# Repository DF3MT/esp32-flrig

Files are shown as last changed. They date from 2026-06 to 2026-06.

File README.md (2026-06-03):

<p align="center">
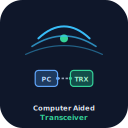
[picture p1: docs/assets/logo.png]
ESP32 Computer Aided Transceiver Panel
  
</p>

<h1 align="center">ESP32 CAT Remote Panel</h1>

<p align="center"><sub><strong><a href="https://en.wikipedia.org/wiki/Computer_Aided_Transceiver">CAT</a></strong> = <a href="https://en.wikipedia.org/wiki/Computer_Aided_Transceiver">Computer Aided Transceiver</a> (not Caterpillar)</sub></p>

<p align="center">
  <a href="#deutsch">🇩🇪 Deutsch</a> ·
  <a href="#english">🇬🇧 English</a>
</p>

<p align="center">
  <strong>DE:</strong> Funkfernbedienung mit Touch-Display, <a href="https://en.wikipedia.org/wiki/Computer_Aided_Transceiver">CAT</a>, <a href="https://de.wikipedia.org/wiki/WLAN">WiFi</a>-Audio, <a href="https://de.wikipedia.org/wiki/FT8_(Amateurfunk)">FT8</a> · bis zu <strong>3× Funk + <a href="https://de.wikipedia.org/wiki/Rotor_(Antenne)">Rotor</a></strong><br>
  <strong>EN:</strong> <a href="https://en.wikipedia.org/wiki/Amateur_radio">Ham radio</a> remote panel with touch UI, <a href="https://en.wikipedia.org/wiki/Computer_Aided_Transceiver">CAT</a>, <a href="https://en.wikipedia.org/wiki/Wi-Fi">WiFi</a> audio, <a href="https://en.wikipedia.org/wiki/FT8_(digital_mode)">FT8</a> · up to <strong>3× radios + <a href="https://en.wikipedia.org/wiki/Antenna_rotator">rotor</a></strong>
</p>

<p align="center">
  <a href="https://de.wikipedia.org/wiki/Icom">ICOM</a> <a href="https://de.wikipedia.org/wiki/CI-V">CI-V</a> · <a href="https://de.wikipedia.org/wiki/Yaesu">Yaesu</a> <a href="https://en.wikipedia.org/wiki/Computer_Aided_Transceiver">CAT</a> · <a href="https://www.xiegu.com/">Xiegu</a> · <a href="https://github.com/w1hkj/flrig">flrig</a> · <a href="https://physics.princeton.edu/pulsar/k1jt/wsjtx.html">WSJT-X</a> · <a href="https://en.wikipedia.org/wiki/Hamlib">Hamlib</a> <a href="https://hamlib.sourceforge.net/html/rigctld.1.html">rigctld</a> · <a href="https://hamlib.sourceforge.net/html/rotctld.1.html">rotctld</a>
</p>

<p align="center">
  <a href="#deutsch">📖 DE</a> ·
  <a href="#english">📖 EN</a> ·
  <a href="docs/GUIDE_DE.md">Leitfaden (DE)</a> ·
  <a href="hardware/esp32-flrig-shield/README.md">🛠️ PCB</a> ·
  <a href="docs/RADIOS.md">📻 Radios</a> ·
  <a href="docs/ISOLATION.md">🔌 Isolation</a> ·
  <a href="docs/MULTI_RADIO_DE.md">📡 3× DE</a> ·
  <a href="docs/MULTI_RADIO_EN.md">📡 3× EN</a> ·
  <a href="docs/GLOSSARY.md">📚 Glossar</a> ·
  <a href="flasher/index.html">⚡ Flasher</a>
</p>

<p align="center">
  
  
  
  
  
  
</p>

<p align="center">
  System overview
</p>

---

## Deutsch

### Was ist das?

Ein **[ESP32](https://de.wikipedia.org/wiki/ESP32)-Panel** (z. B. [Cheap Yellow Display](https://github.com/witnessmenow/ESP32-Cheap-Yellow-Display)) oder **[ESP32-S3](https://www.espressif.com/en/products/socs/esp32-s3) + Interface-Shield** steuert bis zu **drei [Funkgeräten](https://de.wikipedia.org/wiki/Transceiver) gleichzeitig** über **[WiFi](https://de.wikipedia.org/wiki/WLAN)**:

| Kanal | Anbindung | [CAT](https://en.wikipedia.org/wiki/Computer_Aided_Transceiver) → PC | Audio → PC (eigenes [UDP](https://de.wikipedia.org/wiki/User_Datagram_Protocol)-Paar) |
|---|---|---|---|
| **A** | [RJ45](https://de.wikipedia.org/wiki/RJ-45) / [I2S](https://de.wikipedia.org/wiki/I%C2%B2S) | `:4532` | `4533` / `4534` |
| **B** | [USB-A](https://de.wikipedia.org/wiki/USB) J5 | `:4536` | `4538` / `4539` |
| **C** | [USB](https://de.wikipedia.org/wiki/Universal_Serial_Bus)-A J6 | `:4540` | `4541` / `4542` |
| **[Rotor](https://de.wikipedia.org/wiki/Rotor_(Antenne))** | [GPIO](https://de.wikipedia.org/wiki/General_Purpose_Input/Output) | `:4535` | — |

Ideal für **[FT8](https://de.wikipedia.org/wiki/FT8_(Amateurfunk))/[WSJT-X](https://physics.princeton.edu/pulsar/k1jt/wsjtx.html)** am PC ohne [USB-Kabel](https://de.wikipedia.org/wiki/Universal_Serial_Bus) zum Funk. Shield **Rev C** trennt die **Masse jedes Funkgeräts [galvanisch](https://de.wikipedia.org/wiki/Galvanische_Trennung)** ([Isolation](docs/ISOLATION.md)).

**3 [Funkgeräte](https://de.wikipedia.org/wiki/Transceiver)** = am PC **3 parallele, unabhängige** Ketten (je ein [rigctld](https://hamlib.sourceforge.net/html/rigctld.1.html)-[TCP](https://de.wikipedia.org/wiki/Transmission_Control_Protocol)-Port + ein Audio-[UDP](https://de.wikipedia.org/wiki/User_Datagram_Protocol)-Paar + eigenes PC-Audiogerät, z. B. [VB-Cable](https://vb-audio.com/Cable/) A/B/C). Der ESP mischt die Streams **nicht**.

**[CAT](https://en.wikipedia.org/wiki/Computer_Aided_Transceiver)** = **[Computer Aided Transceiver](https://en.wikipedia.org/wiki/Computer_Aided_Transceiver)** (Steuerprotokoll, z. B. [CI-V](https://de.wikipedia.org/wiki/CI-V) / [Yaesu CAT](https://en.wikipedia.org/wiki/Computer_Aided_Transceiver)).

| PC-Instanz | [rigctld](https://hamlib.sourceforge.net/html/rigctld.1.html) ([CAT](https://en.wikipedia.org/wiki/Computer_Aided_Transceiver)) | Audio RX / TX ([UDP](https://de.wikipedia.org/wiki/User_Datagram_Protocol)) | Web |
|---|---|---|-----|
| Funk A | **4532** | **4533** / **4534** | `/audio` |
| Funk B | **4536** | **4538** / **4539** | `/audio_b` |
| Funk C | **4540** | **4541** / **4542** | `/audio_c` |
| [Rotor](https://de.wikipedia.org/wiki/Rotor_(Antenne)) | **4535** ([rotctld](https://hamlib.sourceforge.net/html/rotctld.1.html)) | — | — |

Details: [MULTI_RADIO_DE.md](docs/MULTI_RADIO_DE.md) · Beispiel-Konfig: [ft8_config.example-3radio.json](scripts/ft8_config.example-3radio.json)

### Unterstützte [Funkgeräte](https://de.wikipedia.org/wiki/Transceiver)

| Hersteller | Modelle |
|---|---|
| **[Xiegu](https://www.xiegu.com/)** | G90, [X6100](https://www.xiegu.com/), [X6200](https://www.xiegu.com/) |
| **[Yaesu](https://de.wikipedia.org/wiki/Yaesu)** | FT-991A, FT-910, FT-DX10, FT-DX101D/MP, FT-891, FT-897, FT-857 |
| Referenz | [ICOM](https://de.wikipedia.org/wiki/Icom) IC-7300 |

Profil in der Web-UI → Baudrate & Protokoll automatisch: [RADIOS.md](docs/RADIOS.md)

### Schnellstart

**Firmware (1× Funk, [CYD](https://github.com/witnessmenow/ESP32-Cheap-Yellow-Display)):**

```bash
pio run -e esp32-cyd -t upload
pio run -e esp32-cyd -t uploadfs
```

**Firmware (3× Funk + [Rotor](https://de.wikipedia.org/wiki/Rotor_(Antenne)), Shield Rev C + [ESP32-S3](https://www.espressif.com/en/products/socs/esp32-s3)):**

```bash
pio run -e esp32-flrig-shield -t upload
pio run -e esp32-flrig-shield -t uploadfs
```

Oder **[Web-Flasher](flasher/index.html)** im Browser.

| Modus | [SSID](https://de.wikipedia.org/wiki/Service_Set_Identifier) / IP | Konfiguration |
|---|---|---|
| AP (Werk) | `ESP32-CAT-Panel` / `192.168.4.1` | http://192.168.4.1/ |
| [WLAN](https://de.wikipedia.org/wiki/WLAN) | [DHCP](https://de.wikipedia.org/wiki/Dynamic_Host_Configuration_Protocol) | Funkprofil wählen |

**[CAT](https://en.wikipedia.org/wiki/Computer_Aided_Transceiver) testen ([Computer Aided Transceiver](https://en.wikipedia.org/wiki/Computer_Aided_Transceiver)):**

```bash
rigctl -m 2 -r 192.168.4.1:4532 f    # Funk A
rigctl -m 2 -r 192.168.4.1:4536 f    # Funk B
rigctl -m 2 -r 192.168.4.1:4540 f    # Funk C
rotctl -m 2 -r 192.168.4.1:4535 p    # Rotor
```

### [Rotor](https://de.wikipedia.org/wiki/Rotor_(Antenne)) ([Hamlib](https://en.wikipedia.org/wiki/Hamlib) [rotctld](https://hamlib.sourceforge.net/html/rotctld.1.html))

Zwei **Taster** (Azimut) und zwei **[Open-Collector](https://de.wikipedia.org/wiki/Offener_Kollektor)-Ausgänge** für Relais ([NPN](https://de.wikipedia.org/wiki/Bipolartransistor) + [Freilaufdiode](https://de.wikipedia.org/wiki/Freilaufdiode) extern).

| Richtung (`M`) | Wert | OC-[GPIO](https://de.wikipedia.org/wiki/General_Purpose_Input/Output) ([CYD](https://github.com/witnessmenow/ESP32-Cheap-Yellow-Display)) |
|---|---|---|
| Links (CCW) | 8 | **18** |
| Rechts (CW) | 16 | **19** |
| Taster CCW / CW | — | **27** / **5** |

`OUTPUT_OPEN_DRAIN`: **LOW** = Relais ein. Port **4535** (nicht 4533 — Audio-[UDP](https://de.wikipedia.org/wiki/User_Datagram_Protocol)).

### Interface-Shield (Dokumentation)

| Dokument | Inhalt |
|---|---|
| [Shield README](hardware/esp32-flrig-shield/README.md#deutsch) | Übersicht (DE/EN) |
| [Schaltplan](hardware/esp32-flrig-shield/docs/SCHEMATIC.md) | Logik, Isolation |
| [Kabel](hardware/esp32-flrig-shield/docs/CABLE_ASSEMBLY.md) | RJ45 / Funk |
| [RJ45-Pinout](hardware/esp32-flrig-shield/docs/RJ45_PINOUT.md) | Steckerbelegung |

### [FT8](https://de.wikipedia.org/wiki/FT8_(Amateurfunk)) / [WSJT-X](https://physics.princeton.edu/pulsar/k1jt/wsjtx.html)

```bash
pip install -r scripts/requirements-ft8.txt
cp scripts/ft8_config.example.json ~/.config/esp32-flrig/ft8.json
python3 scripts/ft8_setup.py --config ~/.config/esp32-flrig/ft8.json --test-cat --start
```

| OS | Skript |
|----|---|
| [Linux](https://de.wikipedia.org/wiki/Linux) | `./scripts/ft8_setup.sh 192.168.4.1 --pa --start` |
| [Windows](https://de.wikipedia.org/wiki/Microsoft_Windows) | `.\scripts\ft8_windows_setup.ps1 -EspHost 192.168.4.1 -InstallVbCable -StartBridge` |

### Hardware ([CYD](https://github.com/witnessmenow/ESP32-Cheap-Yellow-Display), Kanal A)

| Signal | [GPIO](https://de.wikipedia.org/wiki/General_Purpose_Input/Output) |
|---|---|
| [CAT](https://en.wikipedia.org/wiki/Computer_Aided_Transceiver) RX / TX | 16 / 17 |
| [I2S](https://de.wikipedia.org/wiki/I%C2%B2S) BCLK / LRCK | 26 / 25 |
| [I2S](https://de.wikipedia.org/wiki/I%C2%B2S) DOUT / DIN | 22 / 4 |
| [Potis](https://de.wikipedia.org/wiki/Potentiometer) 1–5 | 32, 35, 34, 39, 36 |
| [Rotor](https://de.wikipedia.org/wiki/Rotor_(Antenne)) Taster / OC | 27, 5 / 18, 19 |

### Weitere Dokumentation

| Thema | Link |
|---|---|
| Ausführlicher Leitfaden | [GUIDE_DE.md](docs/GUIDE_DE.md) (Deutsch) |
| [Hamlib](https://en.wikipedia.org/wiki/Hamlib) [rigctld](https://hamlib.sourceforge.net/html/rigctld.1.html) / [rotctld](https://hamlib.sourceforge.net/html/rotctld.1.html) | [rigctld](https://hamlib.sourceforge.net/html/rigctld.1.html) · [rotctld](https://hamlib.sourceforge.net/html/rotctld.1.html) |
| Audio-Monitor | http://\<ESP-IP\>/audio |

---

## English

### What is this?

An **[ESP32](https://en.wikipedia.org/wiki/ESP32) panel** (e.g. [Cheap Yellow Display](https://github.com/witnessmenow/ESP32-Cheap-Yellow-Display)) or **[ESP32-S3](https://www.espressif.com/en/products/socs/esp32-s3) + interface shield** controls up to **three [transceivers](https://en.wikipedia.org/wiki/Transceiver) at once** over **[WiFi](https://en.wikipedia.org/wiki/Wi-Fi)**:

| Channel | Connection | [CAT](https://en.wikipedia.org/wiki/Computer_Aided_Transceiver) → PC | Audio → PC (own [UDP](https://en.wikipedia.org/wiki/User_Datagram_Protocol) pair) |
|---|---|---|---|
| **A** | [RJ45](https://en.wikipedia.org/wiki/Registered_jack) / [I2S](https://en.wikipedia.org/wiki/I%C2%B2S) | `:4532` | `4533` / `4534` |
| **B** | [USB-A](https://en.wikipedia.org/wiki/USB) J5 | `:4536` | `4538` / `4539` |
| **C** | [USB](https://en.wikipedia.org/wiki/USB)-A J6 | `:4540` | `4541` / `4542` |
| **[Rotor](https://en.wikipedia.org/wiki/Antenna_rotator)** | [GPIO](https://en.wikipedia.org/wiki/General-purpose_input/output) | `:4535` | — |

Built for **[FT8](https://en.wikipedia.org/wiki/FT8_(digital_mode))/[WSJT-X](https://physics.princeton.edu/pulsar/k1jt/wsjtx.html)** on a PC without [USB cables](https://en.wikipedia.org/wiki/USB) to each radio. Shield **Rev C** uses **[galvanic isolation](https://en.wikipedia.org/wiki/Galvanic_isolation)** per radio ([ISOLATION.md](docs/ISOLATION.md)).

**3 radios** = on the PC **3 parallel, independent** chains (one [rigctld](https://hamlib.sourceforge.net/html/rigctld.1.html) [TCP](https://en.wikipedia.org/wiki/Transmission_Control_Protocol) port + one audio [UDP](https://en.wikipedia.org/wiki/User_Datagram_Protocol) pair + separate PC audio device each, e.g. [VB-Cable](https://vb-audio.com/Cable/) A/B/C). The ESP does **not** mix streams.

**[CAT](https://en.wikipedia.org/wiki/Computer_Aided_Transceiver)** = **[Computer Aided Transceiver](https://en.wikipedia.org/wiki/Computer_Aided_Transceiver)** (control protocol) — not construction equipment.

| PC instance | [rigctld](https://hamlib.sourceforge.net/html/rigctld.1.html) ([CAT](https://en.wikipedia.org/wiki/Computer_Aided_Transceiver)) | Audio RX / TX ([UDP](https://en.wikipedia.org/wiki/User_Datagram_Protocol)) | Web |
|---|---|---|-----|
| Radio A | **4532** | **4533** / **4534** | `/audio` |
| Radio B | **4536** | **4538** / **4539** | `/audio_b` |
| Radio C | **4540** | **4541** / **4542** | `/audio_c` |
| [Rotor](https://en.wikipedia.org/wiki/Antenna_rotator) | **4535** ([rotctld](https://hamlib.sourceforge.net/html/rotctld.1.html)) | — | — |

Details: [MULTI_RADIO_EN.md](docs/MULTI_RADIO_EN.md) · Example config: [ft8_config.example-3radio.json](scripts/ft8_config.example-3radio.json)

### Supported radios

| Vendor | Models |
|---|---|
| **[Xiegu](https://www.xiegu.com/)** | G90, X6100, X6200 |
| **[Yaesu](https://en.wikipedia.org/wiki/Yaesu_(brand))** | FT-991A, FT-910, FT-DX10, FT-DX101D/MP, FT-891, FT-897, FT-857 |
| Reference | [ICOM](https://en.wikipedia.org/wiki/Icom) IC-7300 |

Select a profile in the web UI: [RADIOS.md](docs/RADIOS.md)

### Quick start

**Firmware (single radio, [CYD](https://github.com/witnessmenow/ESP32-Cheap-Yellow-Display)):**

```bash
pio run -e esp32-cyd -t upload
pio run -e esp32-cyd -t uploadfs
```

**Firmware (3 radios + [rotor](https://en.wikipedia.org/wiki/Antenna_rotator), Shield Rev C + [ESP32-S3](https://www.espressif.com/en/products/socs/esp32-s3)):**

```bash
pio run -e esp32-flrig-shield -t upload
pio run -e esp32-flrig-shield -t uploadfs
```

Or the **[Web Flasher](flasher/index.html)** in your browser.

| Mode | [SSID](https://en.wikipedia.org/wiki/Service_set_(802.11_network)) / IP | Config |
|---|---|---|
| AP (default) | `ESP32-CAT-Panel` / `192.168.4.1` | http://192.168.4.1/ |
| [WiFi](https://en.wikipedia.org/wiki/Wi-Fi) STA | [DHCP](https://en.wikipedia.org/wiki/Dynamic_Host_Configuration_Protocol) | Select radio profile |

**Test [CAT](https://en.wikipedia.org/wiki/Computer_Aided_Transceiver) ([Computer Aided Transceiver](https://en.wikipedia.org/wiki/Computer_Aided_Transceiver)):**

```bash
rigctl -m 2 -r 192.168.4.1:4532 f    # Radio A
rigctl -m 2 -r 192.168.4.1:4536 f    # Radio B
rigctl -m 2 -r 192.168.4.1:4540 f    # Radio C
rotctl -m 2 -r 192.168.4.1:4535 p    # Rotor
```

### [Rotor](https://en.wikipedia.org/wiki/Antenna_rotator) ([Hamlib](https://en.wikipedia.org/wiki/Hamlib) [rotctld](https://hamlib.sourceforge.net/html/rotctld.1.html))

Two **buttons** (azimuth) and two **[open-collector](https://en.wikipedia.org/wiki/Open_collector)** outputs for relays (external [NPN](https://en.wikipedia.org/wiki/Bipolar_junction_transistor) + [flyback diode](https://en.wikipedia.org/wiki/Flyback_diode)).

| Direction (`M`) | Value | OC [GPIO](https://en.wikipedia.org/wiki/General-purpose_input/output) ([CYD](https://github.com/witnessmenow/ESP32-Cheap-Yellow-Display)) |
|---|---|---|
| Left (CCW) | 8 | **18** |
| Right (CW) | 16 | **19** |
| Buttons CCW / CW | — | **27** / **5** |

`OUTPUT_OPEN_DRAIN`: **LOW** = relay on. Port **4535** (not 4533 — audio [UDP](https://en.wikipedia.org/wiki/User_Datagram_Protocol)).

### Interface shield (documentation)

| Document | Content |
|---|---|
| [Shield README](hardware/esp32-flrig-shield/README.md#english) | Overview (DE/EN) |
| [Schematic](hardware/esp32-flrig-shield/docs/SCHEMATIC.md) | Logic, isolation |
| [Cables](hardware/esp32-flrig-shield/docs/CABLE_ASSEMBLY.md) | RJ45 / radio |
| [RJ45 pinout](hardware/esp32-flrig-shield/docs/RJ45_PINOUT.md) | Connector pins |

### [FT8](https://en.wikipedia.org/wiki/FT8_(digital_mode)) / [WSJT-X](https://physics.princeton.edu/pulsar/k1jt/wsjtx.html)

```bash
pip install -r scripts/requirements-ft8.txt
cp scripts/ft8_config.example.json ~/.config/esp32-flrig/ft8.json
python3 scripts/ft8_setup.py --config ~/.config/esp32-flrig/ft8.json --test-cat --start
```

| OS | Script |
|----|---|
| [Linux](https://en.wikipedia.org/wiki/Linux) | `./scripts/ft8_setup.sh 192.168.4.1 --pa --start` |
| [Windows](https://en.wikipedia.org/wiki/Microsoft_Windows) | `.\scripts\ft8_windows_setup.ps1 -EspHost 192.168.4.1 -InstallVbCable -StartBridge` |

### Hardware ([CYD](https://github.com/witnessmenow/ESP32-Cheap-Yellow-Display), channel A)

| Signal | [GPIO](https://en.wikipedia.org/wiki/General-purpose_input/output) |
|---|---|
| [CAT](https://en.wikipedia.org/wiki/Computer_Aided_Transceiver) RX / TX | 16 / 17 |
| [I2S](https://en.wikipedia.org/wiki/I%C2%B2S) BCLK / LRCK | 26 / 25 |
| [I2S](https://en.wikipedia.org/wiki/I%C2%B2S) DOUT / DIN | 22 / 4 |
| Pots 1–5 | 32, 35, 34, 39, 36 |
| [Rotor](https://en.wikipedia.org/wiki/Antenna_rotator) buttons / OC | 27, 5 / 18, 19 |

[CAT](https://en.wikipedia.org/wiki/Computer_Aided_Transceiver) on [CYD](https://github.com/witnessmenow/ESP32-Cheap-Yellow-Display): **3.3 V [TTL](https://en.wikipedia.org/wiki/Transistor%E2%80%93transistor_logic)**; on the shield **[ISO7741](https://www.ti.com/product/ISO7741)** isolates [RJ45](https://en.wikipedia.org/wiki/Registered_jack) [CAT](https://en.wikipedia.org/wiki/Computer_Aided_Transceiver) from ESP ground.

### Project layout

```
esp32-flrig/
├── docs/              Guides, radio list, isolation
├── hardware/esp32-flrig-shield/
│   ├── docs/          Schematic, cables, RJ45
│   └── assets/        Block diagram
├── scripts/           FT8 setup (Linux / Windows)
├── src/               Firmware
└── flasher/           Browser flasher
```

### Architecture

```
┌─────────────┐  rigctld :4532/4536/4540   ┌──────────────┐  isolated   ┌─────────┐
│ WSJT-X/flrig│◄──────────────────────────►│ ESP32 Panel  │◄───────────►│ 3× Radio│
└─────────────┘                            │ rotctld :4535│             └─────────┘
┌─────────────┐  rotctl                    │ WiFi audio   │
│ rotctl      │◄──────────────────────────►│ Touch + Web  │
└─────────────┘                            └──────────────┘
```

### More links

| Topic | Link |
|---|---|
| Full guide | [GUIDE_DE.md](docs/GUIDE_DE.md) (German) |
| [Hamlib](https://en.wikipedia.org/wiki/Hamlib) [rigctld](https://hamlib.sourceforge.net/html/rigctld.1.html) / [rotctld](https://hamlib.sourceforge.net/html/rotctld.1.html) | [rigctld](https://hamlib.sourceforge.net/html/rigctld.1.html) · [rotctld](https://hamlib.sourceforge.net/html/rotctld.1.html) |
| Audio monitor | http://\<ESP-IP\>/audio |

---

<p align="center">
  <sub>License: see repository · Contributions welcome · <a href="#deutsch">🇩🇪</a> · <a href="#english">🇬🇧</a></sub>
</p>

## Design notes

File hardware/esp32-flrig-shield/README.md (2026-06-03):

# ESP32-FLRIG Interface Shield

<p align="center">
  <a href="#deutsch">🇩🇪 Deutsch</a> ·
  <a href="#english">🇬🇧 English</a>
</p>

<p align="center">
  <sub><strong><a href="https://en.wikipedia.org/wiki/Computer_Aided_Transceiver">CAT</a></strong> = <a href="https://en.wikipedia.org/wiki/Computer_Aided_Transceiver">Computer Aided Transceiver</a></sub>
</p>

Blockdiagramm

---

## Deutsch

### Übersicht

Dokumentation für ein **Interface-Shield** zwischen **[ESP32-S3](https://www.espressif.com/en/products/socs/esp32-s3)** ([USB-Host](https://de.wikipedia.org/wiki/USB)) bzw. optional **[CYD](https://github.com/witnessmenow/ESP32-Cheap-Yellow-Display)** (nur Funk **Kanal A**) und bis zu **drei Funkgeräten**:

| Anschluss | Funktion |
|---|---|
| **J1 [RJ45](https://de.wikipedia.org/wiki/RJ-45)** | Funk **A**: +5 V, **[CAT](https://en.wikipedia.org/wiki/Computer_Aided_Transceiver)** ([UART](https://de.wikipedia.org/wiki/Asynchrone_Serielle_Schnittstelle)), **Line-Audio** |
| **J5 / J6** | **[USB-A](https://de.wikipedia.org/wiki/USB) Buchse** — Funk **B** und **C** ([CAT](https://en.wikipedia.org/wiki/Computer_Aided_Transceiver) + Audio per [USB](https://de.wikipedia.org/wiki/Universal_Serial_Bus)) |
| **U5 [USB2422](https://www.microchip.com/en-us/product/USB2422)** | 2-Port-Hub, Upstream **J3** → [ESP32-S3](https://www.espressif.com/en/products/socs/esp32-s3) OTG |
| **J7 / J3** | **[Rotor](https://de.wikipedia.org/wiki/Rotor_(Antenne))** (2× Taster, 2× [Open-Collector](https://de.wikipedia.org/wiki/Offener_Kollektor)) |
| **J2** | 2×10 für **[CYD](https://github.com/witnessmenow/ESP32-Cheap-Yellow-Display)** (Kanal A + [I2S](https://de.wikipedia.org/wiki/I%C2%B2S)) |

- **U1 [ISO7741](https://www.ti.com/product/ISO7741)** — [CAT](https://en.wikipedia.org/wiki/Computer_Aided_Transceiver) [galvanisch getrennt](https://de.wikipedia.org/wiki/Galvanische_Trennung) ([RJ45](https://de.wikipedia.org/wiki/RJ-45))  
- **U6/U7 [ADuM4160](https://www.analog.com/en/products/adum4160.html)** — [USB](https://de.wikipedia.org/wiki/Universal_Serial_Bus) [galvanisch](https://de.wikipedia.org/wiki/Galvanische_Trennung) getrennt (Funk B/C)  
- **T1/T2** — [Audio-Trafos](https://de.wikipedia.org/wiki/Transformator) (Funk A)  
- **[PCM5102](https://www.ti.com/product/PCM5102) + [INMP441](https://www.invensense.com/products/digital/inmp441/)** — [I2S](https://de.wikipedia.org/wiki/I%C2%B2S) (48 [kHz](https://de.wikipedia.org/wiki/Hertz))  

**3× Funk + 1× [Rotor](https://de.wikipedia.org/wiki/Rotor_(Antenne))** über **[WiFi](https://de.wikipedia.org/wiki/WLAN)**. **Keine gemeinsame Masse** zwischen den [Funkgeräten](https://de.wikipedia.org/wiki/Transceiver): [Isolation](../../docs/ISOLATION.md).

**Am PC:** drei getrennte [rigctld](https://hamlib.sourceforge.net/html/rigctld.1.html)-Verbindungen und drei Audio-[UDP](https://de.wikipedia.org/wiki/User_Datagram_Protocol)-Paare — siehe [MULTI_RADIO_DE.md](../../docs/MULTI_RADIO_DE.md).

### Dokumentation

| Thema | Datei |
|---|---|
| Logischer Schaltplan | [SCHEMATIC.md](docs/SCHEMATIC.md) |
| Kabel / RJ45 | [CABLE_ASSEMBLY.md](docs/CABLE_ASSEMBLY.md) · [RJ45_PINOUT.md](docs/RJ45_PINOUT.md) |
| Isolation | [ISOLATION.md](../../docs/ISOLATION.md) |

### Firmware

```bash
pio run -t upload -e esp32-flrig-shield
pio run -t uploadfs -e esp32-flrig-shield
```

### [Rotor](https://de.wikipedia.org/wiki/Rotor_(Antenne)) ([GPIO](https://de.wikipedia.org/wiki/General_Purpose_Input/Output))

| J7 / J3 | [GPIO](https://de.wikipedia.org/wiki/General_Purpose_Input/Output) (S3-Default) |
|---|---|
| Taster CCW | 27 |
| Taster CW | 5 |
| [Open Collector](https://de.wikipedia.org/wiki/Offener_Kollektor) CCW | 18 |
| [Open Collector](https://de.wikipedia.org/wiki/Offener_Kollektor) CW | 19 |

**[rotctld](https://hamlib.sourceforge.net/html/rotctld.1.html)** Port **4535**.

### Dateien

```
esp32-flrig-shield/
├── docs/     Schaltplan, Kabel, RJ45
└── assets/   Blockdiagramm (SVG)
```

---

## English

### Overview

Documentation for an **interface shield** between **[ESP32-S3](https://www.espressif.com/en/products/socs/esp32-s3)** ([USB host](https://en.wikipedia.org/wiki/USB)) or optionally **[CYD](https://github.com/witnessmenow/ESP32-Cheap-Yellow-Display)** (radio **channel A** only) and up to **three radios**:

| Connector | Function |
|---|---|
| **J1 [RJ45](https://en.wikipedia.org/wiki/Registered_jack)** | Radio **A**: +5 V, **[CAT](https://en.wikipedia.org/wiki/Computer_Aided_Transceiver)** ([UART](https://en.wikipedia.org/wiki/Universal_asynchronous_receiver-transmitter)), line audio |
| **J5 / J6** | **[USB Type-A](https://en.wikipedia.org/wiki/USB)** — radios **B** and **C** |
| **U5 [USB2422](https://www.microchip.com/en-us/product/USB2422)** | 2-port hub, upstream **J3** → [ESP32-S3](https://www.espressif.com/en/products/socs/esp32-s3) OTG |
| **J7 / J3** | **[Rotor](https://en.wikipedia.org/wiki/Antenna_rotator)** (2× buttons, 2× [open-collector](https://en.wikipedia.org/wiki/Open_collector)) |
| **J2** | 2×10 header for **[CYD](https://github.com/witnessmenow/ESP32-Cheap-Yellow-Display)** |

See [ISOLATION.md](../../docs/ISOLATION.md) and [MULTI_RADIO_EN.md](../../docs/MULTI_RADIO_EN.md).

### Documentation

| Topic | File |
|---|---|
| Logical schematic | [SCHEMATIC.md](docs/SCHEMATIC.md) |
| Cables / RJ45 | [CABLE_ASSEMBLY.md](docs/CABLE_ASSEMBLY.md) · [RJ45_PINOUT.md](docs/RJ45_PINOUT.md) |

### Firmware

```bash
pio run -t upload -e esp32-flrig-shield
pio run -t uploadfs -e esp32-flrig-shield
```

### [Rotor](https://en.wikipedia.org/wiki/Antenna_rotator) ([GPIO](https://en.wikipedia.org/wiki/General-purpose_input/output))

| J7 / J3 | GPIO (S3 default) |
|---|---|
| Button CCW | 27 |
| Button CW | 5 |
| [Open collector](https://en.wikipedia.org/wiki/Open_collector) CCW | 18 |
| [Open collector](https://en.wikipedia.org/wiki/Open_collector) CW | 19 |

**[rotctld](https://hamlib.sourceforge.net/html/rotctld.1.html)** port **4535**.

---

<p align="center">
  <sub><a href="#deutsch">🇩🇪</a> · <a href="#english">🇬🇧</a> · <a href="../../README.md">Project README</a></sub>
</p>

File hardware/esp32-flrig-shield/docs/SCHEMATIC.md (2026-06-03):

# Schaltplan — [ESP32](https://de.wikipedia.org/wiki/ESP32)-FLRIG Interface Shield (Rev C)

Logischer Schaltplan (Konzept — keine KiCad-/Gerber-Dateien im Repository).

Blockdiagramm

**Rev C** = Rev B + **galvanische Trennung** zwischen allen Funk-Massebereichen ([`../../../docs/ISOLATION.md`](../../../docs/ISOLATION.md)).

**[CAT](https://en.wikipedia.org/wiki/Computer_Aided_Transceiver)** = **[Computer Aided Transceiver](https://en.wikipedia.org/wiki/Computer_Aided_Transceiver)** (Steuerprotokoll), nicht „Caterpillar“.

## Masse-Domänen (kein gemeinsamer GND-Kupfer!)

| Netz | Verbindung |
|---|---|
| **GND_ESP** | [ESP32-S3](https://www.espressif.com/en/products/socs/esp32-s3)/[CYD](https://github.com/witnessmenow/ESP32-Cheap-Yellow-Display), U5 Hub Upstream, U1/U6/U7 Primärseite, [I2S](https://de.wikipedia.org/wiki/I%C2%B2S)-Module ESP-Seite |
| **GND_RADIO_A** | [RJ45](https://de.wikipedia.org/wiki/RJ-45) Pin 2/7, U1 Sekundärseite, T1/T2 Funk-Seite |
| **GND_USB_B** | J5 Shield/GND, U6 Sekundärseite, U8 DC/DC Ausgang |
| **GND_USB_C** | J6 Shield/GND, U7 Sekundärseite, U9 DC/DC Ausgang |

Zwischen diesen Netzen nur **Isolatoren** (und optional HF-RC am [RJ45](https://de.wikipedia.org/wiki/RJ-45)-Shield).

## Gesamtübersicht

```
                    ┌── GND_ESP ──────────────────────────────┐
Funk A RJ45 ── U1 ISO7741 ── CAT UART    T1/T2 ── AF (nur über Trafos)
     GND_RADIO_A (isoliert)                │
Funk B J5 ──── U6 ADuM4160 ◄── U5 Hub Down1 ── ESP USB OTG
     GND_USB_B + U8 B0505S VBUS
Funk C J6 ──── U7 ADuM4160 ◄── U5 Hub Down2
     GND_USB_C + U9 B0505S VBUS
Rotor J7 ───── direkt GPIO (gemeinsame ESP-Masse, kein Funk-GND)
```

## Funk A — [CAT](https://en.wikipedia.org/wiki/Computer_Aided_Transceiver) ([Computer Aided Transceiver](https://en.wikipedia.org/wiki/Computer_Aided_Transceiver))

**U1 [ISO7741](https://www.ti.com/product/ISO7741)** (ersetzt [TXS0102](https://www.ti.com/product/TXS0102) — kein reiner [Pegelwandler](https://de.wikipedia.org/wiki/Pegelwandler) mehr):

```
GPIO16/17 (ESP) ── ISO7741 Seite A ──║── Seite B ── RJ45 Pin 3/4 (CAT TTL Funk)
+3V3_ESP              GND_ESP          GND_RADIO_A      +5V_RADIO (RJ45 Pin1, lokaler Bezug)
```

Optional **5 V ↔ 3,3 V** auf **Funk-Seite** nur für kompatible Pegel — **ohne** GND-Brücke zur ESP-Masse.

## Funk A — Audio ([galvanisch getrennt](https://de.wikipedia.org/wiki/Galvanische_Trennung))

```
PCM5102 / INMP441 (ESP-Seite, GND_ESP) ── T1/T2 1:1 Audio-Trafo ── RJ45 Pin 5/6
```

Kein direkter DC-Pfad AF_IN/AF_OUT zwischen [I2S](https://de.wikipedia.org/wiki/I%C2%B2S)-Modulen und [RJ45](https://de.wikipedia.org/wiki/RJ-45).

## [USB](https://de.wikipedia.org/wiki/Universal_Serial_Bus) Funk B / C

```
ESP USB OTG ── U5 USB2422 (nur GND_ESP)
                 ├── Down1 ── U6 ADuM4160 ── J5 (USB-A)  GND_USB_B
                 └── Down2 ── U7 ADuM4160 ── J6 (USB-A)  GND_USB_C
U8/U9: isoliertes DC/DC (z. B. B0505S) +5V_BUS → VBUS je Port (Sekundär getrennt)
```

**Wichtig:** J5- und J6-**Masse nicht** mit [RJ45](https://de.wikipedia.org/wiki/RJ-45)-Masse oder ESP-Masse verbinden.

## Stromversorgung

- **+5V_BUS**: ESP-Shield / externes Netzteil (GND_REF = **GND_ESP** nur).
- **[RJ45](https://de.wikipedia.org/wiki/RJ-45) Pin 1**: bevorzugt nur **Funk-A-Sekundär** (Isolator, Trafos) — nicht als Rückleiter für [USB](https://de.wikipedia.org/wiki/Universal_Serial_Bus)-B/C.
- **≥2 A** empfohlen, wenn zwei isolierte [USB](https://de.wikipedia.org/wiki/Universal_Serial_Bus)-Ports laden.

## [Rotor](https://de.wikipedia.org/wiki/Rotor_(Antenne))

J7 → J3 [GPIO](https://de.wikipedia.org/wiki/General_Purpose_Input/Output) (Taster + OC). [Rotor](https://de.wikipedia.org/wiki/Rotor_(Antenne))-Relais-Masse **extern** mit eigenem Netzteil; **nicht** mit Funk-B/C-Masse verbunden, wenn Brummen vermieden werden soll.

## [RJ45](https://de.wikipedia.org/wiki/RJ-45) — Netzliste (Funk A, isoliert)

| [RJ45](https://de.wikipedia.org/wiki/RJ-45) | Netz |
|---|---|
| 1 | +5V_RADIO_A |
| 2 | GND_RADIO_A |
| 3 | CAT_TX_RADIO (nach U1) |
| 4 | CAT_RX_RADIO (nach U1) |
| 5 | AF_IN (nach T1) |
| 6 | AF_OUT (nach T2) |
| 7 | GND_RADIO_A |
| 8 | NC |

## [BOM](https://de.wikipedia.org/wiki/St%C3%BCckliste) Rev C

Kernbauteile: **U1 [ISO7741](https://www.ti.com/product/ISO7741)**, **U6/U7 [ADuM4160](https://www.analog.com/en/products/adum4160.html)**, **U8/U9 [B0505S](https://en.wikipedia.org/wiki/DC-to-DC_converter)**, **T1/T2 [Audio-Trafo](https://de.wikipedia.org/wiki/Transformator)**, **U5 [USB2422](https://www.microchip.com/en-us/product/USB2422)**, **U2 AMS1117**, **U3/U4** [I2S](https://de.wikipedia.org/wiki/I%C2%B2S)-Module.

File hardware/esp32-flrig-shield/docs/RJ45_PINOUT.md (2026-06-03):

# [RJ45](https://de.wikipedia.org/wiki/RJ-45) Pinbelegung — [ESP32](https://de.wikipedia.org/wiki/ESP32)-FLRIG-1

Ein **8-poliges Cat-5e/Cat-6-Kabel** (oder fertiges Patchkabel mit abisolierten Adern am Funk-Ende) verbindet die **Interface-Platine** am [ESP32](https://de.wikipedia.org/wiki/ESP32) mit einer **Aufschaltbox am [Funkgerät](https://de.wikipedia.org/wiki/Transceiver)** ([CAT](https://en.wikipedia.org/wiki/Computer_Aided_Transceiver) + Audio + optional Strom).

## Steckerbelegung (Buchse auf [PCB](https://de.wikipedia.org/wiki/Leiterplatte), Blick auf Kontakte, Kabel abgehend)

| Pin | Farbe (T568B) | Signal | Richtung | Beschreibung |
|-----|---|---|---|---|
| 1 | orange/weiß | **+5V** | → Platine | Versorgung (max. **500 mA**), [Polyfuse](https://de.wikipedia.org/wiki/Polymer-Schmelzsicherung) auf [PCB](https://de.wikipedia.org/wiki/Leiterplatte) |
| 2 | orange | **GND** | — | Masse Hauptstrom |
| 3 | grün/weiß | **CAT_TX_RADIO** | Radio → ESP | [TTL](https://de.wikipedia.org/wiki/Transistor-Transistor-Logik) vom Funk (5 V), über [Level-Shifter](https://de.wikipedia.org/wiki/Pegelwandler) zu GPIO16 RX |
| 4 | grün | **CAT_RX_RADIO** | ESP → Radio | [TTL](https://de.wikipedia.org/wiki/Transistor-Transistor-Logik) zum Funk (5 V), von GPIO17 TX über Shifter |
| 5 | blau/weiß | **AF_IN** | Radio → Platine | Empfangs-Audio (Line-Out Funk), AC-gekoppelt |
| 6 | blau | **AF_OUT** | Platine → Radio | Sende-Audio (Line-In / Data-In Funk), AC-gekoppelt |
| 7 | braun/weiß | **GND_AUDIO** | — | Audio-Referenz (mit Pin 2 auf Funkseite verbinden) |
| 8 | braun | **NC** | — | Reserve (z. B. später [PTT](https://de.wikipedia.org/wiki/Sende-Empfang-Umschaltung) oder +5V-Sense) |

> **Wichtig:** Das ist **kein** Ethernet-Port. Kein Netzwerk-Switch anschließen.

## Signalübersicht

```
                    RJ45-Kabel (ESP32-FLRIG-1)
  ┌─────────────┐                              ┌──────────────────┐
  │  Shield PCB │  Pin1 +5V ──────────────────│ 5V (ACC/USB/Netzteil)│
  │  + CYD      │  Pin2 GND ──────────────────│ GND                │
  │             │  Pin3 ◄── CAT_TX (Funk)     │ CAT Buchse RX/TX   │
  │             │  Pin4 ──► CAT_RX (Funk)     │                    │
  │             │  Pin5 ◄── Line OUT Funk     │ 3,5 mm Line Out    │
  │             │  Pin6 ──► Line IN Funk      │ 3,5 mm Line/Data In│
  └─────────────┘  Pin7 GND Audio ────────────└──────────────────┘
```

## [CAT](https://en.wikipedia.org/wiki/Computer_Aided_Transceiver) [TTL](https://de.wikipedia.org/wiki/Transistor-Transistor-Logik)

- **Kreuzverdrahtung** auf der Funk-Seite: Pin 3 = Funk-TX → ESP empfängt; Pin 4 = Funk-RX ← ESP sendet.
- Pegel: **5 V [TTL](https://de.wikipedia.org/wiki/Transistor-Transistor-Logik)** am Funk; auf der Platine **[TXS0102](https://www.ti.com/product/TXS0102)** (3,3 V ↔ 5 V).

## Audio

- Pegel: **Line-Level** (~0,1–1,5 Vpp), nicht Lautsprecher-Taps.
- Auf der Platine: Trennkondensatoren 10 µF, Spannungsteiler zum [I2S](https://de.wikipedia.org/wiki/I%C2%B2S)-ADC; DAC-Ausgang über 10 µF + optional 1 kΩ Reihenwiderstand.
- **Mono** (nur Pin 5/6); Stereo-[Funkgeräte](https://de.wikipedia.org/wiki/Transceiver): L-Kanal verwenden, R über 7 auf GND.

## Stromversorgung

| Variante | Hinweis |
|---|---|
| **A** | Pin 1/2 von **5 V am Funk** (ACC, [USB](https://de.wikipedia.org/wiki/Universal_Serial_Bus)-Port mit 500 mA) |
| **B** | Separates **5 V Netzteil** nur am [RJ45](https://de.wikipedia.org/wiki/RJ-45) (Funkseite Pins 3–8 trotzdem verbunden) |
| **C** | Zusätzlich **[USB](https://de.wikipedia.org/wiki/Universal_Serial_Bus)-C am [CYD](https://github.com/witnessmenow/ESP32-Cheap-Yellow-Display)** nur zum Flashen (nicht gleichzeitig mit externem 5 V auf Pin 1 ohne Diode) |

Empfehlung auf [PCB](https://de.wikipedia.org/wiki/Leiterplatte): **[Schottky](https://de.wikipedia.org/wiki/Schottky-Diode) D1** ([USB](https://de.wikipedia.org/wiki/Universal_Serial_Bus) 5 V OR extern 5 V) — siehe Schaltplan.

## Empfohlenes Kabel

- **Am Panel:** abgeschirmtes [RJ45](https://de.wikipedia.org/wiki/RJ-45)-Patchkabel (≤ 3 m).
- **Am Funk:** eigene **Verteilerdose** oder **Gehäuse** mit:
  - 1× [RJ45](https://de.wikipedia.org/wiki/RJ-45) Buchse
  - 1× [CAT](https://en.wikipedia.org/wiki/Computer_Aided_Transceiver)-Stecker (3,5 mm TRS oder 6P6C je nach Gerät)
  - 2× 3,5 mm mono oder 1× stereo für Audio
  - Beschriftung nach Tabelle oben

Siehe [CABLE_ASSEMBLY.md](CABLE_ASSEMBLY.md) für Schritt-für-Schritt Lötanleitung der Funk-Seite.

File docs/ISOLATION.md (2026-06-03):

# Galvanic isolation between transceivers

[Deutsch](#deutsch) · [English](#english)

Switching between radios must **not** create a shared, low-impedance ground path between rigs (ground loops, hum, CAT errors). Shield **Rev C** uses **separate ground domains** linked only through isolators.

## Deutsch

### Problem

Ohne Trennung sind **[ESP32](https://de.wikipedia.org/wiki/ESP32)-Masse**, **Funk-A-Masse** ([RJ45](https://de.wikipedia.org/wiki/RJ-45)), **[USB](https://de.wikipedia.org/wiki/Universal_Serial_Bus)-B-Masse** und **[USB](https://de.wikipedia.org/wiki/Universal_Serial_Bus)-C-Masse** über Kabel und Shield verbunden → **Brummen**, falsche [CAT](https://en.wikipedia.org/wiki/Computer_Aided_Transceiver)-Bytes, [USB](https://de.wikipedia.org/wiki/Universal_Serial_Bus)-Abbrüche beim Wechsel zwischen mehreren Geräten.

### Lösung (Rev C)

| Pfad | [CAT](https://en.wikipedia.org/wiki/Computer_Aided_Transceiver) ([Computer Aided Transceiver](https://en.wikipedia.org/wiki/Computer_Aided_Transceiver)) | Audio | Masse |
|---|---|---|---|
| **Funk A** ([RJ45](https://de.wikipedia.org/wiki/RJ-45)) | **U1 [ISO7741](https://www.ti.com/product/ISO7741)** ([UART](https://de.wikipedia.org/wiki/Asynchrone_Serielle_Schnittstelle) digital isolator) | **T1/T2** [Audio-Trafos](https://de.wikipedia.org/wiki/Transformator) 1:1 | **GND_RADIO_A** ≠ GND_ESP |
| **Funk B** (J5) | **U6 [ADuM4160](https://www.analog.com/en/products/adum4160.html)** ([USB](https://de.wikipedia.org/wiki/Universal_Serial_Bus) isolator) | im [USB](https://de.wikipedia.org/wiki/Universal_Serial_Bus) (UAC) | **GND_USB_B** |
| **Funk C** (J6) | **U7 [ADuM4160](https://www.analog.com/en/products/adum4160.html)** | im [USB](https://de.wikipedia.org/wiki/Universal_Serial_Bus) (UAC) | **GND_USB_C** |
| **[ESP32-S3](https://www.espressif.com/en/products/socs/esp32-s3)** | — | [I2S](https://de.wikipedia.org/wiki/I%C2%B2S) nur ESP-Seite der Trafos | **GND_ESP** |

- **Kein** direkter Kupferverbund zwischen `GND_RADIO_A`, `GND_USB_B`, `GND_USB_C` und `GND_ESP`.
- **[USB2422](https://www.microchip.com/en-us/product/USB2422) (U5)** sitzt nur auf der **ESP-Seite**; je Downstream-Port ein **eigener [ADuM4160](https://www.analog.com/en/products/adum4160.html)** + **isoliertes DC/DC (U8/U9)** für [VBUS](https://de.wikipedia.org/wiki/Universal_Serial_Bus).
- [RJ45](https://de.wikipedia.org/wiki/RJ-45) **Pin 2/7** → `GND_RADIO_A` (nicht ESP-Masse). Gehäuse über **RC** (z. B. 1 nF + 1 MΩ) optional zu Funk-Masse, nicht hart zu ESP.
- **+5 V**: getrennte Versorgung empfohlen — ESP über eigenes [USB](https://de.wikipedia.org/wiki/Universal_Serial_Bus)/[WiFi](https://de.wikipedia.org/wiki/WLAN)-Board; Funk A +5 V nur für isolierte Sekundärseite / Trafos.

### Wechsel zwischen [Funkgeräten](https://de.wikipedia.org/wiki/Transceiver)

Firmware schaltet **logisch** ([rigctld](https://hamlib.sourceforge.net/html/rigctld.1.html)-Kanal, [USB](https://de.wikipedia.org/wiki/Universal_Serial_Bus)-Index). **Elektrisch** bleiben die Massefelder getrennt — kein Relais, das GNDs zusammenlegt.

### Dokumentation Hardware

- [SCHEMATIC.md](../hardware/esp32-flrig-shield/docs/SCHEMATIC.md) (Netze / Blöcke)
- [CABLE_ASSEMBLY.md](../hardware/esp32-flrig-shield/docs/CABLE_ASSEMBLY.md) (Verkabelung)

## English

### Issue

Without isolation, **ESP ground**, **radio A ground** ([RJ45](https://en.wikipedia.org/wiki/Registered_jack)), and **[USB](https://en.wikipedia.org/wiki/USB) B/C grounds** are tied through cables and shields → **[ground loops](https://en.wikipedia.org/wiki/Ground_loop_(electricity))**, hum, [CAT](https://en.wikipedia.org/wiki/Computer_Aided_Transceiver) corruption when multiple rigs are connected.

### Solution (Rev C)

| Path | [CAT](https://en.wikipedia.org/wiki/Computer_Aided_Transceiver) ([Computer Aided Transceiver](https://en.wikipedia.org/wiki/Computer_Aided_Transceiver)) | Audio | Ground |
|---|---|---|---|
| **Radio A** ([RJ45](https://en.wikipedia.org/wiki/Registered_jack)) | **U1 [ISO7741](https://www.ti.com/product/ISO7741)** digital isolator | **T1/T2** 1:1 [audio transformers](https://en.wikipedia.org/wiki/Transformer) | **GND_RADIO_A** ≠ GND_ESP |
| **Radio B** (J5) | **U6 [ADuM4160](https://www.analog.com/en/products/adum4160.html)** [USB](https://en.wikipedia.org/wiki/USB) isolator | via [USB UAC](https://en.wikipedia.org/wiki/USB_audio_device_class) | **GND_USB_B** |
| **Radio C** (J6) | **U7 [ADuM4160](https://www.analog.com/en/products/adum4160.html)** | via [USB UAC](https://en.wikipedia.org/wiki/USB_audio_device_class) | **GND_USB_C** |
| **[ESP32-S3](https://www.espressif.com/en/products/socs/esp32-s3)** | — | [I2S](https://en.wikipedia.org/wiki/I%C2%B2S) on ESP side of transformers only | **GND_ESP** |

- **No** direct copper between radio/[USB](https://en.wikipedia.org/wiki/USB) grounds and ESP ground.
- **[USB2422](https://www.microchip.com/en-us/product/USB2422)** on ESP side only; **one [ADuM4160](https://www.analog.com/en/products/adum4160.html) per** [USB-A](https://en.wikipedia.org/wiki/USB) port plus **isolated DC/DC** for [VBUS](https://en.wikipedia.org/wiki/USB).
- [RJ45](https://en.wikipedia.org/wiki/Registered_jack) pins **2/7** → `GND_RADIO_A` only.
- Prefer **separate** +5 V feeds: ESP from its module; radio A +5 V for isolated secondary only.

### [CAT](https://en.wikipedia.org/wiki/Computer_Aided_Transceiver) acronym

**[CAT](https://en.wikipedia.org/wiki/Computer_Aided_Transceiver)** = **[Computer Aided Transceiver](https://en.wikipedia.org/wiki/Computer_Aided_Transceiver)** ([ICOM](https://en.wikipedia.org/wiki/Icom)/[Yaesu](https://en.wikipedia.org/wiki/Yaesu_(brand)) control protocol), not related to any construction-equipment brand.

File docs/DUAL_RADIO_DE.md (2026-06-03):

# Zwei [Funkgeräte](https://de.wikipedia.org/wiki/Transceiver) gleichzeitig ([CAT](https://en.wikipedia.org/wiki/Computer_Aided_Transceiver) + Audio)

> **3× Funk + [Rotor](https://de.wikipedia.org/wiki/Rotor_(Antenne)) (Shield Rev B):** siehe [MULTI_RADIO_DE.md](MULTI_RADIO_DE.md)

## Übersicht

| Build | Hardware | [CAT](https://en.wikipedia.org/wiki/Computer_Aided_Transceiver) | Audio |
|---|---|-----|---|
| `esp32-cyd` | [CYD](https://github.com/witnessmenow/ESP32-Cheap-Yellow-Display) / Shield [RJ45](https://de.wikipedia.org/wiki/RJ-45) | 1× [UART](https://de.wikipedia.org/wiki/Asynchrone_Serielle_Schnittstelle) | 1× [I2S](https://de.wikipedia.org/wiki/I%C2%B2S) |
| `esp32-cyd-dual` | [CYD](https://github.com/witnessmenow/ESP32-Cheap-Yellow-Display) + 2. [UART](https://de.wikipedia.org/wiki/Asynchrone_Serielle_Schnittstelle) (GPIO5/18) | 2× [UART](https://de.wikipedia.org/wiki/Asynchrone_Serielle_Schnittstelle) | 2× [I2S](https://de.wikipedia.org/wiki/I%C2%B2S) (GPIO12–15) |
| `esp32-s3-dual-usb` | [ESP32-S3](https://www.espressif.com/en/products/socs/esp32-s3) + **Powered [USB-Hub](https://de.wikipedia.org/wiki/USB-Hub)** | 2× [USB-CDC](https://de.wikipedia.org/wiki/USB_Communications_Device_Class) | 2× [USB-UAC](https://de.wikipedia.org/wiki/USB-Audioklasse) (geplant) oder [I2S](https://de.wikipedia.org/wiki/I%C2%B2S) |

[Hamlib](https://en.wikipedia.org/wiki/Hamlib) pro Funk:

- **A:** `rigctl -m 2 -r <IP>:4532` · Audio [UDP](https://de.wikipedia.org/wiki/User_Datagram_Protocol) 4533/4534 · Web `/audio`
- **B:** `rigctl -m 2 -r <IP>:4536` · Audio [UDP](https://de.wikipedia.org/wiki/User_Datagram_Protocol) 4538/4539 · Web `/audio_b`

[Rotor](https://de.wikipedia.org/wiki/Rotor_(Antenne)) unverändert: `rotctld` Port **4535**.

## [USB](https://de.wikipedia.org/wiki/Universal_Serial_Bus) am [ESP32](https://de.wikipedia.org/wiki/ESP32) (S3)

Der **[ESP32](https://de.wikipedia.org/wiki/ESP32) ([CYD](https://github.com/witnessmenow/ESP32-Cheap-Yellow-Display))** hat keinen [USB-Host](https://de.wikipedia.org/wiki/Universal_Serial_Bus) – nur [USB-Serial](https://de.wikipedia.org/wiki/USB_Communications_Device_Class) zum PC ([CH340](https://de.wikipedia.org/wiki/USB-UART-Bridge)).

Für **2× Funk per [USB-Kabel](https://de.wikipedia.org/wiki/USB)** (volles [CAT](https://en.wikipedia.org/wiki/Computer_Aided_Transceiver) + [USB-Audio](https://de.wikipedia.org/wiki/USB-Audioklasse) des Geräts):

1. Board **[ESP32-S3](https://www.espressif.com/en/products/socs/esp32-s3)** mit OTG (z. B. S3-DevKitC-1 + OTG-Adapter).
2. **Aktiver [USB-2.0](https://de.wikipedia.org/wiki/Universal_Serial_Bus)-Hub** mit Netzteil (Strom für 2× Funk).
3. Firmware: `pio run -t upload -e esp32-s3-dual-usb`
4. In `config.json` pro Kanal: `"cat_link":"usb"`, `"audio_link":"usb"`, `"usb_index":0` bzw. `1`.

[USB](https://de.wikipedia.org/wiki/Universal_Serial_Bus)-CDC-Host-Treiber ist vorbereitet (`usb_cat_host.cpp`); nach Attach erscheinen die [CAT](https://en.wikipedia.org/wiki/Computer_Aided_Transceiver)-Ports. **[USB-Audio](https://de.wikipedia.org/wiki/USB-Audioklasse) (UAC)** folgt im gleichen Host-Stack – bis dahin Audio über Shield-[I2S](https://de.wikipedia.org/wiki/I%C2%B2S)/[RJ45](https://de.wikipedia.org/wiki/RJ-45) oder [WiFi](https://de.wikipedia.org/wiki/WLAN)-[UDP](https://de.wikipedia.org/wiki/User_Datagram_Protocol).

## Konfiguration (`radios[]`)

```json
"radios": [
  {
    "enabled": true,
    "label": "A",
    "radio_model": "G90",
    "cat_link": "uart",
    "audio_link": "i2s",
    "audio_enabled": true,
    "rigctld_port": 4532,
    "audio_port_out": 4533,
    "audio_port_in": 4534
  },
  {
    "enabled": true,
    "label": "B",
    "radio_model": "FT-991A",
    "cat_link": "usb",
    "audio_link": "usb",
    "usb_index": 1,
    "rigctld_port": 4536,
    "audio_port_out": 4538,
    "audio_port_in": 4539
  }
]
```

Legacy-Felder (`radio_model`, `audio_enabled`, …) spiegeln weiterhin **Kanal A**.

## [WSJT-X](https://physics.princeton.edu/pulsar/k1jt/wsjtx.html) / [FT8](https://de.wikipedia.org/wiki/FT8_(Amateurfunk)) (2 Rigs)

Zwei Instanzen oder Multi-Instance: jeweils eigenes `rigctl`-Host/Port und Audio-[UDP](https://de.wikipedia.org/wiki/User_Datagram_Protocol)-Paar (4533/4534 und 4538/4539). Siehe `scripts/ft8_setup.py` – zweites Profil mit Port 4536 ergänzen.

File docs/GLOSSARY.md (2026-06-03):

# Glossar / Glossary — verlinkte Fachbegriffe

<p align="center">
  <a href="#deutsch">🇩🇪 Deutsch</a> ·
  <a href="#english">🇬🇧 English</a>
</p>

In der Projekt-Dokumentation sind Begriffe mit **passendem Kontext** verlinkt (Wikipedia, Hersteller, Hamlib, …).  
**CAT** = [Computer Aided Transceiver](https://en.wikipedia.org/wiki/Computer_Aided_Transceiver) (Amateurfunk-Steuerung) — nicht Caterpillar.

---

## Deutsch

| Begriff | Kurz | Quelle |
|---|---|---|
| **[CAT](https://en.wikipedia.org/wiki/Computer_Aided_Transceiver)** | [Computer Aided Transceiver](https://en.wikipedia.org/wiki/Computer_Aided_Transceiver) | [Wikipedia EN](https://en.wikipedia.org/wiki/Computer_Aided_Transceiver) · [CI-V](https://de.wikipedia.org/wiki/CI-V) ([ICOM](https://de.wikipedia.org/wiki/Icom)) |
| **[CI-V](https://de.wikipedia.org/wiki/CI-V)** | [ICOM](https://de.wikipedia.org/wiki/Icom)-Steuerprotokoll | [Wikipedia DE](https://de.wikipedia.org/wiki/CI-V) |
| **[Yaesu CAT](https://en.wikipedia.org/wiki/Computer_Aided_Transceiver)** | [Yaesu](https://de.wikipedia.org/wiki/Yaesu)-Steuerprotokoll | [CAT (EN)](https://en.wikipedia.org/wiki/Computer_Aided_Transceiver) · [Yaesu](https://de.wikipedia.org/wiki/Yaesu) |
| **[ESP32](https://de.wikipedia.org/wiki/ESP32)** / **[ESP32-S3](https://www.espressif.com/en/products/socs/esp32-s3)** | Mikrocontroller | [Wikipedia DE](https://de.wikipedia.org/wiki/ESP32) · [Espressif S3](https://www.espressif.com/en/products/socs/esp32-s3) |
| **[CYD](https://github.com/witnessmenow/ESP32-Cheap-Yellow-Display)** | [Cheap Yellow Display](https://github.com/witnessmenow/ESP32-Cheap-Yellow-Display) | [GitHub CYD](https://github.com/witnessmenow/ESP32-Cheap-Yellow-Display) |
| **[USB](https://de.wikipedia.org/wiki/Universal_Serial_Bus)** | Universal Serial Bus | [Wikipedia DE](https://de.wikipedia.org/wiki/Universal_Serial_Bus) |
| **[USB OTG](https://de.wikipedia.org/wiki/USB_On-The-Go)** | On-The-Go | [Wikipedia DE](https://de.wikipedia.org/wiki/USB_On-The-Go) |
| **[USB CDC](https://de.wikipedia.org/wiki/USB_Communications_Device_Class)** | Seriell über [USB](https://de.wikipedia.org/wiki/Universal_Serial_Bus) | [Wikipedia DE](https://de.wikipedia.org/wiki/USB_Communications_Device_Class) |
| **[USB UAC](https://de.wikipedia.org/wiki/USB-Audioklasse)** / **[USB-Audio](https://de.wikipedia.org/wiki/USB-Audioklasse)** | Audio über [USB](https://de.wikipedia.org/wiki/Universal_Serial_Bus) | [Wikipedia DE](https://de.wikipedia.org/wiki/Universal_Serial_Bus-Audioklasse) |
| **[USB-Hub](https://de.wikipedia.org/wiki/Universal_Serial_Bus-Hub)** | Verteiler | [Wikipedia DE](https://de.wikipedia.org/wiki/USB-Hub) |
| **[WLAN](https://de.wikipedia.org/wiki/WLAN)** / **[WiFi](https://de.wikipedia.org/wiki/WLAN)** | Drahtlos LAN | [Wikipedia DE](https://de.wikipedia.org/wiki/WLAN) |
| **[DHCP](https://de.wikipedia.org/wiki/Dynamic_Host_Configuration_Protocol)** | IP-Adresse vom Router | [Wikipedia DE](https://de.wikipedia.org/wiki/Dynamic_Host_Configuration_Protocol) |
| **[SSID](https://de.wikipedia.org/wiki/Service_Set_Identifier)** | Netzwerkname | [Wikipedia DE](https://de.wikipedia.org/wiki/Service_Set_Identifier) |
| **AP** | Access Point (Funk-AP des ESP) | [Wikipedia DE](https://de.wikipedia.org/wiki/Wireless_Access_Point) |
| **[TCP](https://de.wikipedia.org/wiki/Transmission_Control_Protocol)** / **[UDP](https://de.wikipedia.org/wiki/User_Datagram_Protocol)** | Netzwerkprotokolle | [TCP](https://de.wikipedia.org/wiki/Transmission_Control_Protocol) · [UDP](https://de.wikipedia.org/wiki/User_Datagram_Protocol) |
| **[UART](https://de.wikipedia.org/wiki/Asynchrone_Serielle_Schnittstelle)** | Serielle Schnittstelle | [Wikipedia DE](https://de.wikipedia.org/wiki/Asynchrone_Serielle_Schnittstelle) |
| **[I2S](https://de.wikipedia.org/wiki/I%C2%B2S)** | Digital-Audio-Bus | [Wikipedia DE](https://de.wikipedia.org/wiki/I%C2%B2S) |
| **[GPIO](https://de.wikipedia.org/wiki/General_Purpose_Input/Output)** | Ein-/Ausgänge | [Wikipedia DE](https://de.wikipedia.org/wiki/General_Purpose_Input/Output) |
| **[RJ45](https://de.wikipedia.org/wiki/RJ-45)** | 8P8C-Buchse | [Wikipedia DE](https://de.wikipedia.org/wiki/RJ-45) |
| **[TTL](https://de.wikipedia.org/wiki/Transistor-Transistor-Logik)** | Logikpegel | [Wikipedia DE](https://de.wikipedia.org/wiki/Transistor-Transistor-Logik) |
| **[RS-232](https://de.wikipedia.org/wiki/RS-232)** | klassische Seriell | [Wikipedia DE](https://de.wikipedia.org/wiki/RS-232) |
| **[Pegelwandler](https://de.wikipedia.org/wiki/Pegelwandler)** | 3,3 V ↔ 5 V | [Wikipedia DE](https://de.wikipedia.org/wiki/Pegelwandler) |
| **[FT8](https://de.wikipedia.org/wiki/FT8_(Amateurfunk))** | Digitalmode | [Wikipedia DE](https://de.wikipedia.org/wiki/FT8_(Amateurfunk)) |
| **[WSJT-X](https://physics.princeton.edu/pulsar/k1jt/wsjtx.html)** | [FT8](https://de.wikipedia.org/wiki/FT8_(Amateurfunk))-Software | [Offizielle Seite](https://physics.princeton.edu/pulsar/k1jt/wsjtx.html) |
| **[Hamlib](https://en.wikipedia.org/wiki/Hamlib)** | Funk-Bibliothek | [Wikipedia EN](https://en.wikipedia.org/wiki/Hamlib) · [Website](https://hamlib.github.io/) |
| **[rigctld](https://hamlib.sourceforge.net/html/rigctld.1.html)** / **[rigctl](https://hamlib.sourceforge.net/html/rigctl.1.html)** | [CAT](https://en.wikipedia.org/wiki/Computer_Aided_Transceiver)-Server/Client | [rigctld](https://hamlib.sourceforge.net/html/rigctld.1.html.1.html) · [rigctl](https://hamlib.sourceforge.net/html/rigctl.1.html) |
| **[rotctld](https://hamlib.sourceforge.net/html/rotctld.1.html)** / **[rotctl](https://hamlib.sourceforge.net/html/rotctl.1.html)** | [Rotor](https://de.wikipedia.org/wiki/Rotor_(Antenne))-Server/Client | [rotctld](https://hamlib.sourceforge.net/html/rotctld.1.html.1.html) · [rotctl](https://hamlib.sourceforge.net/html/rotctl.1.html) |
| **[flrig](https://github.com/w1hkj/flrig)** | [CAT](https://en.wikipedia.org/wiki/Computer_Aided_Transceiver)-UI | [GitHub](https://github.com/w1hkj/flrig) |
| **[fldigi](https://de.wikipedia.org/wiki/Fldigi)** | Digitalmodes | [Wikipedia DE](https://de.wikipedia.org/wiki/Fldigi) |
| **[VB-Audio](https://vb-audio.com/Cable/) / [VB-Cable](https://vb-audio.com/Cable/)** | Virtuelles Kabel ([Windows](https://de.wikipedia.org/wiki/Microsoft_Windows)) | [vb-audio.com](https://vb-audio.com/Cable/) |
| **[Galvanische Trennung](https://de.wikipedia.org/wiki/Galvanische_Trennung)** | getrennte Masse | [Wikipedia DE](https://de.wikipedia.org/wiki/Galvanische_Trennung) |
| **[Brumschleife](https://de.wikipedia.org/wiki/Brumschleife)** | Ground Loop | [Wikipedia DE](https://de.wikipedia.org/wiki/Brumschleife) |
| **[PCB](https://de.wikipedia.org/wiki/Leiterplatte) / [Leiterplatte](https://de.wikipedia.org/wiki/Leiterplatte)** | Platine | [Wikipedia DE](https://de.wikipedia.org/wiki/Leiterplatte) |
| **[Gerber](https://en.wikipedia.org/wiki/Gerber_format)** | Fertigungsdaten | [Wikipedia EN](https://en.wikipedia.org/wiki/Gerber_format) |
| **[KiCad](https://de.wikipedia.org/wiki/KiCad)** | CAD | [Wikipedia DE](https://de.wikipedia.org/wiki/KiCad) |
| **[DRC](https://en.wikipedia.org/wiki/Design_rule_check)** | Design Rule Check | [Wikipedia EN](https://en.wikipedia.org/wiki/Design_rule_check) |
| **[BOM](https://de.wikipedia.org/wiki/St%C3%BCckliste) / [Stückliste](https://de.wikipedia.org/wiki/St%C3%BCckliste)** | Bauteilliste | [Wikipedia DE](https://de.wikipedia.org/wiki/St%C3%BCckliste) |
| **[SMT](https://de.wikipedia.org/wiki/Oberfl%C3%A4chenmontage) / [THT](https://de.wikipedia.org/wiki/Lochleiterplatte)** | Montage | [SMT](https://de.wikipedia.org/wiki/Oberfl%C3%A4chenmontage) · [THT](https://de.wikipedia.org/wiki/Lochleiterplatte) |
| **[JLCPCB](https://jlcpcb.com/)** | [PCB](https://de.wikipedia.org/wiki/Leiterplatte)-Fertigung | [jlcpcb.com](https://jlcpcb.com/) |
| **[PlatformIO](https://platformio.org/)** | Build-System | [platformio.org](https://platformio.org/) |
| **[Rotor](https://de.wikipedia.org/wiki/Rotor_(Antenne))** | Antennenrotator | [Wikipedia DE](https://de.wikipedia.org/wiki/Rotor_(Antenne)) |
| **[Open Collector](https://de.wikipedia.org/wiki/Offener_Kollektor)** | Relais-Ansteuerung | [Wikipedia DE](https://de.wikipedia.org/wiki/Offener_Kollektor) |
| **[PTT](https://de.wikipedia.org/wiki/Sende-Empfang-Umschaltung)** | Senden/Empfang | [Wikipedia DE](https://de.wikipedia.org/wiki/Sende-Empfang-Umschaltung) |
| **[ICOM](https://de.wikipedia.org/wiki/Icom)** / **[Yaesu](https://de.wikipedia.org/wiki/Yaesu)** / **[Xiegu](https://www.xiegu.com/)** | Hersteller | [Icom](https://de.wikipedia.org/wiki/Icom) · [Yaesu](https://de.wikipedia.org/wiki/Yaesu) · [xiegu.com](https://www.xiegu.com/) |
| **[ISO7741](https://www.ti.com/product/ISO7741)** | Digital-Isolator | [TI](https://www.ti.com/product/ISO7741) |
| **[ADuM4160](https://www.analog.com/en/products/adum4160.html)** | [USB](https://de.wikipedia.org/wiki/Universal_Serial_Bus)-Isolator | [Analog Devices](https://www.analog.com/en/products/adum4160.html) |
| **[USB2422](https://www.microchip.com/en-us/product/USB2422)** | [USB-Hub](https://de.wikipedia.org/wiki/Universal_Serial_Bus-Hub)-IC | [Microchip](https://www.microchip.com/en-us/product/USB2422) |
| **[PCM5102](https://www.ti.com/product/PCM5102)** / **[INMP441](https://www.invensense.com/products/digital/inmp441/)** | DAC / [I2S](https://de.wikipedia.org/wiki/I%C2%B2S)-Mikrofon | [TI PCM5102](https://www.ti.com/product/PCM5102) · [INMP441](https://www.invensense.com/products/digital/inmp441/) |
| **[CH340](https://de.wikipedia.org/wiki/Universal_Serial_Bus-UART-Bridge)** | [USB](https://de.wikipedia.org/wiki/Universal_Serial_Bus)-[UART](https://de.wikipedia.org/wiki/Asynchrone_Serielle_Schnittstelle) am [CYD](https://github.com/witnessmenow/ESP32-Cheap-Yellow-Display) | [Wikipedia DE](https://de.wikipedia.org/wiki/USB-UART-Bridge) |
| **[JSON](https://de.wikipedia.org/wiki/JSON)** | Konfigurationsformat | [Wikipedia DE](https://de.wikipedia.org/wiki/JSON) |
| **[PulseAudio](https://de.wikipedia.org/wiki/PulseAudio)** / **[ALSA](https://de.wikipedia.org/wiki/Advanced_Linux_Sound_Architecture)** | [Linux](https://de.wikipedia.org/wiki/Linux)-Audio | [PulseAudio](https://de.wikipedia.org/wiki/PulseAudio) · [ALSA](https://de.wikipedia.org/wiki/Advanced_Linux_Sound_Architecture) |
| **[WSL](https://learn.microsoft.com/de-de/windows/wsl/)** | [Windows](https://de.wikipedia.org/wiki/Microsoft_Windows) Subsystem for [Linux](https://de.wikipedia.org/wiki/Linux) | [Microsoft](https://learn.microsoft.com/de-de/windows/wsl/) |

---

## English

| Term | Meaning | Source |
|---|---|---|
| **[CAT](https://en.wikipedia.org/wiki/Computer_Aided_Transceiver)** | [Computer Aided Transceiver](https://en.wikipedia.org/wiki/Computer_Aided_Transceiver) | [Wikipedia](https://en.wikipedia.org/wiki/Computer_Aided_Transceiver) |
| **[CI-V](https://en.wikipedia.org/wiki/CI-V)** | [ICOM](https://en.wikipedia.org/wiki/Icom) control protocol | [Wikipedia](https://en.wikipedia.org/wiki/CI-V) |
| **[ESP32](https://en.wikipedia.org/wiki/ESP32)** / **[ESP32-S3](https://www.espressif.com/en/products/socs/esp32-s3)** | Microcontroller | [Wikipedia](https://en.wikipedia.org/wiki/ESP32) · [Espressif S3](https://www.espressif.com/en/products/socs/esp32-s3) |
| **[USB](https://en.wikipedia.org/wiki/USB)** / **OTG** / **CDC** / **UAC** | Bus & classes | [USB](https://en.wikipedia.org/wiki/USB) · [OTG](https://en.wikipedia.org/wiki/USB_On-The-Go) · [CDC](https://en.wikipedia.org/wiki/USB_communications_device_class) · [UAC](https://en.wikipedia.org/wiki/USB_audio_device_class) |
| **[WiFi](https://en.wikipedia.org/wiki/Wi-Fi)** | Wireless LAN | [Wikipedia](https://en.wikipedia.org/wiki/Wi-Fi) |
| **[DHCP](https://en.wikipedia.org/wiki/Dynamic_Host_Configuration_Protocol)** | IP assignment | [Wikipedia](https://en.wikipedia.org/wiki/Dynamic_Host_Configuration_Protocol) |
| **[TCP](https://en.wikipedia.org/wiki/Transmission_Control_Protocol)** / **[UDP](https://en.wikipedia.org/wiki/User_Datagram_Protocol)** | Network | [TCP](https://en.wikipedia.org/wiki/Transmission_Control_Protocol) · [UDP](https://en.wikipedia.org/wiki/User_Datagram_Protocol) |
| **[UART](https://en.wikipedia.org/wiki/Universal_asynchronous_receiver-transmitter)** / **[I2S](https://en.wikipedia.org/wiki/I%C2%B2S)** / **[GPIO](https://en.wikipedia.org/wiki/General-purpose_input/output)** / **[RJ45](https://en.wikipedia.org/wiki/Registered_jack)** / **[TTL](https://en.wikipedia.org/wiki/Transistor%E2%80%93transistor_logic)** | Interfaces | [UART](https://en.wikipedia.org/wiki/Universal_asynchronous_receiver-transmitter) · [I2S](https://en.wikipedia.org/wiki/I%C2%B2S) · [GPIO](https://en.wikipedia.org/wiki/General-purpose_input/output) · [RJ45](https://en.wikipedia.org/wiki/Registered_jack) · [TTL](https://en.wikipedia.org/wiki/Transistor%E2%80%93transistor_logic) |
| **[FT8](https://en.wikipedia.org/wiki/FT8_(digital_mode))** / **[WSJT-X](https://physics.princeton.edu/pulsar/k1jt/wsjtx.html)** | Digital mode / app | [FT8](https://en.wikipedia.org/wiki/FT8_(digital_mode)) · [WSJT-X](https://physics.princeton.edu/pulsar/k1jt/wsjtx.html) |
| **[Hamlib](https://en.wikipedia.org/wiki/Hamlib)** / **[rigctld](https://hamlib.sourceforge.net/html/rigctld.1.html)** / **[rotctld](https://hamlib.sourceforge.net/html/rotctld.1.html)** | Control stack | [Hamlib](https://en.wikipedia.org/wiki/Hamlib) · [rigctld](https://hamlib.sourceforge.net/html/rigctld.1.html) · [rotctld](https://hamlib.sourceforge.net/html/rotctld.1.html) |
| **Galvanic isolation** | Separate grounds | [Wikipedia](https://en.wikipedia.org/wiki/Galvanic_isolation) |
| **Ground loop** | Hum / [CAT](https://en.wikipedia.org/wiki/Computer_Aided_Transceiver) errors | [Wikipedia](https://en.wikipedia.org/wiki/Ground_loop_(electricity)) |
| **[PCB](https://en.wikipedia.org/wiki/Printed_circuit_board)** / **[Gerber](https://en.wikipedia.org/wiki/Gerber_format)** / **[KiCad](https://en.wikipedia.org/wiki/KiCad)** / **[DRC](https://en.wikipedia.org/wiki/Design_rule_check)** / **[BOM](https://en.wikipedia.org/wiki/Bill_of_materials)** | Hardware design | [PCB](https://en.wikipedia.org/wiki/Printed_circuit_board) · [Gerber](https://en.wikipedia.org/wiki/Gerber_format) · [KiCad](https://en.wikipedia.org/wiki/KiCad) · [DRC](https://en.wikipedia.org/wiki/Design_rule_check) · [BOM](https://en.wikipedia.org/wiki/Bill_of_materials) |
| **Antenna rotator** | [Rotor](https://en.wikipedia.org/wiki/Antenna_rotator) | [Wikipedia](https://en.wikipedia.org/wiki/Antenna_rotator) |
| **[Open collector](https://en.wikipedia.org/wiki/Open_collector)** | Relay drive | [Wikipedia](https://en.wikipedia.org/wiki/Open_collector) |

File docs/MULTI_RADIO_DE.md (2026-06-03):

# 3× Funk parallel — unabhängig am PC

[English](MULTI_RADIO_EN.md) · [Glossar / Fachbegriffe](GLOSSARY.md#deutsch)

## Was „3 [Funkgeräte](https://de.wikipedia.org/wiki/Transceiver)“ bedeutet

Am **PC** laufen **drei getrennte Steuer- und Audio-Ketten** — nicht ein gemischter Stream:

| Am PC | Funk A | Funk B | Funk C |
|---|---|---|---|
| **[CAT](https://en.wikipedia.org/wiki/Computer_Aided_Transceiver) ([rigctld](https://hamlib.sourceforge.net/html/rigctld.1.html))** | [TCP](https://de.wikipedia.org/wiki/Transmission_Control_Protocol) `<IP>`:**4532** | [TCP](https://de.wikipedia.org/wiki/Transmission_Control_Protocol) `<IP>`:**4536** | [TCP](https://de.wikipedia.org/wiki/Transmission_Control_Protocol) `<IP>`:**4540** |
| **Audio RX** (Funk → PC) | [UDP](https://de.wikipedia.org/wiki/User_Datagram_Protocol) **4533** | [UDP](https://de.wikipedia.org/wiki/User_Datagram_Protocol) **4538** | [UDP](https://de.wikipedia.org/wiki/User_Datagram_Protocol) **4541** |
| **Audio TX** (PC → Funk) | [UDP](https://de.wikipedia.org/wiki/User_Datagram_Protocol) **4534** | [UDP](https://de.wikipedia.org/wiki/User_Datagram_Protocol) **4539** | [UDP](https://de.wikipedia.org/wiki/User_Datagram_Protocol) **4542** |
| **Web-Audio** (optional) | `/audio` | `/audio_b` | `/audio_c` |
| **[Rotor](https://de.wikipedia.org/wiki/Rotor_(Antenne))** (einmalig) | — | — | — |

- Der [ESP32](https://de.wikipedia.org/wiki/ESP32) betreibt **drei unabhängige `rigctld`-Server** und **drei `AudioBridge`-Tasks** (eigene UDP-Sockets, kein Summieren/Mixing).
- Jede PC-Anwendung muss **eigenes [rigctl](https://hamlib.sourceforge.net/html/rigctl.1.html)-Host:Port** und **eigenes Audio-[UDP](https://de.wikipedia.org/wiki/User_Datagram_Protocol)-Paar** nutzen (z. B. drei [WSJT-X](https://physics.princeton.edu/pulsar/k1jt/wsjtx.html)-Instanzen mit je einem virtuellen Kabel).

**[CAT](https://en.wikipedia.org/wiki/Computer_Aided_Transceiver)** = [Computer Aided Transceiver](https://en.wikipedia.org/wiki/Computer_Aided_Transceiver). **Masse:** [galvanisch getrennt](https://de.wikipedia.org/wiki/Galvanische_Trennung) ([ISOLATION.md](ISOLATION.md)).

## Beispiel am PC (3× [FT8](https://de.wikipedia.org/wiki/FT8_(Amateurfunk)))

```
┌──────────────── PC ─────────────────────────────────────────────┐
│  WSJT-X #1          WSJT-X #2          fldigi / anderes Programm │
│  rigctl → :4532     rigctl → :4536     rigctl → :4540            │
│  Audio 4533/4534    Audio 4538/4539    Audio 4541/4542           │
│  VB-Cable A         VB-Cable B         VB-Cable C                │
└────────┬──────────────────┬──────────────────┬──────────────────┘
         │ WiFi             │                  │
         ▼                  ▼                  ▼
    ┌──────── ESP32 (3 Kanäle parallel, nicht gemischt) ────────────┐
    │  Kanal A (RJ45)     Kanal B (USB J5)     Kanal C (USB J6)      │
    └────────────────────────────────────────────────────────────────┘
```

| Instanz | `rigctld` / [rigctl](https://hamlib.sourceforge.net/html/rigctl.1.html) | Audio-Bridge (Skript) | Typisches PC-Audio |
|---|---|---|---|
| 1 | `-r 192.168.4.1:4532` | `audio_client.py --port-out 4533 --port-in 4534` | [VB-Audio](https://vb-audio.com/Cable/) Cable **A** |
| 2 | `-r 192.168.4.1:4536` | `--port-out 4538 --port-in 4539` | [VB-Audio](https://vb-audio.com/Cable/) Cable **B** |
| 3 | `-r 192.168.4.1:4540` | `--port-out 4541 --port-in 4542` | [VB-Audio](https://vb-audio.com/Cable/) Cable **C** |

`scripts/ft8_setup.py` konfiguriert **eine** Instanz; für drei [Funkgeräte](https://de.wikipedia.org/wiki/Transceiver) **drei Profile** (eigene [JSON](https://de.wikipedia.org/wiki/JSON) + eigenes virtuelles Kabel pro Instanz).

## Hardware (Shield Rev C)

| Kanal | Anschluss | [CAT](https://en.wikipedia.org/wiki/Computer_Aided_Transceiver) | Audio zum ESP |
|---|---|-----|---|
| **A** | [RJ45](https://de.wikipedia.org/wiki/RJ-45) | [UART](https://de.wikipedia.org/wiki/Asynchrone_Serielle_Schnittstelle) (isoliert) | [I2S](https://de.wikipedia.org/wiki/I%C2%B2S) |
| **B** | [USB-A](https://de.wikipedia.org/wiki/USB) J5 | [USB-CDC](https://de.wikipedia.org/wiki/USB_Communications_Device_Class) | [USB-UAC](https://de.wikipedia.org/wiki/USB-Audioklasse) (S3) |
| **C** | [USB](https://de.wikipedia.org/wiki/Universal_Serial_Bus)-A J6 | [USB-CDC](https://de.wikipedia.org/wiki/USB_Communications_Device_Class) | [USB-UAC](https://de.wikipedia.org/wiki/USB-Audioklasse) (S3) |
| **[Rotor](https://de.wikipedia.org/wiki/Rotor_(Antenne))** | J7 | — | [rotctld](https://hamlib.sourceforge.net/html/rotctld.1.html) **4535** |

```
  Funk A ── RJ45 ── ESP Kanal A ── WiFi ── PC App 1
  Funk B ── USB J5 ── ESP Kanal B ── WiFi ── PC App 2
  Funk C ── USB J6 ── ESP Kanal C ── WiFi ── PC App 3
```

## Firmware & Konfiguration

```bash
pio run -t upload -e esp32-flrig-shield
pio run -t uploadfs -e esp32-flrig-shield
```

In `config.json` alle drei Kanäle aktivieren (`radios[]`, siehe Beispiel in [ft8_config.example-3radio.json](../scripts/ft8_config.example-3radio.json)):

```bash
rigctl -m 2 -r <IP>:4532 f
rigctl -m 2 -r <IP>:4536 f
rigctl -m 2 -r <IP>:4540 f
rotctl -m 2 -r <IP>:4535 p
```

## Wichtig

| Thema | Verhalten |
|---|---|
| Audio-Mixing auf ESP | **Nein** — je Kanal eigener Task + Ports |
| Ein [rigctl](https://hamlib.sourceforge.net/html/rigctl.1.html) für alle | **Nein** — je Funk eigener [TCP](https://de.wikipedia.org/wiki/Transmission_Control_Protocol)-Port |
| Ein [VB-Cable](https://vb-audio.com/Cable/) für alle | **Nein** — je PC-Programm eigenes Gerät empfohlen |
| [CYD](https://github.com/witnessmenow/ESP32-Cheap-Yellow-Display) (ohne S3) | Nur **Kanal A** + [Rotor](https://de.wikipedia.org/wiki/Rotor_(Antenne)); B/C brauchen [ESP32-S3](https://www.espressif.com/en/products/socs/esp32-s3) + Shield |

Weitere Infos: [Shield README](../hardware/esp32-flrig-shield/README.md) · [Haupt-README](../README.md)

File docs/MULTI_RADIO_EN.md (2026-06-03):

# 3× radios in parallel — independent on the PC

[Deutsch](MULTI_RADIO_DE.md) · [Glossary](GLOSSARY.md#english)

## What “3 radios” means

On the **PC**, you run **three separate control and audio chains** — not one mixed stream:

| On PC | Radio A | Radio B | Radio C |
|---|---|---|---|
| **[CAT](https://en.wikipedia.org/wiki/Computer_Aided_Transceiver) ([rigctld](https://hamlib.sourceforge.net/html/rigctld.1.html))** | [TCP](https://en.wikipedia.org/wiki/Transmission_Control_Protocol) `<IP>`:**4532** | [TCP](https://en.wikipedia.org/wiki/Transmission_Control_Protocol) `<IP>`:**4536** | [TCP](https://en.wikipedia.org/wiki/Transmission_Control_Protocol) `<IP>`:**4540** |
| **Audio RX** (radio → PC) | [UDP](https://en.wikipedia.org/wiki/User_Datagram_Protocol) **4533** | [UDP](https://en.wikipedia.org/wiki/User_Datagram_Protocol) **4538** | [UDP](https://en.wikipedia.org/wiki/User_Datagram_Protocol) **4541** |
| **Audio TX** (PC → radio) | [UDP](https://en.wikipedia.org/wiki/User_Datagram_Protocol) **4534** | [UDP](https://en.wikipedia.org/wiki/User_Datagram_Protocol) **4539** | [UDP](https://en.wikipedia.org/wiki/User_Datagram_Protocol) **4542** |
| **Web audio** (optional) | `/audio` | `/audio_b` | `/audio_c` |
| **[Rotor](https://en.wikipedia.org/wiki/Antenna_rotator)** (shared) | — | — | — |

- The [ESP32](https://en.wikipedia.org/wiki/ESP32) runs **three independent `rigctld` servers** and **three `AudioBridge` tasks** (separate UDP sockets, no summing/mixing).
- Each PC application must use its **own [rigctl](https://hamlib.sourceforge.net/html/rigctl.1.html) host:port** and **own audio [UDP](https://en.wikipedia.org/wiki/User_Datagram_Protocol) port pair** (e.g. three [WSJT-X](https://physics.princeton.edu/pulsar/k1jt/wsjtx.html) instances with separate virtual audio cables).

**[CAT](https://en.wikipedia.org/wiki/Computer_Aided_Transceiver)** = [Computer Aided Transceiver](https://en.wikipedia.org/wiki/Computer_Aided_Transceiver). **Ground:** [galvanically isolated](https://en.wikipedia.org/wiki/Galvanic_isolation) ([ISOLATION.md](ISOLATION.md)).

## Example on the PC (3× [FT8](https://en.wikipedia.org/wiki/FT8_(digital_mode)))

```
┌──────────────── PC ─────────────────────────────────────────────┐
│  WSJT-X #1          WSJT-X #2          fldigi / other app        │
│  rigctl → :4532     rigctl → :4536     rigctl → :4540            │
│  Audio 4533/4534    Audio 4538/4539    Audio 4541/4542           │
│  VB-Cable A         VB-Cable B         VB-Cable C                │
└────────┬──────────────────┬──────────────────┬──────────────────┘
         │ WiFi             │                  │
         ▼                  ▼                  ▼
    ┌──────── ESP32 (3 parallel channels, not mixed) ───────────────┐
    │  Ch A (RJ45)        Ch B (USB J5)        Ch C (USB J6)         │
    └────────────────────────────────────────────────────────────────┘
```

| Instance | [rigctl](https://hamlib.sourceforge.net/html/rigctl.1.html) | Audio bridge (script) | Typical PC audio |
|---|---|---|---|
| 1 | `-r 192.168.4.1:4532` | `audio_client.py --port-out 4533 --port-in 4534` | [VB-Audio](https://vb-audio.com/Cable/) Cable **A** |
| 2 | `-r 192.168.4.1:4536` | `--port-out 4538 --port-in 4539` | [VB-Audio](https://vb-audio.com/Cable/) Cable **B** |
| 3 | `-r 192.168.4.1:4540` | `--port-out 4541 --port-in 4542` | [VB-Audio](https://vb-audio.com/Cable/) Cable **C** |

`scripts/ft8_setup.py` sets up **one** instance; for three radios use **three profiles** (separate [JSON](https://en.wikipedia.org/wiki/JSON) + separate virtual cable per app).

## Hardware (Shield Rev C)

| Channel | Connector | [CAT](https://en.wikipedia.org/wiki/Computer_Aided_Transceiver) | Audio to ESP |
|---|---|-----|---|
| **A** | [RJ45](https://en.wikipedia.org/wiki/Registered_jack) | [UART](https://en.wikipedia.org/wiki/Universal_asynchronous_receiver-transmitter) (isolated) | [I2S](https://en.wikipedia.org/wiki/I%C2%B2S) |
| **B** | [USB-A](https://en.wikipedia.org/wiki/USB) J5 | [USB CDC](https://en.wikipedia.org/wiki/USB_communications_device_class) | [USB UAC](https://en.wikipedia.org/wiki/USB_audio_device_class) (S3) |
| **C** | [USB](https://en.wikipedia.org/wiki/USB)-A J6 | [USB CDC](https://en.wikipedia.org/wiki/USB_communications_device_class) | [USB UAC](https://en.wikipedia.org/wiki/USB_audio_device_class) (S3) |
| **[Rotor](https://en.wikipedia.org/wiki/Antenna_rotator)** | J7 | — | [rotctld](https://hamlib.sourceforge.net/html/rotctld.1.html) **4535** |

## Firmware & config

```bash
pio run -t upload -e esp32-flrig-shield
pio run -t uploadfs -e esp32-flrig-shield
```

Enable all three channels in `config.json` (`radios[]` — see [ft8_config.example-3radio.json](../scripts/ft8_config.example-3radio.json)):

```bash
rigctl -m 2 -r <IP>:4532 f
rigctl -m 2 -r <IP>:4536 f
rigctl -m 2 -r <IP>:4540 f
rotctl -m 2 -r <IP>:4535 p
```

## Important

| Topic | Behavior |
|---|---|
| Audio mixing on ESP | **No** — per-channel task and ports |
| One [rigctl](https://hamlib.sourceforge.net/html/rigctl.1.html) for all | **No** — one [TCP](https://en.wikipedia.org/wiki/Transmission_Control_Protocol) port per radio |
| One [VB-Cable](https://vb-audio.com/Cable/) for all | **No** — one virtual device per PC app recommended |
| [CYD](https://github.com/witnessmenow/ESP32-Cheap-Yellow-Display) (no S3) | **Channel A** + [rotor](https://en.wikipedia.org/wiki/Antenna_rotator) only; B/C need [ESP32-S3](https://www.espressif.com/en/products/socs/esp32-s3) + shield |

More: [Shield README](../hardware/esp32-flrig-shield/README.md) · [main README](../README.md)

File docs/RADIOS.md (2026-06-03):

# Unterstützte [Funkgeräte](https://de.wikipedia.org/wiki/Transceiver) ([CAT](https://en.wikipedia.org/wiki/Computer_Aided_Transceiver) + Audio)

Das [ESP32](https://de.wikipedia.org/wiki/ESP32)-Panel spricht **direkt per [UART](https://de.wikipedia.org/wiki/Asynchrone_Serielle_Schnittstelle)** mit dem [Funkgerät](https://de.wikipedia.org/wiki/Transceiver) (3,3 V [TTL](https://de.wikipedia.org/wiki/Transistor-Transistor-Logik) über [Pegelwandler](https://de.wikipedia.org/wiki/Pegelwandler)). In der Web-Konfiguration (`http://<ESP-IP>/`) wählen Sie das Modell – **Baudrate, Protokoll und [CI-V](https://de.wikipedia.org/wiki/CI-V)-Adresse** werden automatisch gesetzt.

## Übersicht

| Profil-ID | Gerät | [CAT](https://en.wikipedia.org/wiki/Computer_Aided_Transceiver)-Protokoll | Baud | [CI-V](https://de.wikipedia.org/wiki/CI-V) Addr |
|---|---|---|---|---|
| `XIEGU_G90` | [Xiegu](https://www.xiegu.com/) G90 | [ICOM](https://de.wikipedia.org/wiki/Icom) [CI-V](https://de.wikipedia.org/wiki/CI-V) | 19200 | A4 |
| `XIEGU_X6100` | [Xiegu](https://www.xiegu.com/) [X6100](https://www.xiegu.com/) | [ICOM](https://de.wikipedia.org/wiki/Icom) [CI-V](https://de.wikipedia.org/wiki/CI-V) | 19200 | A4 |
| `XIEGU_X6200` | [Xiegu](https://www.xiegu.com/) [X6200](https://www.xiegu.com/) | [ICOM](https://de.wikipedia.org/wiki/Icom) [CI-V](https://de.wikipedia.org/wiki/CI-V) | 19200 | A4 |
| `YAESU_FT991A` | [Yaesu](https://de.wikipedia.org/wiki/Yaesu) FT-991A | [Yaesu CAT](https://en.wikipedia.org/wiki/Computer_Aided_Transceiver) | 38400 | — |
| `YAESU_FT910` | [Yaesu](https://de.wikipedia.org/wiki/Yaesu) FT-910 | [Yaesu](https://de.wikipedia.org/wiki/Yaesu) [CAT](https://en.wikipedia.org/wiki/Computer_Aided_Transceiver) | 38400 | — |
| `YAESU_FTDX10` | [Yaesu](https://de.wikipedia.org/wiki/Yaesu) FT-DX10 | [Yaesu CAT](https://en.wikipedia.org/wiki/Computer_Aided_Transceiver) | 38400 | — |
| `YAESU_FTDX101D` | [Yaesu](https://de.wikipedia.org/wiki/Yaesu) FT-DX101D | [Yaesu](https://de.wikipedia.org/wiki/Yaesu) [CAT](https://en.wikipedia.org/wiki/Computer_Aided_Transceiver) | 38400 | — |
| `YAESU_FTDX101MP` | [Yaesu](https://de.wikipedia.org/wiki/Yaesu) FT-DX101MP | [Yaesu CAT](https://en.wikipedia.org/wiki/Computer_Aided_Transceiver) | 38400 | — |
| `YAESU_FT891` | Yaesu FT-891 | [Yaesu CAT](https://en.wikipedia.org/wiki/Computer_Aided_Transceiver) | 38400 | — |
| `YAESU_FT897` | Yaesu FT-897 | [Yaesu CAT](https://en.wikipedia.org/wiki/Computer_Aided_Transceiver) | 4800* | — |
| `YAESU_FT857` | [Yaesu](https://de.wikipedia.org/wiki/Yaesu) FT-857 | [Yaesu](https://de.wikipedia.org/wiki/Yaesu) [CAT](https://en.wikipedia.org/wiki/Computer_Aided_Transceiver) | 4800 | — |

\* FT-897: Menü-[CAT](https://en.wikipedia.org/wiki/Computer_Aided_Transceiver)-Rate prüfen (oft 4800, manche 38400).

## [Xiegu](https://www.xiegu.com/) (G90, [X6100](https://www.xiegu.com/), [X6200](https://www.xiegu.com/))

- **Protokoll:** [CI-V](https://de.wikipedia.org/wiki/CI-V)-kompatibel (wie [ICOM](https://de.wikipedia.org/wiki/Icom)), **nicht** [Yaesu](https://de.wikipedia.org/wiki/Yaesu)-[CAT](https://en.wikipedia.org/wiki/Computer_Aided_Transceiver).
- **Einstellungen:** 19200 [bps](https://de.wikipedia.org/wiki/Bit_pro_Sekunde), Radio-Adresse **0xA4** (wird vom Profil gesetzt).
- **Anschluss G90:** [CAT](https://en.wikipedia.org/wiki/Computer_Aided_Transceiver) nur an der **Display-Einheit** (3,5 mm / IO-Port), nicht am Basisgerät.
- **[X6100](https://www.xiegu.com/)/[X6200](https://www.xiegu.com/):** [USB](https://de.wikipedia.org/wiki/Universal_Serial_Bus)-C DEV, Serial-B für [CAT](https://en.wikipedia.org/wiki/Computer_Aided_Transceiver); [USB](https://de.wikipedia.org/wiki/Universal_Serial_Bus)-Audio für Sound.
- **[WSJT-X](https://physics.princeton.edu/pulsar/k1jt/wsjtx.html) / [flrig](https://github.com/w1hkj/flrig):** Modell z. B. „[Xiegu](https://www.xiegu.com/) [X6100](https://www.xiegu.com/)“, „XIEGU [X6200](https://www.xiegu.com/)“ oder als Fallback **IC-7100**; Steuerung über **[rigctld](https://hamlib.sourceforge.net/html/rigctld.1.html)** am ESP (`[rigctl](https://hamlib.sourceforge.net/html/rigctl.1.html) -m 2 -r <ESP-IP>:4532`).

## Yaesu

- **Protokoll:** [Yaesu CAT](https://en.wikipedia.org/wiki/Computer_Aided_Transceiver) (ASCII-Befehle).
- **Baud:** 38400 (FT-991A, FT-910, FT-DX-Serie, FT-891); **4800** für FT-897/FT-857 – im Funkmenü **[CAT](https://en.wikipedia.org/wiki/Computer_Aided_Transceiver) RATE** anpassen, falls nötig.
- **[FT8](https://de.wikipedia.org/wiki/FT8_(Amateurfunk))/Digital:** Modus **[USB](https://de.wikipedia.org/wiki/Universal_Serial_Bus)** oder **DATA-[USB](https://de.wikipedia.org/wiki/Universal_Serial_Bus)** / **DIGU** je nach Gerät; [PTT](https://de.wikipedia.org/wiki/Sende-Empfang-Umschaltung) über [CAT](https://en.wikipedia.org/wiki/Computer_Aided_Transceiver) (`T 3` für Daten) wird vom Panel unterstützt.
- **Audio:** [USB-Audio](https://de.wikipedia.org/wiki/Universal_Serial_Bus-Audioklasse) oder LINE OUT / LINE IN / PACKET – physikalisch an **[I2S](https://de.wikipedia.org/wiki/I%C2%B2S)-Bridge** ([PCM5102](https://www.ti.com/product/PCM5102) + [INMP441](https://www.invensense.com/products/digital/inmp441/) oder Line-Level) anschließen, siehe README.

## [Hamlib](https://en.wikipedia.org/wiki/Hamlib) / [WSJT-X](https://physics.princeton.edu/pulsar/k1jt/wsjtx.html) am PC

| Gerät | Empfohlenes [Hamlib](https://en.wikipedia.org/wiki/Hamlib)-Modell (Referenz) |
|---|---|
| [Xiegu](https://www.xiegu.com/) G90 | [Xiegu](https://www.xiegu.com/) G90 / IC-7100 |
| [X6100](https://www.xiegu.com/) / [X6200](https://www.xiegu.com/) | [Xiegu](https://www.xiegu.com/) [X6100](https://www.xiegu.com/) / [X6200](https://www.xiegu.com/) |
| FT-991A | FT-991 / FT-991A |
| FT-DX10 / 101D / 101MP | Entsprechendes FT-DX-Modell |
| FT-891 / 897 / 857 | Gleicher Modellname in [Hamlib](https://en.wikipedia.org/wiki/Hamlib) |

Steuerung über das Panel:

```bash
rigctl -m 2 -r 192.168.4.1:4532 f
rigctl -m 2 -r 192.168.4.1:4532 m USB
```

(`-m 2` = [Hamlib](https://en.wikipedia.org/wiki/Hamlib)-Netzwerk-Rig; das Panel antwortet als [rigctld](https://hamlib.sourceforge.net/html/rigctld.1.html).)

## Audio über [WiFi](https://de.wikipedia.org/wiki/WLAN) ([FT8](https://de.wikipedia.org/wiki/FT8_(Amateurfunk)))

- Sample Rate **48000 Hz** (Standard in der Konfiguration).
- [UDP](https://de.wikipedia.org/wiki/User_Datagram_Protocol) **4533** (Funk → PC) und **4534** (PC → Funk), oder Browser unter `/audio`.
- Skripte: `scripts/ft8_remote.py`, `scripts/ft8_linux_pa.sh`, `scripts/ft8_windows_setup.ps1`.

## Hardware-Hinweis

[CAT](https://en.wikipedia.org/wiki/Computer_Aided_Transceiver)-Leitungen des Funkgeräts sind oft **5 V [TTL](https://de.wikipedia.org/wiki/Transistor-Transistor-Logik)** – zwischen [ESP32](https://de.wikipedia.org/wiki/ESP32) (3,3 V) und Radio einen **Bidirectional-[Level-Shifter](https://de.wikipedia.org/wiki/Pegelwandler)** verwenden (kein [MAX3232](https://de.wikipedia.org/wiki/MAX3232), sofern kein echtes [RS-232](https://de.wikipedia.org/wiki/RS-232) ±12 V).

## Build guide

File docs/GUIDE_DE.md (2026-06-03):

# [ESP32](https://de.wikipedia.org/wiki/ESP32) [CAT](https://en.wikipedia.org/wiki/Computer_Aided_Transceiver) Remote Panel — Ausführlicher Leitfaden

> **Kurzübersicht & Interface-Shield:** [README.md](../README.md) · [Shield](../hardware/esp32-flrig-shield/README.md) · [Glossar](GLOSSARY.md#deutsch)  
> **[Rotor](https://de.wikipedia.org/wiki/Rotor_(Antenne)) ([rotctld](https://hamlib.sourceforge.net/html/rotctld.1.html), [GPIO](https://de.wikipedia.org/wiki/General_Purpose_Input/Output)):** vollständig im [README — Rotor](../README.md#4--rotor-hamlib-[rotctld](https://hamlib.sourceforge.net/html/rotctld.1.html))

[ESP32](https://de.wikipedia.org/wiki/ESP32)-basiertes Funkfernbedienungs-Panel mit Touch-Display, 5 programmierbaren [Potentiometern](https://de.wikipedia.org/wiki/Potentiometer), universeller **[ICOM](https://de.wikipedia.org/wiki/Icom) [CI-V](https://de.wikipedia.org/wiki/CI-V)** / **[Yaesu CAT](https://en.wikipedia.org/wiki/Computer_Aided_Transceiver)**-Steuerung, **Audio-Bridge** über [WiFi](https://de.wikipedia.org/wiki/WLAN) und **[FT8](https://de.wikipedia.org/wiki/FT8_(Amateurfunk))/[WSJT-X](https://physics.princeton.edu/pulsar/k1jt/wsjtx.html)**-Fernbetrieb ([Windows](https://de.wikipedia.org/wiki/Microsoft_Windows) & [Linux](https://de.wikipedia.org/wiki/Linux)). Kompatibel mit **[flrig](https://github.com/w1hkj/flrig)**, **[WSJT-X](https://physics.princeton.edu/pulsar/k1jt/wsjtx.html)** und **[Hamlib rigctld](https://hamlib.sourceforge.net/html/rigctld.1.html)** (Port 4532).

## Architektur

```
┌─────────────┐   WiFi/TCP:4532    ┌──────────────┐     I2S      ┌─────────┐
│ flrig/fldigi│◄──────────────────►│   ESP32      │◄────────────►│ Funk    │
│ WSJT-X etc. │   rigctl           │  rigctld     │   CAT UART   │ ICOM /  │
└─────────────┘                    │  Audio-UDP   │              │ YAESU   │
       ▲                           │  :4533/4534  │              └─────────┘
       │  optional                 └──────┬───────┘
       │  PCM 16 kHz mono                │ LVGL / Potis
┌──────┴──────┐                          │
│ PC / Browser│  UDP oder WebSocket /ws/audio
└─────────────┘
```

### Betriebsmodi

| Modus | Beschreibung |
|---|---|
| **DIRECT_CAT** (Standard) | [ESP32](https://de.wikipedia.org/wiki/ESP32) steuert das [Funkgerät](https://de.wikipedia.org/wiki/Transceiver) direkt per [UART](https://de.wikipedia.org/wiki/Asynchrone_Serielle_Schnittstelle) |
| **Client → [flrig](https://github.com/w1hkj/flrig)** | [ESP32](https://de.wikipedia.org/wiki/ESP32) als [rigctl](https://hamlib.sourceforge.net/html/rigctl.1.html)-Client zu PC mit [flrig](https://github.com/w1hkj/flrig) (Modell 4, Port 12345) |
| **Client → [rigctld](https://hamlib.sourceforge.net/html/rigctld.1.html)** | [ESP32](https://de.wikipedia.org/wiki/ESP32) als Client zu [Hamlib](https://en.wikipedia.org/wiki/Hamlib) [rigctld](https://hamlib.sourceforge.net/html/rigctld.1.html) auf dem PC |

## Hardware

### Empfohlen: [ESP32](https://de.wikipedia.org/wiki/ESP32)-2432S028 ([Cheap Yellow Display](https://de.wikipedia.org/wiki/ESP32-Cheap-Yellow-Display))

| Funktion | [GPIO](https://de.wikipedia.org/wiki/General_Purpose_Input/Output) |
|---|---|
| [CAT](https://en.wikipedia.org/wiki/Computer_Aided_Transceiver) RX | 16 |
| [CAT](https://en.wikipedia.org/wiki/Computer_Aided_Transceiver) TX | 17 |
| [I2S](https://de.wikipedia.org/wiki/I%C2%B2S) BCLK / LRCK | 26 / 25 |
| [I2S](https://de.wikipedia.org/wiki/I%C2%B2S) DOUT (→ DAC, Mic-In) | 22 |
| [I2S](https://de.wikipedia.org/wiki/I%C2%B2S) DIN (← ADC, Line-Out) | 4 |
| Poti 1–5 | 32, 35, 34, 39, 36 |
| Display/Touch | onboard (ILI9341 + XPT2046) |

GPIO33 ist auf dem [CYD](https://github.com/witnessmenow/ESP32-Cheap-Yellow-Display) **Touch-CS** – nicht als Poti belegen (siehe `include/config.h`).

### Pinbelegung (Übersicht)

| Bereich | [CYD](https://github.com/witnessmenow/ESP32-Cheap-Yellow-Display) | T-Display | Belegung |
|---|-----|---|---|
| Display SPI | 13, 14, 15, 2, 21 | 19, 18, 5, 16, 23, 4 | onboard |
| Touch CS | 33 | – | nur [CYD](https://github.com/witnessmenow/ESP32-Cheap-Yellow-Display) |
| [CAT](https://en.wikipedia.org/wiki/Computer_Aided_Transceiver) [UART](https://de.wikipedia.org/wiki/Asynchrone_Serielle_Schnittstelle) | 16 RX, 17 TX | 27 RX, 17 TX | [Level-Shifter](https://de.wikipedia.org/wiki/Pegelwandler) |
| [I2S](https://de.wikipedia.org/wiki/I%C2%B2S) Audio | 26 BCLK, 25 LRCK, 22 DOUT, 4 DIN | 12–15 | siehe Audio |
| [Potis](https://de.wikipedia.org/wiki/Potentiometer) ADC | 32, 35, 34, 39, 36 | 32, 33, 25, 26, 34 | 10 kΩ |
| Tasten | – | 35, 0 | nur T-Display |

---

## Vollständiger Schaltplan

Das System besteht aus vier Pfaden: **Stromversorgung**, **[CAT](https://en.wikipedia.org/wiki/Computer_Aided_Transceiver)**, **Audio ([I2S](https://de.wikipedia.org/wiki/I%C2%B2S))** und **Bedienung ([Potis](https://de.wikipedia.org/wiki/Potentiometer)/Display)**. Alle Massen ([ESP32](https://de.wikipedia.org/wiki/ESP32), Shifter, [I2S](https://de.wikipedia.org/wiki/I%C2%B2S)-Module, [Funkgerät](https://de.wikipedia.org/wiki/Transceiver)) über **einen gemeinsamen GND-Stern** verbinden.

```mermaid
flowchart TB
  subgraph power["Stromversorgung"]
    USB["USB 5 V\n(CYD / T-Display)"]
    REG["Onboard 3,3 V Regler"]
    USB --> REG
  end

  subgraph esp["ESP32 Panel (CYD)"]
    MCU["ESP32"]
    TFT["ILI9341 Display\nSPI: 13,14,15,2,21"]
    TCH["XPT2046 Touch\nCS: 33"]
    WIFI["WiFi AP/STA"]
    MCU --- TFT
    MCU --- TCH
    MCU --- WIFI
  end

  subgraph pots["5× Potentiometer 10 kΩ"]
    P1["Poti 1 → GPIO32"]
    P2["Poti 2 → GPIO35"]
    P3["Poti 3 → GPIO34"]
    P4["Poti 4 → GPIO39"]
    P5["Poti 5 → GPIO36"]
  end

  subgraph catpath["CAT / CI-V (TTL)"]
    SH["Level-Shifter\nTXS0108E o. ä.\nVCCA=3V3 VCCB=5V"]
    CAT["Funk REMOTE / CI-V\nRX / TX / GND"]
    MCU -->|"GPIO17 TX"| SH
    SH -->|"GPIO16 RX"| MCU
    SH <-->|"5V TTL"| CAT
  end

  subgraph audiopath["Audio I2S (optional)"]
    ADC["I2S-ADC\nz. B. INMP441"]
    DAC["I2S-DAC\nz. B. PCM5102"]
    LINEOUT["Funk AF Out\nLINE/SPKR"]
    LINEIN["Funk Mic/Line In"]
    MCU -->|"BCLK26 LRCK25"| ADC
    MCU -->|"BCLK26 LRCK25"| DAC
    MCU -->|"DIN GPIO4"| ADC
    MCU -->|"DOUT GPIO22"| DAC
    LINEOUT -->|"Audio IN"| ADC
    DAC -->|"Audio OUT"| LINEIN
  end

  subgraph client["Fernbedienung PC/Tablet"]
    PC["Browser / flrig\nrigctl UDP :4532"]
    AUD["Audio Client\nUDP :4533 / :4534\noder /ws/audio"]
  end

  REG --> MCU
  REG --> pots
  REG --> SH
  REG --> ADC
  REG --> DAC
  WIFI <-->|"TCP 4532 CAT-Proxy"| PC
  WIFI <-->|"PCM 16 kHz"| AUD

  pots --> MCU
```

### Schaltplan [CAT](https://en.wikipedia.org/wiki/Computer_Aided_Transceiver) + [Potis](https://de.wikipedia.org/wiki/Potentiometer) (Detail, [CYD](https://github.com/witnessmenow/ESP32-Cheap-Yellow-Display))

```
                         ┌──────────────────────────────────────────────────────────┐
    USB 5V ─────────────►│ ESP32-2432S028 (CYD)                                     │
                         │                                                          │
    3V3 ────┬────────────┤ VCC                                                      │
            │            │                                                          │
            │    ┌───────┴───────┐                                                  │
            │    │ Level-Shifter │  VCCA ◄── 3V3        VCCB ◄── Funk +5V (oder 5V-Regler) │
            │    │  (bidirekt.)  │  GND  ◄──┴──────────────┴── Funk GND / ESP GND       │
            │    │               │                                                       │
            ├───►│ A1 ─── B1 ────┼──────────────────────────► Funk CAT RX              │
            │    │ A2 ◄── B2 ◄───┼────────────────────────── Funk CAT TX              │
            │    └───────────────┘                                                       │
            │         ▲           ▲                                                      │
            │    GPIO17 TX   GPIO16 RX                                                   │
            │                                                                            │
            │    Poti 1..5:  3V3 ──[10k]──┬── GPIO 32,35,34,39,36 ──[100nF optional]── GND
            │                            Mitte                                           │
            │    Display/Touch: onboard (GPIO 2,13,14,15,21,33)                          │
            │                                                                            │
            │    I2S (optional):                                                         │
            │      GPIO26 BCLK ─────┬────────────── PCM5102 BCK / INMP441 SCK            │
            │      GPIO25 LRCK ─────┼────────────── PCM5102 LCK / INMP441 WS             │
            │      GPIO22 DOUT ────────────────► PCM5102 DIN                             │
            │      GPIO4  DIN  ◄──────────────── INMP441 SD                              │
            │      3V3, GND ─────────────────── beide Module                             │
            └──────────────────────────────────────────────────────────────────────────┘
```

### [CAT](https://en.wikipedia.org/wiki/Computer_Aided_Transceiver)-Schnittstelle ([TTL](https://de.wikipedia.org/wiki/Transistor-Transistor-Logik), kein [MAX3232](https://de.wikipedia.org/wiki/MAX3232))

Die Firmware nutzt **3,3-V-[TTL](https://de.wikipedia.org/wiki/Transistor-Transistor-Logik)-[UART](https://de.wikipedia.org/wiki/Asynchrone_Serielle_Schnittstelle)** (`SERIAL_8N1`). Moderne [ICOM](https://de.wikipedia.org/wiki/Icom)- und [Yaesu](https://de.wikipedia.org/wiki/Yaesu)-[CAT](https://en.wikipedia.org/wiki/Computer_Aided_Transceiver)-Anschlüsse sind **5-V-[TTL](https://de.wikipedia.org/wiki/Transistor-Transistor-Logik)**, nicht [RS-232](https://de.wikipedia.org/wiki/RS-232) (±12 V).

| Schnittstelle | Spannung / Logik | Für dieses Projekt |
|---|---|---|
| [ICOM](https://de.wikipedia.org/wiki/Icom) [CI-V](https://de.wikipedia.org/wiki/CI-V), [Yaesu CAT](https://en.wikipedia.org/wiki/Computer_Aided_Transceiver) (typisch) | 5-V-[TTL](https://de.wikipedia.org/wiki/Transistor-Transistor-Logik), 8N1 | **[Level-Shifter](https://de.wikipedia.org/wiki/Pegelwandler)** 3,3 V ↔ 5 V |
| Echter [RS-232](https://de.wikipedia.org/wiki/RS-232) (DE-9, ± Pegel) | [RS-232](https://de.wikipedia.org/wiki/RS-232) | **[MAX3232](https://de.wikipedia.org/wiki/MAX3232)** o. Ä. – nur wenn das [Funkgerät](https://de.wikipedia.org/wiki/Transceiver) wirklich [RS-232](https://de.wikipedia.org/wiki/RS-232) liefert |
| [USB](https://de.wikipedia.org/wiki/Universal_Serial_Bus)-[CAT](https://en.wikipedia.org/wiki/Computer_Aided_Transceiver)-Adapter am PC | [USB](https://de.wikipedia.org/wiki/Universal_Serial_Bus) → [TTL](https://de.wikipedia.org/wiki/Transistor-Transistor-Logik) im Adapter | Nicht zwischen [ESP32](https://de.wikipedia.org/wiki/ESP32) und [Funkgerät](https://de.wikipedia.org/wiki/Transceiver) |

**[MAX3232](https://de.wikipedia.org/wiki/MAX3232) ist nicht vorgesehen**, solange der [CAT](https://en.wikipedia.org/wiki/Computer_Aided_Transceiver)-Port des Funkgeräts [TTL](https://de.wikipedia.org/wiki/Transistor-Transistor-Logik) ist (Standard bei IC-7300, FTdx-Serie, u. a.). Ein [MAX3232](https://de.wikipedia.org/wiki/MAX3232) würde bei [TTL](https://de.wikipedia.org/wiki/Transistor-Transistor-Logik)-[CAT](https://en.wikipedia.org/wiki/Computer_Aided_Transceiver) die Pegel falsch wandeln und die Kommunikation stören.

#### Verdrahtung [Level-Shifter](https://de.wikipedia.org/wiki/Pegelwandler) (z. B. [TXS0108E](https://www.ti.com/product/TXS0108E), 2 Kanäle)

```
                    Level-Shifter (bidirektional)
                    ┌─────────────────────────────┐
  ESP32 3V3 ────────┤ VCCA                        │
  Funk  +5V ────────┤ VCCB   (Referenz vom Radio │
  gemeinsam GND ────┤ GND    oder 5V-Regler)    │
                    │                             │
  GPIO17 TX ────────┤ A1 ─────────── B1 ─────────┼──► Funk RX
  GPIO16 RX ◄───────┤ A2 ─────────── B2 ◄────────┼──── Funk TX
                    └─────────────────────────────┘

  ESP32 GND ─────────────── gemeinsam ───────────── Funk GND
```

| Signal | [ESP32](https://de.wikipedia.org/wiki/ESP32) (3,3 V) | Shifter | [Funkgerät](https://de.wikipedia.org/wiki/Transceiver) (5 V [TTL](https://de.wikipedia.org/wiki/Transistor-Transistor-Logik)) |
|---|---|---|---|
| Senden | GPIO17 → A1 | B1 → | [CAT](https://en.wikipedia.org/wiki/Computer_Aided_Transceiver) **RX** |
| Empfangen | GPIO16 ← A2 | B2 ← | [CAT](https://en.wikipedia.org/wiki/Computer_Aided_Transceiver) **TX** |
| Masse | GND | GND | GND |

**Hinweise:**

- TX/RX **kreuzen**: ESP-TX → Funk-RX, ESP-RX ← Funk-TX.
- Nur **ein** GND zwischen Panel, Shifter und [Funkgerät](https://de.wikipedia.org/wiki/Transceiver); lange gemeinsame Masseleitung vermeiden.
- Baudrate in der Web-UI wählen: [ICOM](https://de.wikipedia.org/wiki/Icom) meist **19200**, [Yaesu](https://de.wikipedia.org/wiki/Yaesu) meist **38400** (modellabhängig).
- 3,3-V-[TTL](https://de.wikipedia.org/wiki/Transistor-Transistor-Logik)-[CAT](https://en.wikipedia.org/wiki/Computer_Aided_Transceiver) (selten): Shifter optional; Radio-Datenblatt prüfen, ob 3,3 V tolerant ist.

#### [RS-232](https://de.wikipedia.org/wiki/RS-232) nur bei Bedarf (Sonderfall)

```
ESP32 GPIO17/16 ──► MAX3232 TTL-Seite ──► DE-9 RS-232 ──► Funk/Adapter (RS-232)
```

Nur verwenden, wenn der Hersteller ausdrücklich einen **[RS-232](https://de.wikipedia.org/wiki/RS-232)**-[CAT](https://en.wikipedia.org/wiki/Computer_Aided_Transceiver)-Port dokumentiert. Die Firmware bleibt unverändert; nur die Hardware wandelt die Pegel.

### [Potentiometer](https://de.wikipedia.org/wiki/Potentiometer) (5×)

```
        3V3
         │
    ┌────┴────┐
   ╱           ╲
  │  10 kΩ     │  Poti (Bourns/trimmer o. ä.)
  │            │
  └─────┬──────┘
        │
        ├────────────► GPIO (ADC, siehe Pin-Tabelle)
        │
       GND
```

| Poti | [CYD](https://github.com/witnessmenow/ESP32-Cheap-Yellow-Display) (`esp32-cyd`) | T-Display (`esp32-tdisplay`) |
|---|---|---|
| 1 | GPIO32 | GPIO32 |
| 2 | GPIO35 | GPIO33 |
| 3 | GPIO34 | GPIO25 |
| 4 | GPIO39 | GPIO26 |
| 5 | GPIO36 | GPIO34 |

- Widerstandswert **10 kΩ** (typisch), Mittelabgriff an [GPIO](https://de.wikipedia.org/wiki/General_Purpose_Input/Output), Außen an **3,3 V** und **GND**.
- Nur **3,3 V** am ADC – nie 5 V direkt an [GPIO](https://de.wikipedia.org/wiki/General_Purpose_Input/Output).
- Entstörung optional: **100 nF** von Mittelabgriff nach GND, nah am Poti.

### [Stückliste](https://de.wikipedia.org/wiki/St%C3%BCckliste) (komplett)

| Stück | Wert / Typ | Anzahl | Anmerkung |
|---|---|---|---|
| [ESP32](https://de.wikipedia.org/wiki/ESP32)-2432S028 ([CYD](https://github.com/witnessmenow/ESP32-Cheap-Yellow-Display)) oder [TTGO](https://en.wikipedia.org/wiki/LilyGo) T-Display | – | 1 | `platformio.ini` |
| [Level-Shifter](https://de.wikipedia.org/wiki/Pegelwandler) | [TXS0108E](https://www.ti.com/product/TXS0108E), BSS138-Modul | 1 | [CAT](https://en.wikipedia.org/wiki/Computer_Aided_Transceiver): 2 Kanäle |
| [Potentiometer](https://de.wikipedia.org/wiki/Potentiometer) | 10 kΩ linear | 5 | ADC 3,3 V |
| Kabel | abgeschirmt | – | [CAT](https://en.wikipedia.org/wiki/Computer_Aided_Transceiver) + Audio getrennt |
| 100 nF [Keramik](https://de.wikipedia.org/wiki/Keramikkondensator) | – | 5–7 | Poti + Audio |
| **Audio IN (Empfang)** | [INMP441](https://www.invensense.com/products/digital/inmp441/) / ICS-43434 | 1 | [I2S](https://de.wikipedia.org/wiki/I%C2%B2S)-ADC |
| **Audio OUT (Senden)** | [PCM5102](https://www.ti.com/product/PCM5102) / [MAX98357A](https://www.analog.com/en/products/max98357a.html) | 1 | [I2S](https://de.wikipedia.org/wiki/I%C2%B2S)-DAC |
| [Elko](https://de.wikipedia.org/wiki/Elektrolytkondensator) / MKP | 10 µF | 2 | AC-Kopplung Audio |
| Widerstände | 10 kΩ, 22 kΩ, 1 kΩ | je 2 | Teiler + Pegel |
| Trimmer | 10 kΩ | 1 | Mic-Pegel einstellen |

> **Hinweis [CYD](https://github.com/witnessmenow/ESP32-Cheap-Yellow-Display) + Audio:** Auf dem [ESP32](https://de.wikipedia.org/wiki/ESP32)-2432S028 ist **GPIO26** auf manchen Revisionen mit dem **onboard-Lautsprecher-Verstärker (PAM8302)** verbunden. Die Firmware nutzt GPIO26 als **[I2S](https://de.wikipedia.org/wiki/I%C2%B2S) BCLK**. Funktioniert [I2S](https://de.wikipedia.org/wiki/I%C2%B2S) nicht stabil, in `include/config.h` andere freie Pins wählen oder Lautsprecher-Funktion des [CYD](https://github.com/witnessmenow/ESP32-Cheap-Yellow-Display) nicht verwenden.

---

### Beschaffung ([AliExpress](https://de.wikipedia.org/wiki/AliExpress)) und Modul-Anschluss

Die Links sind **Suchseiten** (Händler und Artikelnummern wechseln). Vor dem Kauf prüfen: Bewertungen, „[ESP32](https://de.wikipedia.org/wiki/ESP32)-2432S028“ / „[INMP441](https://www.invensense.com/products/digital/inmp441/)“ / „[PCM5102](https://www.ti.com/product/PCM5102)“ im Titel, Spannung **3,3 V** für [I2S](https://de.wikipedia.org/wiki/I%C2%B2S)-Module.

| # | Bauteil | [AliExpress](https://de.wikipedia.org/wiki/AliExpress) (Suche) | Anschluss-Kurzinfo |
|---|---|---|---|
| 1 | **[ESP32](https://de.wikipedia.org/wiki/ESP32)-2432S028 ([CYD](https://github.com/witnessmenow/ESP32-Cheap-Yellow-Display))** | [ESP32-2432S028](https://de.wikipedia.org/wiki/ESP32-2432S028.html) | [USB](https://de.wikipedia.org/wiki/Universal_Serial_Bus)-Strom, Display/Touch onboard; freie Pins an P3/CN1 (siehe Pinout) |
| 2 | **[TTGO](https://en.wikipedia.org/wiki/LilyGo) T-Display v1.1** (Alternative) | [TTGO T-Display](https://de.wikipedia.org/wiki/ESP32.html) | Kompakter, kein Touch; [I2S](https://de.wikipedia.org/wiki/I%C2%B2S) auf [GPIO](https://de.wikipedia.org/wiki/General_Purpose_Input/Output) 12–15 |
| 3 | **[Level-Shifter](https://de.wikipedia.org/wiki/Pegelwandler) 3,3↔5 V** | [TXS0108E 4-Kanal](https://www.aliexpress.com/w/wholesale-TXS0108E-level-shifter.html) · [BSS138 Modul](https://www.aliexpress.com/w/wholesale-BSS138-level-shifter-module.html) | 2 Kanäle für [CAT](https://en.wikipedia.org/wiki/Computer_Aided_Transceiver) TX/RX, siehe [CAT-Modul](#3-level-shifter-cat--ci-v) |
| 4 | **[INMP441](https://www.invensense.com/products/digital/inmp441/) [I2S](https://de.wikipedia.org/wiki/I%C2%B2S)** (Audio IN) | [INMP441 Modul](https://www.invensense.com/products/digital/inmp441/-I2S-module.html) | Empfang vom Funk-Line-Out, siehe [Audio IN Modul](#4-inmp441-audio-in--empfang-vom-funk) |
| 5 | **[PCM5102](https://www.ti.com/product/PCM5102) [I2S](https://de.wikipedia.org/wiki/I%C2%B2S) DAC** (Audio OUT) | [PCM5102 Modul](https://www.aliexpress.com/w/wholesale-PCM5102-I2S-DAC.html) | Zum Funk-Line/Mic-In, siehe [Audio OUT Modul](#5-pcm5102-audio-out--senden-zum-funk) |
| 5b | Alternative DAC+Verstärker | [MAX98357A I2S](https://de.wikipedia.org/wiki/I%C2%B2S.html) | Lauterer Ausgang; Pegel ggf. noch dämpfen vor TRX |
| 6 | **[Potentiometer](https://de.wikipedia.org/wiki/Potentiometer) 10 kΩ** | [10 kΩ linear](https://www.aliexpress.com/w/wholesale-10k-rotary-potentiometer-linear.html) | 5× 3V3–Mitte–GND, siehe [Potis](#6-potentiometer) |
| 7 | **Widerstandsset** | [Widerstand Kit 10k 22k](https://www.aliexpress.com/w/wholesale-resistor-kit-1-4w.html) | Audio-Teiler + optional Pull-ups |
| 8 | **Kondensatoren 10 µF** | [10uF electrolytic](https://www.aliexpress.com/w/wholesale-10uf-capacitor.html) | Audio-Kopplung (elektrolytisch, Beobachtung Polung) |
| 9 | **[Dupont](https://de.wikipedia.org/wiki/Steckbrett#Steckbrücken)-Kabel** | [Dupont 40 Stück](https://www.aliexpress.com/w/wholesale-dupont-jumper-wires.html) | Female-Female für Breadboard |
| 10 | **[Steckbrett](https://de.wikipedia.org/wiki/Steckbrett)** (optional) | [Breadboard 830](https://www.aliexpress.com/w/wholesale-breadboard-830.html) | Prototyp vor fester Verdrahtung |
| 11 | **3,5-mm-Klinkenkabel** | [3.5mm audio cable](https://www.aliexpress.com/w/wholesale-3.5mm-audio-cable.html) | Funk Line-Out / Line-In (mono reicht, Stereo nur einen Kanal nutzen) |
| 12 | **[CI-V](https://de.wikipedia.org/wiki/CI-V) / Datenkabel** ([ICOM](https://de.wikipedia.org/wiki/Icom)) | [3.5mm TRS cable](https://www.aliexpress.com/w/wholesale-3.5mm-trs-cable.html) | Nur wenn Funk [CI-V](https://de.wikipedia.org/wiki/CI-V) an Klinkenbuchse hat – Pinbelegung im Handbuch! |

**Beispiel-Listing [CYD](https://github.com/witnessmenow/ESP32-Cheap-Yellow-Display)** (Varianten prüfen): [ESP32-2432S028 bei AliExpress](https://www.aliexpress.com/item/1005009152117243.html) – Titel muss **2432S028** enthalten; Display-Treiber ILI9341 oder ST7789 ist für diese Firmware unkritisch (`BOARD_CYD`).

#### Montage-Reihenfolge (empfohlen)

1. [CYD](https://github.com/witnessmenow/ESP32-Cheap-Yellow-Display) flashen und [CAT](https://en.wikipedia.org/wiki/Computer_Aided_Transceiver) ohne Audio testen ([Level-Shifter](https://de.wikipedia.org/wiki/Pegelwandler) + [Potis](https://de.wikipedia.org/wiki/Potentiometer)).
2. [INMP441](https://www.invensense.com/products/digital/inmp441/) + [PCM5102](https://www.ti.com/product/PCM5102) auf Breadboard verdrahten, gemeinsame I2S-Leitungen (BCLK/LRCK).
3. Audio-Pegelanpassung (10 µF, Teiler) **ohne** Funk testen (Web-UI `/audio`).
4. Zuletzt Funk Line-Out / Line-In mit niedrigem AF-Pegel anbinden.

---

#### 1. [ESP32](https://de.wikipedia.org/wiki/ESP32)-2432S028 ([CYD](https://github.com/witnessmenow/ESP32-Cheap-Yellow-Display)) – Basisplatine

| Anschluss am Board | Verwendung in diesem Projekt |
|---|---|
| **Micro-[USB](https://de.wikipedia.org/wiki/Universal_Serial_Bus)** | 5 V Versorgung + Flash |
| **P3 / CN1** (3V3, GND, [GPIO](https://de.wikipedia.org/wiki/General_Purpose_Input/Output)) | [CAT](https://en.wikipedia.org/wiki/Computer_Aided_Transceiver), I2S, [Potis](https://de.wikipedia.org/wiki/Potentiometer) |
| **Onboard Display/Touch** | UI – keine Extra-Verdrahtung |

**Nicht belegen:** [GPIO](https://de.wikipedia.org/wiki/General_Purpose_Input/Output) **33** (Touch-CS), Display-SPI **2, 13, 14, 15, 21**.

Frei nutzbar ([CYD](https://github.com/witnessmenow/ESP32-Cheap-Yellow-Display), typisch): **4, 16, 17, 22, 25, 26, 27, 32, 34, 35, 36, 39** – genaue Belegung siehe Pin-Tabelle oben (26 ggf. Konflikt Lautsprecher).

---

#### 2. [Potentiometer](https://de.wikipedia.org/wiki/Potentiometer)

Typisches Modul mit **3 Pins** (links/rechts = Außen, Mitte = Schleifer):

```
Pin links  ──────── 3V3 (ESP)
Pin mitte  ──────── GPIOxx (Poti 1…5)
Pin rechts ──────── GND
```

| Poti # | [CYD](https://github.com/witnessmenow/ESP32-Cheap-Yellow-Display) [GPIO](https://de.wikipedia.org/wiki/General_Purpose_Input/Output) | Kabelfarbe (Beispiel) |
|---|---|---|
| 1 | 32 | zu P3 |
| 2 | 35 | nur Input – gut für ADC |
| 3 | 34 | |
| 4 | 39 | nur Input |
| 5 | 36 | |

Optional **100 nF** zwischen Mitte und GND, direkt am Poti.

---

#### 3. [Level-Shifter](https://de.wikipedia.org/wiki/Pegelwandler) ([CAT](https://en.wikipedia.org/wiki/Computer_Aided_Transceiver) / [CI-V](https://de.wikipedia.org/wiki/CI-V))

Typisches **4-Kanal-BSS138-** oder **[TXS0108E](https://www.ti.com/product/TXS0108E)-Breakout**:

| Shifter-Pin | Verbindung |
|---|---|
| **VCCA** / **LV** | ESP **3,3 V** |
| **VCCB** / **HV** | Funk **+5 V** (vom [CAT](https://en.wikipedia.org/wiki/Computer_Aided_Transceiver)-Port oder [USB](https://de.wikipedia.org/wiki/Universal_Serial_Bus)-Netzteil 5 V, **GND gemeinsam**) |
| **GND** | ESP GND + Funk GND |
| **A1** | ESP **GPIO17** (TX) |
| **B1** | Funk **RX** ([CAT](https://en.wikipedia.org/wiki/Computer_Aided_Transceiver) empfängt Befehle) |
| **A2** | ESP **GPIO16** (RX) |
| **B2** | Funk **TX** ([CAT](https://en.wikipedia.org/wiki/Computer_Aided_Transceiver) sendet Antworten) |

```
ESP TX (17) ──► A1 ── B1 ──► Funk RX
ESP RX (16) ◄── A2 ◄── B2 ◄── Funk TX
```

**[ICOM](https://de.wikipedia.org/wiki/Icom) [CI-V](https://de.wikipedia.org/wiki/CI-V) (3,5-mm-TRS):** Pinbelegung je Modell unterschiedlich (Ring/Sleeve = GND/ Daten). Nur mit offiziellem Kabel oder Pinout im Handbuch – falsche Belegung zerstört [CI-V](https://de.wikipedia.org/wiki/CI-V).

**[Yaesu](https://de.wikipedia.org/wiki/Yaesu):** oft Mini-DIN oder 3,5 mm; ebenfalls Handbuch prüfen.

---

#### 4. [INMP441](https://www.invensense.com/products/digital/inmp441/) (Audio IN – Empfang vom Funk)

Typische Beschriftung auf dem **[INMP441](https://www.invensense.com/products/digital/inmp441/)-Breakout**:

| [INMP441](https://www.invensense.com/products/digital/inmp441/) | [ESP32](https://de.wikipedia.org/wiki/ESP32) [CYD](https://github.com/witnessmenow/ESP32-Cheap-Yellow-Display) | Hinweis |
|---|---|---|
| **VDD** | 3,3 V | nie 5 V |
| **GND** | GND | |
| **SCK** / **BCLK** | [GPIO](https://de.wikipedia.org/wiki/General_Purpose_Input/Output) **26** | gemeinsam mit [PCM5102](https://www.ti.com/product/PCM5102) BCK |
| **WS** / **LRCK** | [GPIO](https://de.wikipedia.org/wiki/General_Purpose_Input/Output) **25** | gemeinsam mit [PCM5102](https://www.ti.com/product/PCM5102) LCK |
| **SD** / **DOUT** | [GPIO](https://de.wikipedia.org/wiki/General_Purpose_Input/Output) **4** (ESP [I2S](https://de.wikipedia.org/wiki/I%C2%B2S) DIN) | Daten vom Mikro/ADC zum ESP |
| **L/R** | **GND** | Mono = linker Kanal |
| **SEL** | GND oder 3,3 V | Datenblatt des Moduls |

**Analog vom Funk (Line-Out):**

```
Funk Tip/Ring (LINE +) ── 10 µF (+ zur Funk-Seite) ──┬── 10 kΩ ── INMP441 SD
Funk Sleeve (GND) ─────────────────────────────────┴── 22 kΩ ── GND
```

- AF am Funk **niedrig** starten (z. B. 10–20 %), sonst Clipping am ADC.
- **Kein** Speaker-Output des Funkgeräts direkt an [INMP441](https://www.invensense.com/products/digital/inmp441/) – immer Line-Out / DATA-Out nutzen.

---

#### 5. [PCM5102](https://www.ti.com/product/PCM5102) (Audio OUT – Senden zum Funk)

Typische Beschriftung **[PCM5102A](https://www.ti.com/product/PCM5102)-Modul** (ohne Verstärker):

| [PCM5102](https://www.ti.com/product/PCM5102) | [ESP32](https://de.wikipedia.org/wiki/ESP32) [CYD](https://github.com/witnessmenow/ESP32-Cheap-Yellow-Display) | Hinweis |
|---|---|---|
| **VIN** / **5V** | 5 V [USB](https://de.wikipedia.org/wiki/Universal_Serial_Bus) oder 3,3 V (nur wenn Modul 3,3-V-tauglich laut Beschreibung) | Modulbeschreibung lesen |
| **GND** | GND | |
| **BCK** | [GPIO](https://de.wikipedia.org/wiki/General_Purpose_Input/Output) **26** | mit [INMP441](https://www.invensense.com/products/digital/inmp441/) gemeinsam |
| **LCK** / **LRCK** | [GPIO](https://de.wikipedia.org/wiki/General_Purpose_Input/Output) **25** | |
| **DIN** | [GPIO](https://de.wikipedia.org/wiki/General_Purpose_Input/Output) **22** (ESP [I2S](https://de.wikipedia.org/wiki/I%C2%B2S) DOUT) | |
| **SCK** | **GND** (bei [PCM5102](https://www.ti.com/product/PCM5102) oft nicht nötig) | laut Modul-Anleitung |
| **VOUTL** / **ROUT** | über 10 µF + Trimmer zum Funk | Mono: einen Kanal nutzen |

**Zum [Funkgerät](https://de.wikipedia.org/wiki/Transceiver):**

```
PCM5102 VOUT ── 10 µF ── Mitte Trimmer 10 kΩ ── Funk LINE IN (+)
Trimmer andere Seite ── GND; Funk LINE GND ── gemeinsam ESP GND
```

- **IC-7300:** bevorzugt **LINE IN** (hinten), nicht HS-Mic ohne Adapter.
- Pegel mit Trimmer einstellen: zu laut → Übersteuerung / ALC-Pumpen; zu leise → kaum Modulation.
- **[PTT](https://de.wikipedia.org/wiki/Sende-Empfang-Umschaltung)** bleibt am Mikrofon des Funkgeräts oder per [CAT](https://en.wikipedia.org/wiki/Computer_Aided_Transceiver) (`T` / [rigctl](https://hamlib.sourceforge.net/html/rigctl.1.html)).

**[MAX98357A](https://www.analog.com/en/products/max98357a.html)** statt [PCM5102](https://www.ti.com/product/PCM5102): gleiche [I2S](https://de.wikipedia.org/wiki/I%C2%B2S)-Pins (BCLK/LRCK/DIN), Ausgang oft lauter – **zusätzlicher** Trimmer oder Widerstand vor dem TRX empfohlen.

---

#### 6. Übersicht: alle Verbindungen [CYD](https://github.com/witnessmenow/ESP32-Cheap-Yellow-Display) auf einen Blick

| ESP [GPIO](https://de.wikipedia.org/wiki/General_Purpose_Input/Output) | Richtung | Ziel |
|---|---|---|
| 17 | OUT | [Level-Shifter](https://de.wikipedia.org/wiki/Pegelwandler) A1 → Funk [CAT](https://en.wikipedia.org/wiki/Computer_Aided_Transceiver) RX |
| 16 | IN | [Level-Shifter](https://de.wikipedia.org/wiki/Pegelwandler) A2 ← Funk [CAT](https://en.wikipedia.org/wiki/Computer_Aided_Transceiver) TX |
| 26 | OUT | [INMP441](https://www.invensense.com/products/digital/inmp441/) SCK + [PCM5102](https://www.ti.com/product/PCM5102) BCK |
| 25 | OUT | [INMP441](https://www.invensense.com/products/digital/inmp441/) WS + [PCM5102](https://www.ti.com/product/PCM5102) LCK |
| 4 | IN | [INMP441](https://www.invensense.com/products/digital/inmp441/) SD |
| 22 | OUT | [PCM5102](https://www.ti.com/product/PCM5102) DIN |
| 32, 35, 34, 39, 36 | IN | Poti 1…5 (Mitte) |
| 3V3 | PWR | Shifter VCCA, [INMP441](https://www.invensense.com/products/digital/inmp441/), [PCM5102](https://www.ti.com/product/PCM5102) (falls 3,3 V) |
| GND | — | Shifter, Funk, alle Module, Poti |

[Dupont](https://de.wikipedia.org/wiki/Steckbrett#Steckbrücken)-Länge **unter 20 cm** für [I2S](https://de.wikipedia.org/wiki/I%C2%B2S) und [CAT](https://en.wikipedia.org/wiki/Computer_Aided_Transceiver); Audio- und [CAT](https://en.wikipedia.org/wiki/Computer_Aided_Transceiver)-Masse an **einem Punkt** am ESP-GND sammeln.

---

## Audio IN und Audio OUT (Hardware + Firmware)

Die Audio-Funktion trennt **Funk-Audio** (analog am TRX) und **Remote-Audio** (digital über [WiFi](https://de.wikipedia.org/wiki/WLAN)). [CAT](https://en.wikipedia.org/wiki/Computer_Aided_Transceiver) und Audio sind elektrisch getrennt; nur GND ist gemeinsam.

### Funktion in einem Satz

| Pfad | Kurzname | Analog | Digital ([ESP32](https://de.wikipedia.org/wiki/ESP32)) | Netz zum Client |
|---|---|---|---|---|
| **Audio IN** | Funk → Remote | Empfänger AF am Line-Out | [I2S](https://de.wikipedia.org/wiki/I%C2%B2S) **DIN** (GPIO4) → PCM-Pakete | [UDP](https://de.wikipedia.org/wiki/User_Datagram_Protocol) **4533** / WebSocket |
| **Audio OUT** | Remote → Funk | Mic- oder Line-In am TRX | [I2S](https://de.wikipedia.org/wiki/I%C2%B2S) **DOUT** (GPIO22) ← PCM vom Client | [UDP](https://de.wikipedia.org/wiki/User_Datagram_Protocol) **4534** / WebSocket |

### Signalweg Audio IN (Empfang vom [Funkgerät](https://de.wikipedia.org/wiki/Transceiver))

```
Funk LINE OUT / EXT SPKR
        │
        │  ~100 mV … 2 Vpp (je nach AF-Lautstärke am TRX)
        ▼
   ┌─────────┐
   │ 10 µF   │  Koppelkondensator (Audio+, kein DC auf ADC)
   └────┬────┘
        ├────── R1 10 kΩ ────┬──► zu I2S-ADC (INMP441 SD / DATA)
        │                    │
        └── R2 22 kΩ ── GND  │   Spannungsteiler auf ≤ 3,3 V
                             │
   INMP441 / ICS-43434 ◄─────┘   L/R = GND (Mono), 3,3 V Versorgung
        │  I2S: SD → ESP GPIO4 (DIN)
        │       SCK → GPIO26 (BCLK), WS → GPIO25 (LRCK)
        ▼
   ESP32 `AudioBridge`: i2s_read() alle 20 ms (320 Samples @ 16 kHz)
        ▼
   WiFi UDP Port 4533  oder  WebSocket `/ws/audio`  →  PC/Browser Lautsprecher
```

**Audio IN** bedeutet: das, was der Funk **empfängt und hörbar ausgibt**, wird abgegriffen und zum Operator am PC geschickt (Fernhören). Der TRX-**AF-Regler** beeinflusst den Pegel am Line-Out – für einen stabilen Stream ggf. AF am Radio fixieren oder den Teiler dimensionieren.

### Signalweg Audio OUT (Mikrofon zum [Funkgerät](https://de.wikipedia.org/wiki/Transceiver))

```
PC-Mikrofon / Browser
        ▼
   WiFi UDP Port 4534  oder  WebSocket `/ws/audio`
        ▼
   ESP32 `AudioBridge`: i2s_write() → GPIO22 (DOUT)
        ▼
   PCM5102 / MAX98357 (I2S-DAC) → analoge Line-Pegel ~0,5…2 Vpp
        │
   ┌────┴────┐
   │ 10 µF   │  Serie zum Funk (kein DC in Mic/Line-In)
   └────┬────┘
        ├── Trimmer 10 kΩ gegen GND (Mic-Pegel, Startstellung ~30 %)
        ▼
   Funk MIC IN oder LINE IN (Modellabhängig!)
        ▼
   TRX moduliert beim Senden (PTT weiterhin am Funk oder per CAT `T`)
```

**Audio OUT** ersetzt **nicht** automatisch das Hand-Mikrofon: viele TRX erwarten am **MIC**-Buchsen ein **bevorzugtes Electret-Mikro** mit Bias; ein reiner Line-Out des DAC ist dann eher für **LINE IN** / „Data“-Eingänge geeignet (z. B. IC-7300 LINE IN). Datenblatt des Funkgeräts prüfen.

### [I2S](https://de.wikipedia.org/wiki/I%C2%B2S)-Verdrahtung (gemeinsamer Bus, [CYD](https://github.com/witnessmenow/ESP32-Cheap-Yellow-Display))

| [I2S](https://de.wikipedia.org/wiki/I%C2%B2S)-Signal | [ESP32](https://de.wikipedia.org/wiki/ESP32) [GPIO](https://de.wikipedia.org/wiki/General_Purpose_Input/Output) | [INMP441](https://www.invensense.com/products/digital/inmp441/) (Audio IN) | [PCM5102](https://www.ti.com/product/PCM5102) (Audio OUT) |
|---|---|---|---|
| BCLK / SCK | 26 | SCK | BCK |
| LRCK / WS | 25 | WS | LCK |
| DATA IN | **4** (ESP DIN) | SD → ESP | – |
| DATA OUT | **22** (ESP DOUT) | – | DIN ← ESP |
| VCC | 3,3 V | 3,3 V | 3,3 V ([PCM5102](https://www.ti.com/product/PCM5102): 5 V nur wenn Modul es verlangt) |
| GND | GND | GND | GND |

**[TTGO](https://en.wikipedia.org/wiki/LilyGo) T-Display:** [I2S](https://de.wikipedia.org/wiki/I%C2%B2S) auf [GPIO](https://de.wikipedia.org/wiki/General_Purpose_Input/Output) **12** (BCLK), **13** (LRCK), **14** (DOUT), **15** (DIN) statt der [CYD](https://github.com/witnessmenow/ESP32-Cheap-Yellow-Display)-Pins 26/25/22/4; [CAT](https://en.wikipedia.org/wiki/Computer_Aided_Transceiver) auf **27/17**.

```mermaid
sequenceDiagram
  participant Radio as Funkgerät
  participant ADC as I2S-ADC
  participant ESP as ESP32 AudioBridge
  participant WiFi as WiFi Client
  participant DAC as I2S-DAC

  Note over Radio,ADC: Audio IN (Empfang)
  Radio->>ADC: AF Line-Out analog
  ADC->>ESP: I2S DIN GPIO4
  ESP->>WiFi: UDP :4533 / WS PCM

  Note over WiFi,DAC: Audio OUT (Senden)
  WiFi->>ESP: UDP :4534 / WS PCM
  ESP->>DAC: I2S DOUT GPIO22
  DAC->>Radio: Mic/Line-In analog
```

### Schaltplan Audio IN / OUT (empfohlene Pegelanpassung)

```
  AUDIO IN (vom Funk)                         AUDIO OUT (zum Funk)

  Funk LINE+ ───┬── 10µF ───┬── R10 10k ────┬──► INMP441 SD (→ ESP GPIO4)
                │           │               │
  Funk LINE- ───┴── GND     └── R22 22k ─── GND

  INMP441 SCK ◄── GPIO26 ────────────────┬──► PCM5102 BCK
  INMP441 WS  ◄── GPIO25 ────────────────┼──► PCM5102 LCK
  INMP441 VDD ◄── 3V3                    │
  INMP441 GND ◄── GND                    │
                                         ESP GPIO22 DOUT ──► PCM5102 DIN
                                         PCM5102 VOUT ──┬── 10µF ──┬── Trimmer 10k ──► Funk MIC/LINE +
                                                        │          └── zu GND (Pegel)
  GND gemeinsam: ESP + ADC + DAC + Funk Chassis/GND ───┴──────────────────────────── Funk GND / Shield
```

| Bauelement | Audio IN | Audio OUT |
|---|---|---|
| Koppelkondensator | 10 µF (Line+ → ADC) | 10 µF (DAC → Funk) |
| Spannungsteiler | 10 kΩ / 22 kΩ auf ≤ 3,3 V | Trimmer 10 kΩ zur Pegelreduktion |
| Typischer TRX-Anschluss | **LINE OUT**, **ACC**, **DATA** | **LINE IN** bevorzugt, sonst **MIC** mit Vorsicht |

### Firmware-Ablauf (`AudioBridge`)

1. Nach Neustart (wenn `audio_enabled: true` in Web-UI / `config.json`): [I2S](https://de.wikipedia.org/wiki/I%C2%B2S) Master **16 [kHz](https://de.wikipedia.org/wiki/Hertz)**, Mono, 16 Bit.
2. FreeRTOS-Task auf Core 0, ~alle **20 ms**:
   - **IN:** `i2s_read` → [UDP](https://de.wikipedia.org/wiki/User_Datagram_Protocol) an registrierten Client (Port **4533**) + alle WebSocket-Clients.
   - **OUT:** empfangene Pakete auf Port **4534** oder WebSocket → `i2s_write` zum DAC.
3. Erstes Paket vom Client auf **4534** speichert dessen IP für die Rückrichtung (4533).
4. Browser-UI unter `http://<ESP-IP>/audio` nutzt dasselbe PCM-Format über `/ws/audio`.

Paketformat und Client-Befehle: Abschnitt [Audio über WiFi – Konfiguration](#audio-über-wifi--konfiguration).

> **Sicherheit:** Kein direkter Anschluss von Speaker-Taps oder 13,8 V-Versorgung an [GPIO](https://de.wikipedia.org/wiki/General_Purpose_Input/Output). [PTT](https://de.wikipedia.org/wiki/Sende-Empfang-Umschaltung)/PA des Funkgeräts werden durch die Audio-Bridge **nicht** geschaltet. Hohe AF-Pegel können den ADC zerstören – Teiler und Kondensator sind Pflicht.

---

## Software bauen & flashen

### Web Flasher (empfohlen für Einsteiger)

Firmware **ohne [PlatformIO](https://platformio.org/)** per [USB](https://de.wikipedia.org/wiki/Universal_Serial_Bus) aus dem Browser installieren ([ESP Web Tools](https://esphome.github.io/esp-web-tools/)):

| Variante | Voraussetzung |
|---|---|
| **GitHub Pages** | Repository → Settings → Pages → Source: *GitHub Actions*. Danach: `https://<user>.github.io/<repo>/` (Workflow `Web Flasher`) |
| **Lokal** | Einmal bauen, dann lokalen Server starten |

```bash
./scripts/build_flasher_assets.sh   # alle Board-Varianten bauen (~3× Build)
./scripts/serve_flasher.sh          # http://127.0.0.1:8765/
```

Im Browser (Chrome / Edge / Firefox, **kein** Safari/iOS):

1. Board wählen ([CYD](https://github.com/witnessmenow/ESP32-Cheap-Yellow-Display) / T-Display / Generic)
2. **Firmware installieren** → [USB](https://de.wikipedia.org/wiki/Universal_Serial_Bus)-Port wählen
3. Optional: Standard-`config.json` per LittleFS mitflashen (Checkbox)

Bei Upload-Fehlern: **BOOT** gedrückt halten, **RESET**, BOOT loslassen, erneut flashen.

### [PlatformIO](https://platformio.org/) (Entwickler)

Voraussetzungen: [PlatformIO](https://platformio.org/)

```bash
# Python venv einrichten (empfohlen)
python3 -m venv .venv
source .venv/bin/activate
pip install platformio

# CYD-Board (Standard)
pio run -e esp32-cyd -t upload

# Generisches ILI9341-Board
pio run -e esp32-generic -t upload

# Filesystem (config.json) hochladen
pio run -e esp32-cyd -t uploadfs

# Serial Monitor
pio device monitor
```

### WSL2 unter [Windows](https://de.wikipedia.org/wiki/Microsoft_Windows)

[USB-Serial](https://de.wikipedia.org/wiki/USB_Communications_Device_Class) ist in WSL2 **nicht nativ** verfügbar. Das Board erscheint unter [Windows](https://de.wikipedia.org/wiki/Microsoft_Windows) als COM-Port (z.B. `COM5`).

```bash
# Build in WSL, Flash ueber Windows (empfohlen)
./scripts/flash.sh esp32-tdisplay
ESP_PORT=COM5 ./scripts/flash.sh esp32-tdisplay
```

Alternativ: [usbipd-win](https://learn.microsoft.com/en-us/windows/wsl/connect-usb) installieren und [USB](https://de.wikipedia.org/wiki/Universal_Serial_Bus) an [WSL](https://learn.microsoft.com/de-de/windows/wsl/) durchreichen, dann normal `pio run -t upload`.

### [TTGO](https://en.wikipedia.org/wiki/LilyGo) T-Display v1.1

Environment: `esp32-tdisplay` – ST7789 135x240, zwei Tasten statt Touch.

| Funktion | [GPIO](https://de.wikipedia.org/wiki/General_Purpose_Input/Output) |
|---|---|
| [CAT](https://en.wikipedia.org/wiki/Computer_Aided_Transceiver) RX / TX | 27 / 17 |
| Poti 1–5 | 32, 33, 25, 26, 34 |
| Taste +1 [kHz](https://de.wikipedia.org/wiki/Hertz) | 35 |
| Taste −1 [kHz](https://de.wikipedia.org/wiki/Hertz) | 0 (BOOT) |

## Erstinbetriebnahme

1. [ESP32](https://de.wikipedia.org/wiki/ESP32) flashen und einschalten
2. [WiFi](https://de.wikipedia.org/wiki/WLAN)-AP erscheint: **`[ESP32](https://de.wikipedia.org/wiki/ESP32)-CAT-Panel`** / Passwort: **`hamradio123`**
3. Browser öffnen: **http://192.168.4.1**
4. Hersteller ([ICOM](https://de.wikipedia.org/wiki/Icom)/YAESU), [CI-V](https://de.wikipedia.org/wiki/CI-V)-Adresse, Baudrate und Poti-Mapping konfigurieren
5. Speichern → Neustart

## Integration mit [flrig](https://github.com/w1hkj/flrig) / [Hamlib](https://en.wikipedia.org/wiki/Hamlib)

### [ESP32](https://de.wikipedia.org/wiki/ESP32) als [rigctld](https://hamlib.sourceforge.net/html/rigctld.1.html)-Server (PC steuert [ESP32](https://de.wikipedia.org/wiki/ESP32)/Radio)

Auf dem PC:

```bash
# Hamlib – direkt zum ESP32
rigctl -m 2 -r 192.168.4.1:4532 f      # Frequenz lesen
rigctl -m 2 -r 192.168.4.1:4532 F 14200000  # Frequenz setzen
```

In **[flrig](https://github.com/w1hkj/flrig)**: Rig → [Hamlib](https://en.wikipedia.org/wiki/Hamlib) → Modell **NET [rigctl](https://hamlib.sourceforge.net/html/rigctl.1.html) (2)**, Device: `192.168.x.x:4532`

### PC mit [flrig](https://github.com/w1hkj/flrig) als Server ([ESP32](https://de.wikipedia.org/wiki/ESP32) als Client)

1. [flrig](https://github.com/w1hkj/flrig) starten, XML-RPC-Server aktivieren (Port **12345**)
2. Im Web-UI des [ESP32](https://de.wikipedia.org/wiki/ESP32): Remote Host = PC-IP, Port = 12345
3. Alternativ auf dem PC:

```bash
rigctld -m 4 -r 192.168.x.x:12345 -t 4532
```

Dann verbinden andere Programme mit `localhost:4532`.

Referenz: [flrig XML-RPC Server](https://www.w1hkj.org/flrig-help/xmlrpc_server.html)

## Audio über [WiFi](https://de.wikipedia.org/wiki/WLAN) – Konfiguration

Hardware und Signalwege: Abschnitt [Audio IN und Audio OUT](#audio-in-und-audio-out-hardware--firmware).

### Aktivierung

1. Audio-Hardware nach Schaltplan verdrahten.
2. Web-UI: **Audio-Bridge aktiv** → Ports/Sample-Rate → speichern & neu starten.
3. Oder in `config.json`: `"audio_enabled": true`.

### Protokoll ([UDP](https://de.wikipedia.org/wiki/User_Datagram_Protocol) & WebSocket)

Mono **16-bit PCM**, Standard **48 [kHz](https://de.wikipedia.org/wiki/Hertz)** für [FT8](https://de.wikipedia.org/wiki/FT8_(Amateurfunk))/[WSJT-X](https://physics.princeton.edu/pulsar/k1jt/wsjtx.html) (in der Web-UI auch 16 [kHz](https://de.wikipedia.org/wiki/Hertz) möglich), Frames à **20 ms** (z. B. 960 Samples @ 48 [kHz](https://de.wikipedia.org/wiki/Hertz)).

Paketkopf (Little-Endian):

| Offset | Feld | Typ |
|---|---|-----|
| 0 | Magic `ESPA` | `uint32` = `0x45535041` |
| 4 | Sequenz | `uint32` |
| 8 | `nSamples` | `uint16` |
| 10 | PCM | `nSamples` × `int16` |

| Port | Richtung |
|---|---|
| **4533** (out) | ESP → Client (Radio-Empfang) |
| **4534** (in) | Client → ESP (Mikro zum Funk) |

Der ESP merkt sich die Client-IP nach dem ersten Paket auf Port **4534** und sendet Empfangsaudio an dieselbe IP auf Port **4533**.

### Client-Nutzung

**Browser** (Web Audio, kein Extra-Tool):

```
http://<ESP32-IP>/audio
```

**[Python](https://de.wikipedia.org/wiki/Python_(Programmiersprache))-[UDP](https://de.wikipedia.org/wiki/User_Datagram_Protocol)-Client** (PC mit Lautsprecher/Mikro):

```bash
pip install sounddevice numpy
python3 scripts/audio_client.py 192.168.4.1
# Ports anpassen: --port-out 4533 --port-in 4534
```

**WebSocket** (gleiches PCM-Format, binär): `ws://<ESP32-IP>/ws/audio`

### Hinweise

- Audio und [CAT](https://en.wikipedia.org/wiki/Computer_Aided_Transceiver) laufen parallel.
- Latenz hängt von [WiFi](https://de.wikipedia.org/wiki/WLAN) und Client-Puffer ab ([FT8](https://de.wikipedia.org/wiki/FT8_(Amateurfunk)): möglichst kurze Pfade, siehe unten).
- Ohne [I2S](https://de.wikipedia.org/wiki/I%C2%B2S)-Hardware die Bridge deaktiviert lassen (`audio_enabled: false`).

---

## [FT8](https://de.wikipedia.org/wiki/FT8_(Amateurfunk)) über [WiFi](https://de.wikipedia.org/wiki/WLAN) ([WSJT-X](https://physics.princeton.edu/pulsar/k1jt/wsjtx.html), [Windows](https://de.wikipedia.org/wiki/Microsoft_Windows) & [Linux](https://de.wikipedia.org/wiki/Linux))

Vollständiges [FT8](https://de.wikipedia.org/wiki/FT8_(Amateurfunk))-Fernbetreiben: **[CAT](https://en.wikipedia.org/wiki/Computer_Aided_Transceiver)** (Frequenz, [USB](https://de.wikipedia.org/wiki/Universal_Serial_Bus), **[PTT](https://de.wikipedia.org/wiki/Sende-Empfang-Umschaltung)**) über [rigctld](https://hamlib.sourceforge.net/html/rigctld.1.html) und **Audio** (I/Q-ähnlicher AF-Pfad) über [UDP](https://de.wikipedia.org/wiki/User_Datagram_Protocol). Getestet mit **[WSJT-X](https://physics.princeton.edu/pulsar/k1jt/wsjtx.html)** und [Hamlib](https://en.wikipedia.org/wiki/Hamlib) **NET [rigctl](https://hamlib.sourceforge.net/html/rigctl.1.html) (Modell 2)**.

```mermaid
flowchart LR
  subgraph pc["PC Windows / Linux"]
    WSJTX["WSJT-X"]
    BR["ft8_remote.py\n48 kHz Audio"]
  end
  subgraph esp["ESP32 Panel"]
    RIG["rigctld :4532"]
    AUD["Audio-Bridge\n:4533 / :4534"]
  end
  TRX["Funkgerät"]
  WSJTX -->|"Hamlib CAT"| RIG
  WSJTX -->|"Sound IN/OUT"| BR
  BR <-->|"UDP PCM"| AUD
  RIG <-->|"CI-V / CAT"| TRX
  AUD <-->|"Line I/O"| TRX
```

### Voraussetzungen

| Komponente | Pflicht |
|---|---|
| [ESP32](https://de.wikipedia.org/wiki/ESP32) mit **[CAT](https://en.wikipedia.org/wiki/Computer_Aided_Transceiver)** + **[I2S](https://de.wikipedia.org/wiki/I%C2%B2S)-Audio** (siehe Schaltplan) | ja |
| `audio_enabled: true`, `audio_sample_rate: 48000` | ja |
| PC im gleichen [WLAN](https://de.wikipedia.org/wiki/WLAN) wie ESP (oder ESP-AP) | ja |
| **Zeit sync** (NTP) auf PC für [FT8](https://de.wikipedia.org/wiki/FT8_(Amateurfunk)) | ja |
| Virtuelles oder [USB](https://de.wikipedia.org/wiki/Universal_Serial_Bus)-Audiogerät für [WSJT-X](https://physics.princeton.edu/pulsar/k1jt/wsjtx.html) | ja |

### 1. [ESP32](https://de.wikipedia.org/wiki/ESP32) vorbereiten

1. Firmware flashen (Web Flasher oder [PlatformIO](https://platformio.org/)).
2. Web-UI `http://192.168.4.1`: **Audio-Bridge aktiv**, Sample Rate **48000**, [CAT](https://en.wikipedia.org/wiki/Computer_Aided_Transceiver)/[ICOM](https://de.wikipedia.org/wiki/Icom)/[Yaesu](https://de.wikipedia.org/wiki/Yaesu) korrekt.
3. Funk: **[USB](https://de.wikipedia.org/wiki/Universal_Serial_Bus)**, **DATA-[USB](https://de.wikipedia.org/wiki/Universal_Serial_Bus)** oder **RTTY**-Filterbreite passend; **Line-Out → [INMP441](https://www.invensense.com/products/digital/inmp441/)**, **[PCM5102](https://www.ti.com/product/PCM5102) → Line-In** (nicht HS-Mic ohne Adapter).
4. AF-Pegel am Funk **moderat** ([FT8](https://de.wikipedia.org/wiki/FT8_(Amateurfunk)) overdrive vermeiden).

### 2. [CAT](https://en.wikipedia.org/wiki/Computer_Aided_Transceiver) in [WSJT-X](https://physics.princeton.edu/pulsar/k1jt/wsjtx.html) ([Windows](https://de.wikipedia.org/wiki/Microsoft_Windows) & [Linux](https://de.wikipedia.org/wiki/Linux) identisch)

| Einstellung | Wert |
|---|---|
| Rig | **[Hamlib](https://en.wikipedia.org/wiki/Hamlib) NET [rigctl](https://hamlib.sourceforge.net/html/rigctl.1.html)** |
| Rig model | **2** (Network [rigctl](https://hamlib.sourceforge.net/html/rigctl.1.html.1.html)) |
| Host | IP des [ESP32](https://de.wikipedia.org/wiki/ESP32), z. B. `192.168.4.1` |
| Port | `4532` |
| [PTT](https://de.wikipedia.org/wiki/Sende-Empfang-Umschaltung) method | **[CAT](https://en.wikipedia.org/wiki/Computer_Aided_Transceiver)** (nicht VOX für [FT8](https://de.wikipedia.org/wiki/FT8_(Amateurfunk))) |
| Mode | **[USB](https://de.wikipedia.org/wiki/Universal_Serial_Bus)** |
| Split | **OFF** (Firmware meldet Simplex) |

Test im Terminal:

```bash
rigctl -m 2 -r 192.168.4.1:4532 f
rigctl -m 2 -r 192.168.4.1:4532 t   # sollte 0 (RX) liefern
rigctl -m 2 -r 192.168.4.1:4532 T 1 # PTT an (Vorsicht: Senden!)
rigctl -m 2 -r 192.168.4.1:4532 T 0 # PTT aus
```

Der ESP unterstützt [Hamlib](https://en.wikipedia.org/wiki/Hamlib)-**[PTT](https://de.wikipedia.org/wiki/Sende-Empfang-Umschaltung) TX Data** (`T 3`) für [WSJT-X](https://physics.princeton.edu/pulsar/k1jt/wsjtx.html).

### 3. Audio-Bridge auf dem PC

```bash
pip install -r scripts/requirements-ft8.txt
python3 scripts/ft8_remote.py --list-devices
```

**Logik der Geräte:**

| Skript-Parameter | [WSJT-X](https://physics.princeton.edu/pulsar/k1jt/wsjtx.html) Einstellung | Signal |
|---|---|---|
| `--play-device` | **Input** (Reportinge) | Funk-Empfang vom ESP |
| `--rec-device` | **Output** (Transmit) | [FT8](https://de.wikipedia.org/wiki/FT8_(Amateurfunk))-TX zum ESP/Funk |

Beispiel (Geräte-IDs aus `--list-devices`):

```bash
python3 scripts/ft8_remote.py 192.168.4.1 --play-device 5 --rec-device 5
```

Getrennte virtuelle Kabel (empfohlen unter [Windows](https://de.wikipedia.org/wiki/Microsoft_Windows)):

1. [VB-Audio Virtual Cable](https://vb-audio.com/Cable/) oder zwei Ports eines [USB](https://de.wikipedia.org/wiki/Universal_Serial_Bus)-Interfaces.
2. `ft8_remote.py --play-device <Cable-A>` → [WSJT-X](https://physics.princeton.edu/pulsar/k1jt/wsjtx.html) **Input** = Cable-A.
3. [WSJT-X](https://physics.princeton.edu/pulsar/k1jt/wsjtx.html) **Output** = Cable-B → `ft8_remote.py --rec-device <Cable-B>`.

### 4. [Linux](https://de.wikipedia.org/wiki/Linux) ([PulseAudio](https://de.wikipedia.org/wiki/PulseAudio) / PipeWire)

Optional virtuelle Geräte:

```bash
chmod +x scripts/ft8_linux_pa.sh
./scripts/ft8_linux_pa.sh
pactl list sources short | grep -i esp32
```

Dann `ft8_remote.py` mit Monitor-Source des Null-Sinks als `--play-device` und [WSJT-X](https://physics.princeton.edu/pulsar/k1jt/wsjtx.html) Ausgang auf den TX-Loop-Sink legen. Alternativ ein physisches [USB-Audio](https://de.wikipedia.org/wiki/USB-Audioklasse)-Interface (einfacher).

### 5. [Windows](https://de.wikipedia.org/wiki/Microsoft_Windows) (Setup-Skript)

PowerShell **als Benutzer** (nicht zwingend Admin):

```powershell
cd C:\Pfad\zu\esp32-flrig
Set-ExecutionPolicy -Scope CurrentUser RemoteSigned -Force   # einmalig, falls nötig

# Komplett: VB-Audio prüfen/installieren, Geräte finden, Anleitung
.\scripts\ft8_windows_setup.ps1 -EspHost 192.168.4.1

# VB-Audio per winget installieren (oder Browser öffnet Download)
.\scripts\ft8_windows_setup.ps1 -InstallVbCable

# CAT testen + Audio-Bridge starten
.\scripts\ft8_windows_setup.ps1 -EspHost 192.168.4.1 -TestCat -StartBridge
```

Das Skript `scripts/ft8_windows_setup.ps1`:

| Schritt | Aktion |
|---|---|
| [Python](https://de.wikipedia.org/wiki/Python_(Programmiersprache)) | `pip install -r scripts/requirements-ft8.txt` |
| Treiber | Erkennt **[VB-Audio](https://vb-audio.com/Cable/) Virtual Cable**; optional `winget install` oder Link zu [vb-audio.com/Cable](https://vb-audio.com/Cable/) |
| Geräte | Listet sounddevice-Indizes; wählt **CABLE Input** (play) und **CABLE Output** (rec) |
| [WSJT-X](https://physics.princeton.edu/pulsar/k1jt/wsjtx.html) | Zeigt passende Radio/Audio-Einstellungen |
| Bridge | Mit `-StartBridge` startet `ft8_remote.py` in neuem Fenster |

**Zwei virtuelle Kabel** ([VB-Cable](https://vb-audio.com/Cable/) A + B): `.\scripts\ft8_windows_setup.ps1 -UseCableB`

Manuell ohne Skript:

```powershell
pip install -r scripts\requirements-ft8.txt
python scripts\ft8_remote.py 192.168.4.1 --list-devices
python scripts\ft8_remote.py 192.168.4.1 --play-device N --rec-device M
```

Sample Rate **48000 Hz** in [Windows](https://de.wikipedia.org/wiki/Microsoft_Windows)-Soundeinstellungen und [WSJT-X](https://physics.princeton.edu/pulsar/k1jt/wsjtx.html) prüfen.

### 6. Betrieb & [FT8](https://de.wikipedia.org/wiki/FT8_(Amateurfunk))-Checkliste

1. `ft8_remote.py` **vor** [WSJT-X](https://physics.princeton.edu/pulsar/k1jt/wsjtx.html) starten ([UDP](https://de.wikipedia.org/wiki/User_Datagram_Protocol)-Registrierung auf Port 4534).
2. [WSJT-X](https://physics.princeton.edu/pulsar/k1jt/wsjtx.html) öffnen, Frequenz/Modus vom Radio übernehmen ([CAT](https://en.wikipedia.org/wiki/Computer_Aided_Transceiver) verbunden).
3. **Waterfall** muss Rauschen/Zeilen zeigen → Audio IN ok.
4. Kurzer **Test-TX** mit niedriger Power: Ausgangsleistung/WAV-Form im Wasserfall prüfen.
5. **[PTT](https://de.wikipedia.org/wiki/Sende-Empfang-Umschaltung)** nur über [CAT](https://en.wikipedia.org/wiki/Computer_Aided_Transceiver)/[WSJT-X](https://physics.princeton.edu/pulsar/k1jt/wsjtx.html) – nicht gleichzeitig Hand-Mic-[PTT](https://de.wikipedia.org/wiki/Sende-Empfang-Umschaltung).

| Problem | Lösung |
|---|---|
| Kein Wasserfall | `audio_enabled`, [I2S](https://de.wikipedia.org/wiki/I%C2%B2S)-Verdrahtung, `ft8_remote` play-Device, Funk-AF > 0 |
| Kein TX / keine Power | `rec-device`, Line-In am Funk, Trimmer Pegel, [CAT](https://en.wikipedia.org/wiki/Computer_Aided_Transceiver)-[PTT](https://de.wikipedia.org/wiki/Sende-Empfang-Umschaltung) (`T 3`) |
| [CAT](https://en.wikipedia.org/wiki/Computer_Aided_Transceiver) timeout | [Level-Shifter](https://de.wikipedia.org/wiki/Pegelwandler), Baudrate, IP des ESP |
| [FT8](https://de.wikipedia.org/wiki/FT8_(Amateurfunk)) keine Dekodierung | PC-Uhrzeit (NTP), Frequenz-Offset, [USB](https://de.wikipedia.org/wiki/Universal_Serial_Bus)-Modus am TRX |
| Latenz / Timing | [WLAN](https://de.wikipedia.org/wiki/WLAN) kurz halten, block-ms 20, keine schweren [WiFi](https://de.wikipedia.org/wiki/WLAN)-Repeater |

### 7. Alternative: [fldigi](https://de.wikipedia.org/wiki/Fldigi) / andere Digimodes

Gleicher [CAT](https://en.wikipedia.org/wiki/Computer_Aided_Transceiver)-Port **4532**; Audio wie oben. Modus am Funk auf **[USB](https://de.wikipedia.org/wiki/Universal_Serial_Bus)/RTTY** stellen; [PTT](https://de.wikipedia.org/wiki/Sende-Empfang-Umschaltung) über [rigctl](https://hamlib.sourceforge.net/html/rigctl.1.html).

---

## [Potentiometer](https://de.wikipedia.org/wiki/Potentiometer) – frei programmierbar

Jeder der 5 [Potis](https://de.wikipedia.org/wiki/Potentiometer) kann über Web-UI oder `/config.json` konfiguriert werden:

| Aktion | Wirkung |
|---|---|
| `FREQ_COARSE` | Grobe Frequenzänderung (± [kHz](https://de.wikipedia.org/wiki/Hertz)) |
| `FREQ_FINE` | Feine Frequenzänderung (± Hz) |
| `AF_GAIN` | AF-Lautstärke (0.0–1.0) |
| `RF_POWER` | Sendeleistung |
| `RF_GAIN` | RF-Gain / AGC |
| `SQUELCH` | Squelch |
| `MIC_GAIN` | Mikrofonverstärkung |
| `RIT_OFFSET` | RIT-Offset |
| `CUSTOM_RIGCTL` | Eigener Befehl mit `{val}`-Platzhalter |

Beispiel `config.json`:

```json
{
  "pots": [
    {"action": "FREQ_COARSE", "min": -100000, "max": 100000, "step": 10000},
    {"action": "FREQ_FINE",   "min": -5000,   "max": 5000,   "step": 10},
    {"action": "AF_GAIN",     "min": 0.0,     "max": 1.0,    "step": 0.01},
    {"action": "RF_POWER",    "min": 0.0,     "max": 1.0,    "step": 0.01},
    {"action": "SQUELCH",     "min": 0.0,     "max": 1.0,    "step": 0.01}
  ]
}
```

## Unterstützte [Funkgeräte](https://de.wikipedia.org/wiki/Transceiver) ([CAT](https://en.wikipedia.org/wiki/Computer_Aided_Transceiver) + Audio)

In der **Web-Konfiguration** (`http://<ESP-IP>/`) wählen Sie das Modell – Baudrate, Protokoll ([ICOM](https://de.wikipedia.org/wiki/Icom) [CI-V](https://de.wikipedia.org/wiki/CI-V) / [Yaesu CAT](https://en.wikipedia.org/wiki/Computer_Aided_Transceiver)) und [CI-V](https://de.wikipedia.org/wiki/CI-V)-Adresse werden automatisch gesetzt.

| Hersteller | Modelle (Profil in Firmware) |
|---|---|
| **[Xiegu](https://www.xiegu.com/)** | G90, [X6100](https://www.xiegu.com/), [X6200](https://www.xiegu.com/) ([CI-V](https://de.wikipedia.org/wiki/CI-V), 19200, Addr **0xA4**) |
| **[Yaesu](https://de.wikipedia.org/wiki/Yaesu)** | FT-991A, FT-910, FT-DX10, FT-DX101D, FT-DX101MP, FT-891, FT-897, FT-857 |
| Referenz | [ICOM](https://de.wikipedia.org/wiki/Icom) IC-7300 |

Ausführliche Anschlüsse, [Hamlib](https://en.wikipedia.org/wiki/Hamlib)-Modellnamen und [FT8](https://de.wikipedia.org/wiki/FT8_(Amateurfunk))-Hinweise: **[docs/RADIOS.md](docs/RADIOS.md)**.

**[Xiegu](https://www.xiegu.com/):** [CI-V](https://de.wikipedia.org/wiki/CI-V) am Display/[USB](https://de.wikipedia.org/wiki/Universal_Serial_Bus) (nicht [Yaesu](https://de.wikipedia.org/wiki/Yaesu)-[CAT](https://en.wikipedia.org/wiki/Computer_Aided_Transceiver)). **[Yaesu](https://de.wikipedia.org/wiki/Yaesu):** [CAT](https://en.wikipedia.org/wiki/Computer_Aided_Transceiver)-Rate im Menü auf die Profil-Baudrate stellen (897/857 oft 4800).

## Unterstützte [CAT](https://en.wikipedia.org/wiki/Computer_Aided_Transceiver)-Befehle ([rigctld](https://hamlib.sourceforge.net/html/rigctld.1.html))

| Befehl | Funktion |
|---|---|
| `f` / `F` | Frequenz lesen/setzen |
| `m` / `M` | Modus lesen/setzen |
| `t` / `T` | [PTT](https://de.wikipedia.org/wiki/Sende-Empfang-Umschaltung) lesen/setzen |
| `l` / `L` | Level lesen/setzen (AF, RFPOWER) |
| `w` | Raw [CI-V](https://de.wikipedia.org/wiki/CI-V)/[CAT](https://en.wikipedia.org/wiki/Computer_Aided_Transceiver) (Hex) |
| `\get_info` | Geräteinfo |

## Touch-Display UI

- Frequenzanzeige ([MHz](https://de.wikipedia.org/wiki/Hertz))
- Modus ([USB](https://de.wikipedia.org/wiki/Universal_Serial_Bus)/LSB/CW/…)
- RX/TX-Status
- Tasten: +1 [kHz](https://de.wikipedia.org/wiki/Hertz) / −1 [kHz](https://de.wikipedia.org/wiki/Hertz)

## [ICOM](https://de.wikipedia.org/wiki/Icom) [CI-V](https://de.wikipedia.org/wiki/CI-V) Adressen (Beispiele)

| Radio | Adresse (hex) |
|---|---|
| IC-7300 | 0x94 |
| IC-705 | 0xA4 |
| IC-7610 | 0x98 |

## [Yaesu CAT](https://en.wikipedia.org/wiki/Computer_Aided_Transceiver)

Standard-ASCII-Befehle (`FA`, `MD`, `PC`, `AG`, `SQ`, `TX`). Baudrate meist **38400** (je nach Modell auch 4800 oder 9600).

## Projektstruktur

```
├── flasher/                # Web Flasher (index.html + firmware/)
├── scripts/
│   ├── build_flasher_assets.sh
│   ├── serve_flasher.sh
│   ├── ft8_remote.py         # WSJT-X Audio-Bridge (FT8)
│   ├── ft8_windows_setup.ps1 # Windows: VB-Audio + WSJT-X Setup
│   ├── ft8_linux_pa.sh       # PulseAudio-Hilfe Linux
│   ├── requirements-ft8.txt
│   └── flash.sh
├── platformio.ini          # Build-Konfiguration
├── docs/RADIOS.md          # Gerätetabelle CAT/Audio
├── include/                # Header
│   ├── config.h            # Pins, Enums
│   ├── icom_civ.h          # ICOM CI-V
│   ├── yaesu_cat.h         # Yaesu CAT
│   ├── cat_controller.h    # Unified CAT API
│   ├── rigctld_server.h    # Hamlib TCP server
│   ├── audio_bridge.h      # I2S ↔ UDP/WebSocket audio
│   ├── pot_manager.h       # Potentiometer logic
│   └── touch_ui.h          # LVGL UI
├── src/                    # Implementierung
└── data/config.json        # Default-Konfiguration
```

## Lizenz

GPL-2.0 (kompatibel mit [flrig](https://github.com/w1hkj/flrig)/[Hamlib](https://en.wikipedia.org/wiki/Hamlib)-Ökosystem)

## Weiterführende Links

- [flrig auf GitHub](https://github.com/w1hkj/flrig)
- [Hamlib rigctld Manual](https://hamlib.sourceforge.net/html/rigctld.1.html)
- [flrig XML-RPC Hilfe](https://www.w1hkj.org/flrig-help/xmlrpc_server.html)

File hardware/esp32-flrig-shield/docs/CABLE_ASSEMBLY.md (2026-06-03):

# Bauanleitung — [RJ45](https://de.wikipedia.org/wiki/RJ-45)-Y-Kabel zum [Funkgerät](https://de.wikipedia.org/wiki/Transceiver)

## Benötigt

| Teil | Menge |
|---|---|
| [RJ45](https://de.wikipedia.org/wiki/RJ-45)-Stecker (8P8C) | 1–2 |
| Cat-5e/6-Kabel, abgeschirmt | 1–3 m |
| 3,5 mm Mono- oder Stereo-Klinken | 2–3 |
| [CAT](https://en.wikipedia.org/wiki/Computer_Aided_Transceiver)-Adapterkabel (Gerät-spezifisch) | 1 |
| Schrumpfschlauch, Etiketten | — |

## Verdrahtung Funk-Ende (T568B-Farben → Funktion)

```
Pin 1 (ow)  ──► +5V   (nur wenn Funk 5V liefert — Strombedarf prüfen!)
Pin 2 (o)   ──► GND
Pin 3 (gw)  ──► Funk CAT TX (Daten vom Funk)
Pin 4 (g)   ──► Funk CAT RX (Daten zum Funk)
Pin 5 (bw)  ──► Funk LINE OUT / DATA OUT (+)
Pin 6 (b)   ──► Funk LINE IN / DATA IN (+)
Pin 7 (bw)  ──► GND (Audio-Masse, mit Pin 2 verbinden)
Pin 8 (br)  ──► offen (Reserve)
```

## Geräte-Hinweise

| Gerät | [CAT](https://en.wikipedia.org/wiki/Computer_Aided_Transceiver) | Audio RX | Audio TX |
|---|-----|---|---|
| [ICOM](https://de.wikipedia.org/wiki/Icom) IC-7300 | REMOTE 3,5 mm | ACC VARI OUT | ACC MODU IN |
| [Yaesu](https://de.wikipedia.org/wiki/Yaesu) FT-991A | [CAT](https://en.wikipedia.org/wiki/Computer_Aided_Transceiver) Mini-DIN | [USB](https://de.wikipedia.org/wiki/Universal_Serial_Bus) oder 1394 LINE OUT | LINE IN / [USB](https://de.wikipedia.org/wiki/Universal_Serial_Bus) |
| [Xiegu](https://www.xiegu.com/) G90 | Display-IO [CAT](https://en.wikipedia.org/wiki/Computer_Aided_Transceiver) | DATA OUT | [USB](https://de.wikipedia.org/wiki/Universal_Serial_Bus)/Mic |
| [Xiegu](https://www.xiegu.com/) [X6100](https://www.xiegu.com/)/[X6200](https://www.xiegu.com/) | [USB](https://de.wikipedia.org/wiki/Universal_Serial_Bus) Serial-B | [USB](https://de.wikipedia.org/wiki/Universal_Serial_Bus) Audio | [USB](https://de.wikipedia.org/wiki/Universal_Serial_Bus) Audio |

Bei **[USB](https://de.wikipedia.org/wiki/Universal_Serial_Bus)-only** Audio: [RJ45](https://de.wikipedia.org/wiki/RJ-45)-Pins 5/6 an **Line-Taps** eines [USB-Audio](https://de.wikipedia.org/wiki/Universal_Serial_Bus-Audioklasse)-Adapters oder an die **Interface-Platine** nur [CAT](https://en.wikipedia.org/wiki/Computer_Aided_Transceiver) (Pins 3/4) nutzen und Audio weiter über [WiFi](https://de.wikipedia.org/wiki/WLAN) (`ft8_remote.py`).

## Prüfung vor Inbetriebnahme

1. **Durchgang:** Pin 1↔1, 2↔2, … mit [Multimeter](https://de.wikipedia.org/wiki/Multimeter) (Kabel nicht am [PCB](https://de.wikipedia.org/wiki/Leiterplatte)).
2. **Kurzschluss:** 5V gegen GND ohne Last > 0,5 Ω → Fehler suchen.
3. **[CAT](https://en.wikipedia.org/wiki/Computer_Aided_Transceiver):** Baudrate im Funkmenü = Profil in ESP-Web-UI.
4. **Audio:** Ohne Funk, leises Rauschen auf AF_IN/AF_OUT normal.

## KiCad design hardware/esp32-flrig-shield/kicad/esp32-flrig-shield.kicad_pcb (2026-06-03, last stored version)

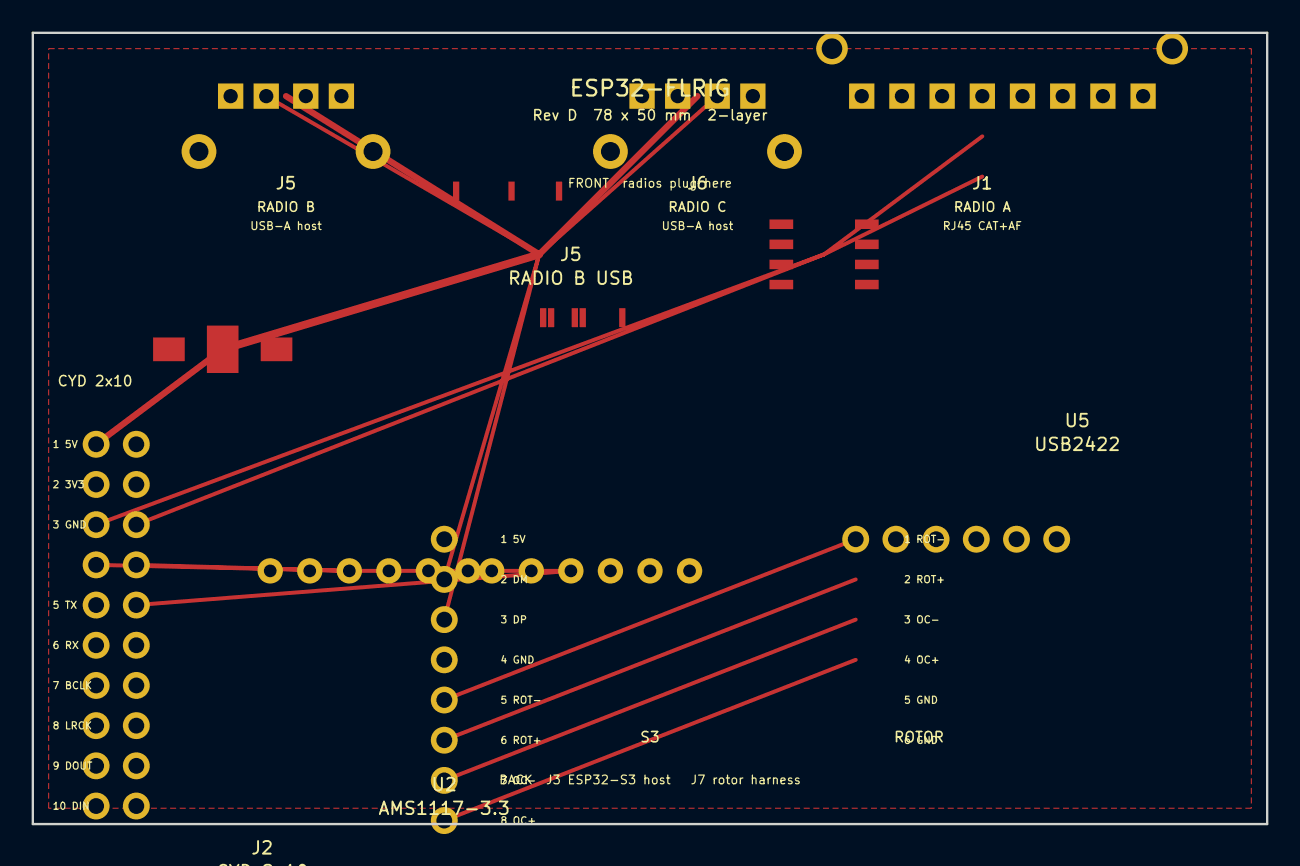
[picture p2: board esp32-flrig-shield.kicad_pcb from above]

Board: 2 copper layers, 78.0 x 50.0 mm, 11 parts (0 on the bottom side), 25 nets.

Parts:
J1: RADIO A; RJ45_RJHSE5080
J2: CYD 2x10; PinHeader_2x10_P2.54mm_Vertical
J3: ESP32-S3 HOST; PinHeader_1x08_P2.54mm_Vertical
J5: RADIO B USB; USB_A_Host_Receptacle_Vertical
J6: RADIO C USB; USB_A_Host_Receptacle_Vertical
J7: ROTOR; PinHeader_1x06_P2.54mm_Vertical
U1: ISO7741; SOIC-8_3.9x4.9mm_P1.27mm
U2: AMS1117-3.3; SOT-223-3_TabPin2
U3: PCM5102; PCM5102_Module_6pin
U4: INMP441; INMP441_Module_6pin
U5: USB2422; USB2422_SSOP

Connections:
+3V3: J2.2, U1.1, U2.3, U3.VCC, U4.VDD
+5V_BUS: J1.1, J2.1, J3.1, J5.VBUS, J6.VBUS, U1.8, U2.2, U5.8
AF_OUT: J1.6, U3.VOUT
CAT_ESP_RX: J2.6, U1.3
CAT_ESP_TX: J2.5, U1.2
CAT_RX_RADIO: J1.4, U1.6
CAT_TX_RADIO: J1.3, U1.7
GND_ESP: J2.3, J2.4, J2.11, J2.12, J2.13, J2.14, J2.15, J2.16, J2.17, J2.18, J2.19, J2.20, J3.4, J7.5, J7.6, U1.4, U2.1, U3.GND, U4.GND, U4.LR, U5.1
GND_RADIO_A: J1.2, J1.7, J1.SH, U1.5
GND_USB_B: J5.GND, J5.SH
GND_USB_C: J6.GND, J6.SH
I2S_BCLK: J2.7, U3.BCK, U4.SCK
I2S_DIN: J2.10, U4.SD
I2S_DOUT: J2.9, U3.DIN
I2S_LRCK: J2.8, U3.LRCK, U4.WS
ROTOR_BTN_CCW: J3.5, J7.1
ROTOR_BTN_CW: J3.6, J7.2
ROTOR_OC_CCW: J3.7, J7.3
ROTOR_OC_CW: J3.8, J7.4
USB_DM_D1: J5.D-, U5.21
USB_DM_D2: J6.D-, U5.25
USB_DP_D1: J5.D+, U5.20
USB_DP_D2: J6.D+, U5.24
USB_OTG_DM: J3.2, U5.15
USB_OTG_DP: J3.3, U5.14

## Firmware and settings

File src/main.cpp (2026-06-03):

#include <Arduino.h>
#include <WiFi.h>
#include "config.h"
#include "config_store.h"
#include "radio_channel.h"
#include "rotctld_server.h"
#include "rotor_controller.h"
#include "pot_manager.h"
#include "touch_ui.h"
#include "web_config.h"

static AppConfig           g_cfg;
static ConfigStore         g_store;
static RadioChannelManager g_radios;
static HamlibTcpServer     g_rotctld;
static RotorController     g_rotor;
static PotManager          g_pots;
static TouchUI             g_ui;
static WebConfig           g_web;

static uint32_t g_lastPoll = 0;

static void setupWiFi() {
    if (g_cfg.wifiSsid[0] != '\0') {
        WiFi.mode(WIFI_STA);
        WiFi.begin(g_cfg.wifiSsid, g_cfg.wifiPass);
        Serial.printf("[wifi] connecting to %s", g_cfg.wifiSsid);
        for (int i = 0; i < 30 && WiFi.status() != WL_CONNECTED; i++) {
            delay(500);
            Serial.print('.');
        }
        Serial.println();
        if (WiFi.status() == WL_CONNECTED) {
            Serial.printf("[wifi] IP: %s\n", WiFi.localIP().toString().c_str());
            return;
        }
    }

    WiFi.mode(WIFI_AP);
    WiFi.softAP(WIFI_AP_SSID, WIFI_AP_PASS);
    Serial.printf("[wifi] AP mode: %s / %s → %s\n",
                  WIFI_AP_SSID, WIFI_AP_PASS, WiFi.softAPIP().toString().c_str());
}

static void onConfigSaved(const AppConfig& cfg) {
    g_store.save(cfg);
}

static void onStateChange(const RadioState& state) {
    g_ui.updateState(state);
}

void setup() {
    Serial.begin(115200);
    delay(500);
    Serial.printf("\n=== ESP32 CAT Remote Panel (%d Funk) ===\n", RADIO_COUNT);

    g_store.begin();
    g_store.load(g_cfg);

    setupWiFi();

    g_radios.cat(0).onStateChange(onStateChange);
    g_radios.begin(g_cfg);

    g_rotor.begin(g_cfg);
    g_rotctld.begin(g_cfg.rotctldPort, "rotctld");
    g_rotctld.setHandler([](const String& cmd) -> String {
        return dispatchRotctl(cmd, g_rotor, &g_cfg);
    });

    g_pots.begin(g_cfg.pots);

    g_ui.setCatController(&g_radios.cat(0));
    g_ui.begin();
    g_ui.updateState(g_radios.cat(0).state());

    g_web.begin(&g_cfg, onConfigSaved);
    g_web.attachRadioAudio(&g_radios);

    IPAddress ip = WiFi.localIP();
    if (!ip) ip = WiFi.softAPIP();

    for (int i = 0; i < RADIO_COUNT; i++) {
        if (!g_cfg.radios[i].enabled) continue;
        Serial.printf("[rigctld-%s] rigctl -m 2 -r %s:%u\n",
                      g_cfg.radios[i].label, ip.toString().c_str(),
                      g_cfg.radios[i].rigctldPort);
    }
    if (g_cfg.rotorEnabled) {
        Serial.printf("[rotctld] rotctl -m 2 -r %s:%d\n",
                      ip.toString().c_str(), g_cfg.rotctldPort);
    }
    Serial.println("[web] config UI: http://" + ip.toString());
    if (g_cfg.radios[0].audioEnabled)
        Serial.println("[audio-A] http://" + ip.toString() + "/audio");
#if RADIO_COUNT > 1
    if (g_cfg.radios[1].audioEnabled)
        Serial.println("[audio-B] http://" + ip.toString() + "/audio_b");
#endif
#if RADIO_COUNT > 2
    if (g_cfg.radios[2].audioEnabled)
        Serial.println("[audio-C] http://" + ip.toString() + "/audio_c");
#endif
}

void loop() {
    g_radios.loop();
    g_rotctld.loop();
    g_rotor.loop();
    g_pots.loop(g_radios.cat(0), g_radios.cat(0).state());
    g_ui.loop();

    if (millis() - g_lastPoll > 1000) {
        g_lastPoll = millis();
        uint64_t hz = 0;
        if (g_radios.cat(0).getFrequency(hz)) {
            RadioState st = g_radios.cat(0).state();
            g_ui.updateState(st);
        }
    }
}

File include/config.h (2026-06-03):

#pragma once

#include <Arduino.h>

// CAT = Computer Aided Transceiver (ICOM/Yaesu control), not shared ground between rigs.

// ── WiFi / rigctld ──────────────────────────────────────────────────────────
#define WIFI_AP_SSID        "ESP32-CAT-Panel"
#define WIFI_AP_PASS        "hamradio123"
#define RIGCTLD_PORT        4532   // Funk A (Hamlib NET rigctl)
#define RIGCTLD_PORT_B      4536   // Funk B
#define RIGCTLD_PORT_C      4540   // Funk C
#define ROTCTLD_PORT        4535   // Hamlib rotctld (nicht 4533 = Audio-UDP)
#ifndef RADIO_COUNT
  #if defined(BOARD_FLRIG_SHIELD) || defined(BOARD_TRIPLE_RADIO)
    #define RADIO_COUNT     3
  #elif defined(BOARD_DUAL_RADIO)
    #define RADIO_COUNT     2
  #else
    #define RADIO_COUNT     1
  #endif
#endif
#define WEB_CONFIG_PORT     80
#define FLRIG_XMLRPC_PORT   12345

// ── WiFi-Audio (I2S ↔ UDP/WebSocket) ───────────────────────────────────────
#define AUDIO_PORT_OUT      4533   // Funk A: ESP → Client
#define AUDIO_PORT_IN       4534   // Funk A: Client → ESP
#define AUDIO_PORT_OUT_B    4538   // Funk B
#define AUDIO_PORT_IN_B     4539
#define AUDIO_PORT_OUT_C    4541   // Funk C
#define AUDIO_PORT_IN_C     4542
#define AUDIO_WS_PATH       "/ws/audio"
#define AUDIO_SAMPLE_RATE   48000   // Standard für WSJT-X / FT8 (16000 in config möglich)
#define AUDIO_FRAME_MS      20
#define AUDIO_FRAME_SAMPLES_MAX 960  // 20 ms @ 48 kHz
#define AUDIO_MAGIC         0x45535041u  // 'ESPA'

inline uint16_t audioFrameSamples(uint32_t sampleRateHz) {
    return (uint16_t)(sampleRateHz * AUDIO_FRAME_MS / 1000);
}

#ifdef BOARD_CYD
  #define I2S_BCLK_PIN        26
  #define I2S_LRCK_PIN        25
  #define I2S_DOUT_PIN        22   // ESP → DAC → Funk-Mic/Line-In
  #define I2S_DIN_PIN         4    // ADC → ESP ← Funk-Line-Out/SPKR
#elif defined(BOARD_TDISPLAY)
  #define I2S_BCLK_PIN        12
  #define I2S_LRCK_PIN        13
  #define I2S_DOUT_PIN        14
  #define I2S_DIN_PIN         15
#else
  #define I2S_BCLK_PIN        26
  #define I2S_LRCK_PIN        25
  #define I2S_DOUT_PIN        22
  #define I2S_DIN_PIN         4
#endif

// Zweiter I2S-Bus (Funk B) – nur wenn 2× Audio per I2S
#ifdef BOARD_S3_USB_HOST
  #define I2S1_BCLK_PIN       12
  #define I2S1_LRCK_PIN       13
  #define I2S1_DOUT_PIN       14
  #define I2S1_DIN_PIN        15
#elif defined(BOARD_CYD)
  #define I2S1_BCLK_PIN       12
  #define I2S1_LRCK_PIN       13
  #define I2S1_DOUT_PIN       14
  #define I2S1_DIN_PIN        15
#endif

#ifdef BOARD_FLRIG_SHIELD
  /* ESP32-S3 DevKitC-1 + Rev-B Shield (J3) */
  #define CAT_RX_PIN          16
  #define CAT_TX_PIN          17
  #define ROTOR_BTN_CCW_DEFAULT   27
  #define ROTOR_BTN_CW_DEFAULT    5
  #define ROTOR_OC_CCW_DEFAULT    18
  #define ROTOR_OC_CW_DEFAULT     19
#endif

// ── Radio UART (CAT) ────────────────────────────────────────────────────────
#ifdef BOARD_TDISPLAY
  // GPIO16 = TFT_DC on TTGO T-Display – CAT auf freie Header-Pins
  #define CAT_RX_PIN          27
  #define CAT_TX_PIN          17
#else
  #define CAT_RX_PIN          16
  #define CAT_TX_PIN          17
#endif
// Funk B UART (TTL), wenn nicht USB
#ifndef CAT_B_RX_PIN
  #define CAT_B_RX_PIN        5
  #define CAT_B_TX_PIN        18
#endif
#define CAT_BAUD_ICOM       19200
#define CAT_BAUD_YAESU      38400
#define CAT_DEFAULT_BAUD    38400

// ── Potentiometer ADC pins (GPIO, 12-bit) ─────────────────────────────────
#define POT_COUNT           5
#ifdef BOARD_CYD
  // GPIO33 = Touch CS on CYD – nicht für Potis verwenden
  static const uint8_t POT_PINS[POT_COUNT] = {32, 35, 34, 39, 36};
#elif defined(BOARD_TDISPLAY)
  static const uint8_t POT_PINS[POT_COUNT] = {32, 33, 25, 26, 34};
#else
  static const uint8_t POT_PINS[POT_COUNT] = {32, 33, 34, 35, 36};
#endif

#define POT_DEADZONE        8      // raw ADC steps
#define POT_POLL_MS         50
#define POT_SMOOTH_SAMPLES  4

// ── Rotor (Hamlib rotctld + GPIO, Open-Collector-Ausgänge) ─────────────────
// Extern: NPN/Open-Collector + Relais + Freilaufdiode. GPIO LOW = Relais ein.
#ifdef BOARD_CYD
  #define ROTOR_BTN_CCW_DEFAULT   27
  #define ROTOR_BTN_CW_DEFAULT    5
  #define ROTOR_OC_CCW_DEFAULT    18
  #define ROTOR_OC_CW_DEFAULT     19
#elif defined(BOARD_TDISPLAY)
  #define ROTOR_BTN_CCW_DEFAULT   12
  #define ROTOR_BTN_CW_DEFAULT    13
  #define ROTOR_OC_CCW_DEFAULT    21
  #define ROTOR_OC_CW_DEFAULT     22
#else
  #define ROTOR_BTN_CCW_DEFAULT   27
  #define ROTOR_BTN_CW_DEFAULT    5
  #define ROTOR_OC_CCW_DEFAULT    18
  #define ROTOR_OC_CW_DEFAULT     19
#endif
#define ROTOR_SPEED_DEFAULT       50
#define ROTOR_DEBOUNCE_MS_DEFAULT 40
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

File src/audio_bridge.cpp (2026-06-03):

#include "audio_bridge.h"
#include <WiFi.h>
#include <driver/i2s.h>
#include <AsyncWebSocket.h>
#include <cstring>

static const char AUDIO_PAGE[] PROGMEM = R"rawliteral(
<!DOCTYPE html>
<html lang="de">
<head>
<meta charset="UTF-8">
<meta name="viewport" content="width=device-width,initial-scale=1">
<title>ESP32 Audio Bridge</title>
<style>
body{font-family:sans-serif;background:#1a1a2e;color:#eee;margin:1em;max-width:480px}
h1{color:#00ff88}button{background:#00ff88;color:#111;border:none;padding:.6em 1.2em;cursor:pointer;margin:.5em .5em 0 0}
#st{margin-top:1em;color:#aaa}
</style>
</head>
<body>
<h1>Audio Bridge</h1>
<p>Empfang vom Funk → Browser · Mikrofon → Funk-Mic/Line-In</p>
<button id="start">Verbinden</button>
<button id="stop" disabled>Trennen</button>
<p id="st">Bereit</p>
<script>
const SR=48000,FRAME=960;
let ws,ctx,playNode,proc,micStream,seq=0;
const st=document.getElementById('st');
function log(m){st.textContent=m;}
document.getElementById('start').onclick=async()=>{
  ctx=new AudioContext({sampleRate:SR});
  const proto=location.protocol==='https:'?'wss:':'ws:';
  const p=location.pathname;
  const wspath=p.indexOf('_c')>=0?'/ws/audio_c':(p.indexOf('_b')>=0?'/ws/audio_b':'/ws/audio');
  ws=new WebSocket(proto+'//'+location.host+wspath);
  ws.binaryType='arraybuffer';
  ws.onopen=async()=>{
    log('WebSocket verbunden');
    micStream=await navigator.mediaDevices.getUserMedia({audio:{sampleRate:SR,channelCount:1,echoCancellation:true},video:false});
    const src=ctx.createMediaStreamSource(micStream);
    proc=ctx.createScriptProcessor(FRAME,1,1);
    proc.onaudioprocess=e=>{
      if(ws.readyState!==1)return;
      const f=e.inputBuffer.getChannelData(0);
      const pcm=new Int16Array(FRAME);
      for(let i=0;i<FRAME;i++)pcm[i]=Math.max(-32768,Math.min(32767,f[i]*32767|0));
      const hdr=new ArrayBuffer(10);
      const dv=new DataView(hdr);
      dv.setUint32(0,0x45535041,true);
      dv.setUint32(4,seq++,true);
      dv.setUint16(8,FRAME,true);
      const out=new Uint8Array(10+FRAME*2);
      out.set(new Uint8Array(hdr),0);
      out.set(new Uint8Array(pcm.buffer),10);
      ws.send(out.buffer);
    };
    src.connect(proc);proc.connect(ctx.destination);
    playNode=ctx.createScriptProcessor(FRAME,1,1);
    playNode.onaudioprocess=e=>{
      const o=e.outputBuffer.getChannelData(0);
      if(!playNode._q||!playNode._q.length){o.fill(0);return;}
      const pcm=playNode._q.shift();
      for(let i=0;i<FRAME;i++)o[i]=pcm[i]/32768;
    };
    playNode._q=[];
    playNode.connect(ctx.destination);
    ws.onmessage=ev=>{
      const u=new Uint8Array(ev.data);
      if(u.length<10)return;
      const dv=new DataView(u.buffer,u.byteOffset,u.byteLength);
      if(dv.getUint32(0,true)!==0x45535041)return;
      const n=dv.getUint16(8,true);
      const pcm=new Float32Array(n);
      for(let i=0;i<n;i++)pcm[i]=dv.getInt16(10+i*2,true)/32768;
      if(playNode._q.length<8)playNode._q.push(pcm);
    };
    document.getElementById('start').disabled=true;
    document.getElementById('stop').disabled=false;
  };
  ws.onclose=()=>log('Getrennt');
  ws.onerror=()=>log('WebSocket-Fehler');
};
document.getElementById('stop').onclick=()=>{
  if(ws)ws.close();
  if(micStream)micStream.getTracks().forEach(t=>t.stop());
  if(ctx)ctx.close();
  document.getElementById('start').disabled=false;
  document.getElementById('stop').disabled=true;
  log('Bereit');
};
</script>
</body>
</html>
)rawliteral";

bool AudioBridge::begin(const RadioChannelConfig* ch, uint8_t channelIndex) {
    _ch = ch;
    _channelIndex = channelIndex;
    if (!ch || !ch->audioEnabled) {
        Serial.printf("[audio-%s] disabled\n", ch ? ch->label : "?");
        return true;
    }

    if (ch->audioLink == AudioLinkType::USB_UAC) {
        Serial.printf("[audio-%s] USB-UAC: S3 Host + Hub (Treiber folgt)\n", ch->label);
        return true;
    }

    _frameSamples = audioFrameSamples(ch->audioSampleRate);
    if (_frameSamples == 0 || _frameSamples > AUDIO_FRAME_SAMPLES_MAX)
        _frameSamples = audioFrameSamples(AUDIO_SAMPLE_RATE);

    if (!initI2s()) {
        Serial.printf("[audio-%s] I2S init failed\n", ch->label);
        return false;
    }

    if (!_udpIn.begin(ch->audioPortIn)) {
        Serial.printf("[audio-%s] UDP in :%u bind failed\n", ch->label, ch->audioPortIn);
        return false;
    }

    _running = true;
    char taskName[12];
    snprintf(taskName, sizeof(taskName), "audio%c", ch->label[0]);
    xTaskCreatePinnedToCore(taskEntry, taskName, 12288, this, 1, nullptr, 0);

    Serial.printf("[audio-%s] UDP out:%u in:%u %lu Hz I2S%d\n",
                  ch->label, ch->audioPortOut, ch->audioPortIn,
                  (unsigned long)ch->audioSampleRate, (int)_i2sPort);
    return true;
}

void AudioBridge::attachToServer(AsyncWebServer* server) {
    if (!server || !_ch || !_ch->audioEnabled || !_running) return;

    const char* pagePath = "/audio";
    const char* wsPath = AUDIO_WS_PATH;
    if (_channelIndex == 1) {
        pagePath = "/audio_b";
        wsPath = "/ws/audio_b";
    } else if (_channelIndex == 2) {
        pagePath = "/audio_c";
        wsPath = "/ws/audio_c";
    }

    server->on(pagePath, HTTP_GET, [](AsyncWebServerRequest* req) {
        req->send_P(200, "text/html", AUDIO_PAGE);
    });

    _ws = new AsyncWebSocket(wsPath);
    AudioBridge* self = this;
    _ws->onEvent([self](AsyncWebSocket* ws, AsyncWebSocketClient* client,
                        AwsEventType type, void* arg, uint8_t* data, size_t len) {
        if (!self->_running) return;
        if (type == WS_EVT_CONNECT) {
            Serial.printf("[audio-%s] WS %s\n", self->_ch->label,
                          client->remoteIP().toString().c_str());
        } else if (type == WS_EVT_DISCONNECT) {
            (void)ws;
        } else if (type == WS_EVT_DATA && arg) {
            AwsFrameInfo* info = (AwsFrameInfo*)arg;
            if (info->opcode == WS_BINARY && info->index == 0 && info->final)
                self->onClientAudio(data, len, true);
        }
    });
    server->addHandler(_ws);
}
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

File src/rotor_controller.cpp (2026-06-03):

#include "rotor_controller.h"

void RotorController::setOc(uint8_t pin, bool active) {
    if (pin == 255) return;
    // Open collector: LOW = Treiber aktiv (Relais ein), HIGH = aus
    digitalWrite(pin, active ? LOW : HIGH);
}

void RotorController::applyOutputs() {
    if (!_enabled) return;
    bool left  = (_state.moving & RotorDir::LEFT) != 0;
    bool right = (_state.moving & RotorDir::RIGHT) != 0;
    // Azimut: CCW = links, CW = rechts
    setOc(_ocCcw, left);
    setOc(_ocCw, right);
}

bool RotorController::begin(const AppConfig& cfg) {
    _enabled = cfg.rotorEnabled;
    _btnCcw = cfg.rotorBtnCcw;
    _btnCw  = cfg.rotorBtnCw;
    _ocCcw  = cfg.rotorOcCcw;
    _ocCw   = cfg.rotorOcCw;
    _debounceMs = cfg.rotorDebounceMs;
    _state.speed = cfg.rotorSpeed;

    if (!_enabled) {
        Serial.println("[rotor] disabled");
        return true;
    }

    pinMode(_btnCcw, INPUT_PULLUP);
    pinMode(_btnCw, INPUT_PULLUP);
    pinMode(_ocCcw, OUTPUT_OPEN_DRAIN);
    pinMode(_ocCw, OUTPUT_OPEN_DRAIN);
    setOc(_ocCcw, false);
    setOc(_ocCw, false);

    _btnCcwLast = digitalRead(_btnCcw) == HIGH;
    _btnCwLast  = digitalRead(_btnCw) == HIGH;

    Serial.printf("[rotor] btn CCW=%u CW=%u OC CCW=%u CW=%u (open drain)\n",
                  _btnCcw, _btnCw, _ocCcw, _ocCw);
    return true;
}

void RotorController::loop() {
    if (!_enabled) return;

    uint32_t now = millis();
    if (now - _lastBtnMs < _debounceMs) return;

    bool ccw = digitalRead(_btnCcw) == LOW;
    bool cw  = digitalRead(_btnCw) == LOW;

    if (ccw != _btnCcwLast || cw != _btnCwLast) {
        _lastBtnMs = now;
        _btnCcwLast = ccw;
        _btnCwLast = cw;

        if (ccw && !cw)
            move(RotorDir::LEFT, _state.speed);
        else if (cw && !ccw)
            move(RotorDir::RIGHT, _state.speed);
        else if (!ccw && !cw)
            stop();
        // beide gedrückt → stop (Sicherheit)
        else
            stop();
    }
}

bool RotorController::move(int direction, int speed) {
    if (!_enabled) return false;
    if (speed < 1) speed = 1;
    if (speed > 100) speed = 100;
    _state.speed = speed;
    _state.moving = direction & (RotorDir::LEFT | RotorDir::RIGHT | RotorDir::UP | RotorDir::DOWN);
    if (_state.moving == 0) {
        stop();
        return true;
    }
    applyOutputs();
    return true;
}

void RotorController::stop() {
    _state.moving = 0;
    applyOutputs();
}

bool RotorController::park() {
    stop();
    return true;
}

bool RotorController::setPosition(float az, float el) {
    stop();
    _state.azimuth = az;
    _state.elevation = el;
    return true;
}

void RotorController::getPosition(float& az, float& el) const {
    az = _state.azimuth;
    el = _state.elevation;
}

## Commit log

2026-06-03 Rotor Implementation, audio bridge and more tranceivers
    [BOM_JLCPCB.csv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]
2026-06-03 some bugfixes
    [BOM_JLCPCB.csv, esp32-flrig-shield.kicad_pcb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]
2026-06-03 some bugfixes with images and pcb, aswell as linking to the sources of knowledge
    [fix_broken_slash_links.py, fix_nested_markdown_links.py, link_glossary_terms.py]
2026-06-03 minor correction
    [esp32-flrig-shield.kicad_pcb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]
2026-06-03 remove pcb
    [BOM_JLCPCB.csv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]
